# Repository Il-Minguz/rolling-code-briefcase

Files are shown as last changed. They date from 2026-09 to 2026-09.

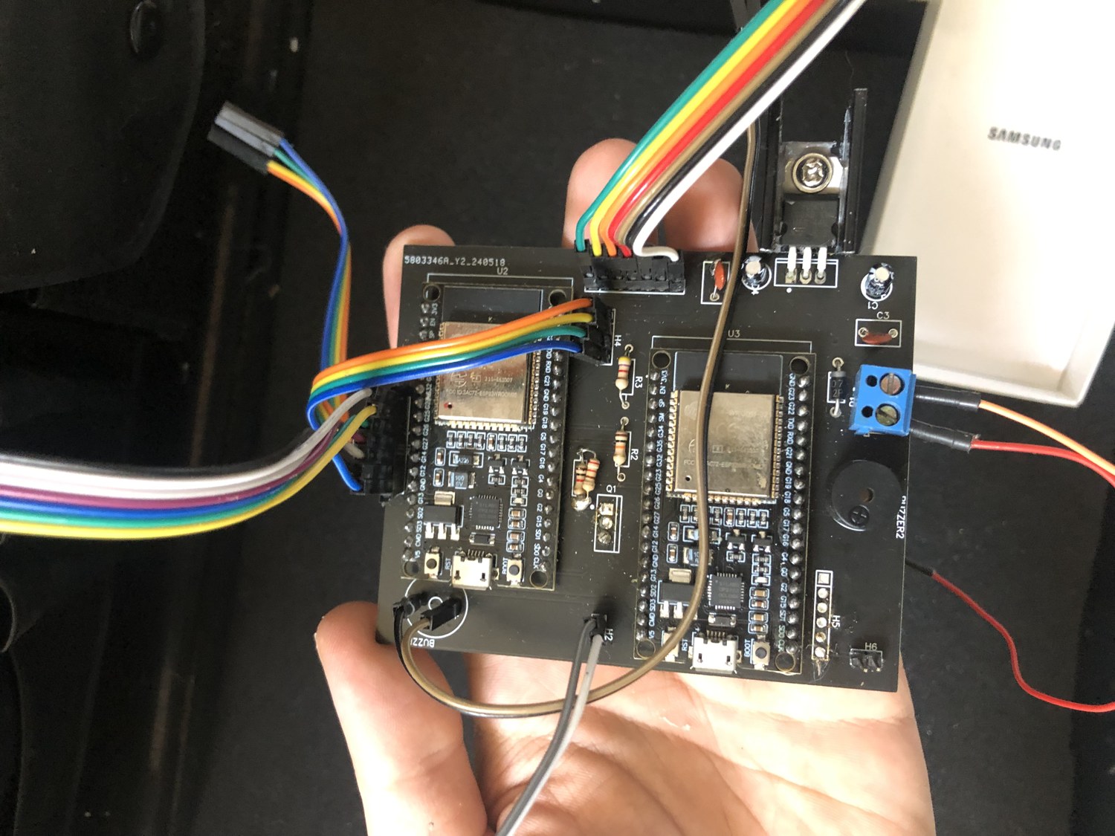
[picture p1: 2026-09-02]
hardware/pcb-v2-through-hole/photos/pcb-assembled.jpg

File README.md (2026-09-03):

# Rolling-Code Briefcase

An ESP32 briefcase that unlocks with a one-time code delivered over a 433 MHz LoRa link, or
with a fingerprint when the radio link goes down. Built as a final high-school project in
2024 — documented honestly in 2026, mistakes included.

---

## Overview - Work it harder 👷🏻‍♂️

This was one of my final high-school projects. Looking back at it today there are several
things I would design differently, but it was also the first time I combined embedded
programming, wireless communication, biometrics, PCB design and hardware debugging into a
single system that had to actually work in front of an examination board.

The system is made of two physical units:

- **The briefcase.** An aluminium case containing two ESP32s on a custom PCB, a 4×3 keypad, an
  SH1106 OLED, a GROW R557 capacitive fingerprint sensor behind a key-operated switch, an
  EBYTE E32-433T30D LoRa module, two buzzers and a solenoid lock.
- **The code transmitter.** A separate metal box with a third ESP32, a 16×2 I²C LCD and a
  second E32-433T30D. It generates a new 5-digit code every time the briefcase is opened and
  displays it.

Enter the code shown on the transmitter, press `#`, the case opens and a fresh code is
generated. Walk out of radio range and the keypad goes dead: the OLED tells you to use the
fingerprint sensor instead, which only works once you have turned a physical key.

This repository is **not** a build guide for a secure product. It is a record of what I built with the knowledge available at the time, what actually worked, what did not.

> [!WARNING]
> **Do not use this to secure anything.** The unlock code is transmitted in clear text on a
> default LoRa address and channel, there is no attempt limit, and the radio module is
> configured for 1 W of output power, which is far above what is legal in the 433 MHz band in
> Europe. Details in [Security](#security-honestly) and [Disclaimer](#disclaimer).

---

## 📖 Table of Contents

*(There is toooooo much to scroll here click around instead.)*

- [Overview](#overview)
- [Background](#background)
- [Inspiration](#inspiration)
- [Features](#features)
- [System Architecture](#system-architecture)
  - [Data flow, as implemented](#data-flow-as-implemented)
- [Hardware](#hardware)
  - [Pin mapping](#pin-mapping)
- [Software](#software)
  - [Why three microcontrollers](#why-three-microcontrollers)
- [Authentication System](#authentication-system)
  - [Security, honestly](#security-honestly)
- [Wireless Communication](#wireless-communication)
  - [Correction: the frequency was 433.0 MHz, not 450 MHz](#correction-the-frequency-was-4330-mhz-not-450-mhz)
  - [Correction: the −148 dBm figure does not apply](#correction-the-148-dbm-figure-does-not-apply)
  - [Protocol](#protocol)
  - [The data structure — and the bug that never went off](#the-data-structure--and-the-bug-that-never-went-off)
  - [And a second one: no framing](#and-a-second-one-no-framing)
- [Range: what the report claimed, and what actually happened](#range-what-the-report-claimed-and-what-actually-happened)
  - [About the test table in the report](#about-the-test-table-in-the-report)
  - [Range was never the binding constraint](#range-was-never-the-binding-constraint)
  - [The failure shape is the clue](#the-failure-shape-is-the-clue)
  - [The other strong candidate: the radio was probably never transmitting 1 W](#the-other-strong-candidate-the-radio-was-probably-never-transmitting-1-w)
  - [Ranked, then](#ranked-then)
  - [The distinction I got wrong](#the-distinction-i-got-wrong)
- [Lock Control](#lock-control)
  - [Why the base drive could not work](#why-the-base-drive-could-not-work)
  - [The power supply was wrong too](#the-power-supply-was-wrong-too)
  - [What the lock actually ran on, in the end](#what-the-lock-actually-ran-on-in-the-end)
- [Original Workarounds](#original-workarounds)
  - [LED + photoresistor optocoupler](#led--photoresistor-optocoupler)
  - [Others](#others)
- [Power System](#power-system)
- [Custom PCB](#custom-pcb)
- [Known Issues and Limitations](#known-issues-and-limitations)
  - [On the fingerprint sensor "binding itself" to one ESP32](#on-the-fingerprint-sensor-binding-itself-to-one-esp32)
- [What I Would Do Differently Today](#what-i-would-do-differently-today)
- [Lessons Learned](#lessons-learned)
- [Repository Structure](#repository-structure)
- [How to Reproduce or Experiment with the Project](#how-to-reproduce-or-experiment-with-the-project)
- [Disclaimer](#disclaimer)
- [Credits and Inspiration](#credits-and-inspiration)
- [License](#license)

---
## Background

Italian high schools end with the *Esame di Stato*, and technical institutes expect (in 2024) a personal
project alongside the written exams. I wanted something that touched the disciplines that are the most interesting such as radio, embedded firmware, power electronics
and a board I had designed myself.

The case itself is my father's old aluminium attaché case, the kind with a three-digit
mechanical combination lock on the lid. That lock is still there and still works — everything
in this repository was added around it.

The original report is preserved, unedited, in
[`docs/original-report/`](docs/original-report/). It is in Italian, it is 33 pages long, and
parts of it are wrong. Rather than quietly correcting it, I have kept it as it was and written
[`docs/ORIGINAL_REPORT_REVIEW.md`](docs/ORIGINAL_REPORT_REVIEW.md), which goes through its
claims one by one and marks each as confirmed, imprecise, or wrong.

---

## Inspiration

The original idea came from this YouTube short:

**https://www.youtube.com/shorts/WOgwcFSCKto**

That video is where the concept of a remotely controlled locking case came from, and it
deserves the credit for the spark. It used an NRF24-based link and a
large LiPo pack of the kind used in airsoft replicas. My implementation went a different way
almost immediately: ESP32s instead of an arduino nano, EBYTE LoRa modules instead of NRF24, plus
biometric authentication and a custom PCB.

**What I was actually imagining** (to Make it better 💻🔨)

The honest answer to "why a briefcase" is that I was picturing something out of a spy film: a courier case carrying documents that must not be read,
which opens only for the right person, reports back the moment it is opened, and whose code changes every single time so that yesterday's code is worth nothing. 
An agency handler at one end, a courier at the other, and a radio link between them.

Nobody needed this. There were no classified documents. But that image is the reason every design decision felt obvious at the time — of course the code has to roll, 
of course the case has to report the moment it opens, of course there has to be a fallback for when the link is gone, of course there is a key.

I mention it because the fiction did real work. A vague brief — "build something with a microcontroller" — gets you a demo. 
A specific imagined scenario gives you requirements, and requirements are what let you tell a finished feature from an unfinished one.

---

## Features

- Rolling 5-digit unlock code, regenerated on every successful opening.
- 433 MHz point-to-point LoRa link between the case and a handheld code transmitter.
- Automatic fallback to fingerprint authentication when the radio link is lost for 7 seconds.
- A physical key switch that powers the fingerprint sensor, acting as a mechanical second factor.
- OLED feedback on the case, LCD display of the current code on the transmitter.
- Audible feedback: a click on every keypress, a rising tune on success, a falling one on failure.
- A custom two-layer PCB carrying both of the briefcase's ESP32s.

---

## System Architecture

```mermaid
flowchart LR
    User([User])

    subgraph TX["Code transmitter — metal box"]
        ESP32_C["ESP32 C<br>password_definitivo.ino"]
        LCD["LCD 1602 I²C<br>shows current code"]
        LORA_C["E32-433T30D"]
        ESP32_C -- I2C --> LCD
        ESP32_C -- "UART2 · 9600" --> LORA_C
    end

    subgraph CASE["Briefcase — aluminium case"]
        ESP32_A["ESP32 A — main controller<br>valigia_definitivo.ino"]
        ESP32_B["ESP32 B — fingerprint / audio<br>impronte_definitivo.ino"]
        KEYPAD["Keypad 4x3"]
        OLED["OLED SH1106 I²C"]
        LORA_A["E32-433T30D"]
        FP["GROW R557<br>fingerprint sensor"]
        KEYSW["Key switch<br>powers the sensor"]
        DRIVER["BDX53C Darlington<br>+ LED/LDR workaround"]
        LOCK["Solenoid lock<br>1.7 A @ 9 V"]

        KEYPAD --> ESP32_A
        ESP32_A -- I2C --> OLED
        ESP32_A -- "UART2 · 9600" --> LORA_A
        ESP32_A -- "GPIO19 · unlock + happy tune" --> ESP32_B
        ESP32_A -- "GPIO2 · wrong code" --> ESP32_B
        ESP32_B -- "GPIO27 to GPIO34 · fingerprint OK" --> ESP32_A
        ESP32_B -- "UART2 · 57600" --> FP
        KEYSW -. "supplies power" .-> FP
        ESP32_A -- GPIO19 --> DRIVER --> LOCK
    end

    User --> KEYPAD
    User --> FP
    User --> KEYSW
    LORA_C <-. "433.0 MHz · 2.4 kbps<br>transparent · no ACK" .-> LORA_A
```

### Data flow, as implemented

```mermaid
sequenceDiagram
    participant TX as Transmitter (ESP32 C)
    participant CASE as Briefcase (ESP32 A)
    participant FPU as Fingerprint MCU (ESP32 B)

    loop every 5 s
        TX->>CASE: DATA{aperto, passwordTX, connesso=true}
        Note over CASE: Last = millis()<br>link considered alive
    end

    Note over CASE: user types code, presses #
    alt code matches
        CASE->>FPU: GPIO19 high (1 s)
        Note over CASE: OLED "Welcome Mr Minguzzi"<br>lock energised by the same pin
        FPU-->>FPU: play success tune
        CASE->>TX: DATA{aperto = true}
        TX->>TX: generate new 5-digit code
        TX->>CASE: DATA{passwordTX = new code}
        Note over TX: new code shown on LCD
    else code does not match
        CASE->>FPU: GPIO2 high (500 ms)
        Note over CASE: OLED "INCORRECT PASSWORD"<br>no attempt counter, no lockout
    end

    Note over CASE: no packet for 7 s
    CASE->>CASE: keypad disabled, OLED "LOST CONNECTION"
    Note over FPU: user turns the physical key → sensor powered
    FPU->>CASE: GPIO27 high on fingerprint match
    CASE->>CASE: lock energised for 1 s
```

There is **no acknowledgement and no retry anywhere in this diagram**. If the "case opened"
packet is lost, the transmitter never generates a new code, the briefcase keeps the old one,
and neither side notices.

---

## Hardware

Full detail in [`docs/HARDWARE.md`](docs/HARDWARE.md); parts list in
[`docs/BOM.md`](docs/BOM.md).

| Function | Part | Notes |
|---|---|---|
| Microcontrollers | 3 × ESP32-WROOM-32 dev boards | Two in the case (on one custom PCB), one in the transmitter |
| Radio | 2 × EBYTE E32-433T30D | SX1278, 1 W, UART transparent mode |
| Fingerprint | GROW R557 | Capacitive, 3.3 V UART, RGB ring, ~120 templates |
| Case display | SH1106 OLED 128×64, I²C `0x3C` | |
| Transmitter display | LCD 1602 + PCF8574 backpack, I²C `0x27` | |
| Input | 4×3 matrix keypad | `1-9`, `*`, `0`, `#` |
| Lock driver | BDX53C Darlington, TO-220 | 100 V, 8 A, integrated base resistors + freewheel diode |
| Regulator | LM7805 + 100 nF / 10 µF, heatsink | One per unit |
| Power | 9 V 6F22 battery per unit | Zinc-carbon in the surviving photos |
| Lock | Solenoid, **1.7 A at 9 V** (measured on a bench supply) | Separately powered |

### Pin mapping

**ESP32 "A" — briefcase main controller**

| Function | GPIO |
|---|---|
| Keypad rows R1–R4 | 33, 25, 26, 27 |
| Keypad columns C1–C3 | 14, 12, 13 |
| OLED I²C (SDA / SCL) | 21 / 22 |
| Buzzer | 15 |
| LoRa UART2 RX / TX | 16 / 17 |
| LoRa M0 / M1 / AUX | 4 / 23 / 5 |
| Unlock + "success" line to ESP32 B | 19 |
| "Wrong code" line to ESP32 B | 2 |
| "Fingerprint OK" line from ESP32 B | 34 (input only) |

**ESP32 "B" — fingerprint and audio**

| Function | GPIO |
|---|---|
| R557 UART2 RX / TX @ 57600 | 16 / 17 (defaults) |
| Buzzer | 5 |
| "Success" input from A | 33 |
| "Wrong code" input from A | 25 |
| "Fingerprint OK" output to A | 27 |

**ESP32 "C" — code transmitter**

| Function | GPIO |
|---|---|
| LCD I²C (SDA / SCL) | 21 / 22 |
| LoRa UART2 RX / TX | 16 / 17 |
| LoRa M0 / M1 / AUX | 4 / 18 / 19 |

> The row/column assignment above is the combination that **worked with the harness as it was
> wired**. It is not a claim about which physical wire on the keypad connector is "row 1" —
> the harness reordered them, which is exactly why this took me so long to get right in 2024.

---

## Software (Do it faster⚡️)

Full detail in [`docs/SOFTWARE.md`](docs/SOFTWARE.md).

Three Arduino sketches, preserved with their original Italian filenames and comments:

| File | Runs on | Role |
|---|---|---|
| `firmware/valigia_definitivo.ino` | ESP32 A | Keypad, OLED, LoRa RX/TX, lock, state machine |
| `firmware/impronte_definitivo.ino` | ESP32 B | Fingerprint polling, buzzer tunes |
| `firmware/password_definitivo.ino` | ESP32 C | Code generation, LCD, LoRa beacon |

Libraries: `EBYTE` (Kris Kasprzak), `Adafruit_Fingerprint`, `Keypad`, `ezBuzzer`,
`Adafruit_GFX`, `Adafruit_SH110X`, `LiquidCrystal_I2C`.

### Why three microcontrollers

I remembered the reason as "the ESP32 does not have enough UARTs". Reconstructing it from the
code, the truth is more specific and more interesting.

The ESP32 has **three** hardware UARTs. UART0 is taken by the USB-serial bridge for
programming and debugging. UART2 was used for the LoRa module. UART1 looks unavailable,
because **its default pins (GPIO 9/10) are wired to the internal SPI flash on a WROOM
module** — open it as-is and the chip stops. On top of that, AVR-style `SoftwareSerial` does
not work on the ESP32, so the obvious escape hatch was not there either.

So the fingerprint sensor got its own ESP32.

What I did not know is that **the ESP32's UART pins are remappable through the GPIO matrix**:

```cpp
Serial1.begin(57600, SERIAL_8N1, /*RX=*/26, /*TX=*/27);
```

One line, and the second microcontroller would not have been needed. The limitation was my
understanding of the peripheral, not the peripheral.

---

## Authentication System

Two mutually exclusive paths, selected by the state of the radio link.

**Keypad path (link alive).** The transmitter generates five digits with `random(10)`, shows
them on its LCD and sends them over the air. The briefcase stores them in a `String`. The user
types and confirms with `#`. `*` has no special meaning — it is simply appended to the input.
There is no delete key.

The initial value in the firmware is `String password = "1234";`, so **until the first packet
arrives, the case opens with 1234.**

**Fingerprint path (link lost for more than 7 s).** The keypad handler is skipped entirely.
ESP32 B polls the R557 every 100 ms with `getImage()` → `image2Tz()` → `fingerSearch()` and
raises GPIO27 on a match.

The sensor is only powered once the user turns a physical key. **This is not implemented in
firmware at all** — neither sketch reads a key pin. The key switch is wired in series with the
sensor's supply, so with the key out the R557 is simply unpowered and `getImage()` never
returns anything. It is a genuine second factor, and it is entirely mechanical.

### Security, honestly

This is just an high school project. It is **NOT** a secure device and here's why:

1. **The code space is 10⁵ (Clearly not a huge problem) and there is no attempt limit, no delay and no lockout.** At roughly
   one attempt per second that is about 28 hours worst case, 14 on average.
2. **The code travels in clear text.** The E32 modules run in transparent mode on address
   `0x0000` and channel 23 — all factory defaults. Anyone within range with an unconfigured
   E32 receives it.
3. **The code is displayed permanently on an LCD** on the outside of the transmitter box.
   But It suppose to be held somewhere secure like your house or in a gov building.
5. **The attacker picks which path to attack, and can force the fallback.** The two paths are
   not equally strong, and losing the link is trivial to cause — walk away with the case, or
   jam the channel. Whichever path is weaker is the system's real strength. The fallback path
   is not weak in itself: it needs a registered finger *and* the physical key, which is two
   factors. The keypad path needs one thing: the code, which is displayed on an LCD and
   broadcast in clear. **The keypad path is the weak one**, which is the opposite of what I
   assumed while building it.
6. `random()` on arduino-esp32 is backed by `esp_random()` rather than the AVR seeded PRNG,
   but ESP-IDF states that its output is only truly random when the RF subsystem (Wi-Fi or
   Bluetooth) is active or the ADC entropy source is enabled. Neither is the case here, so
   the output "should be considered as pseudo-random only".
7. A solenoid inside a thin aluminium case means physical security dominates anyway.

   But keep in mind, this isn't a major issue, just a project, I just wanted to let you know what you can do better with it.

---

## Wireless Communication

The E32 configuration is recoverable exactly, because a screenshot of EBYTE's configuration
tool survived in the original report showing `Param Now: 0x00, 0x00, 0x1a, 0x17, 0x44`. Those
are the ADDH, ADDL, SPED, CHAN and OPTION registers:

| Register | Value | Meaning |
|---|---|---|
| ADDH / ADDL | `0x00 0x00` | Address 0 (factory default) |
| SPED | `0x1A` | 8N1 · UART 9600 bps · **air data rate 2.4 kbps** |
| CHAN | `0x17` | **Channel 23 decimal** |
| OPTION | `0x44` | **Transparent** mode · push-pull IO · WOR 250 ms · **FEC on** · **30 dBm (1 W)** |

### Correction: the frequency was 433.0 MHz, not 450 MHz

The original report states that channel 17 gives 433 + 17 = 450 MHz. Both halves are wrong.

The E32 channel formula is **410 MHz + CHAN × 1 MHz**, not 433 + CHAN. And the channel was not
17: `0x17` **is** 23 in decimal, which is the module's factory default. So the real operating
frequency was **410 + 23 = 433.0 MHz** — exactly what the same screenshot reports as
`Freq Now: 433.0MHz`. The "17" came from reading a hexadecimal value as a decimal one.

This matters practically: the EBYTE manual explicitly recommends avoiding crowded integer
frequencies such as 433.0 MHz. The system was sitting in the busiest slice of the band,
alongside gate remotes, weather stations and car keys.

### Correction: the −148 dBm figure does not apply

The report quotes the module's −148 dBm sensitivity. That number is measured at **0.3 kbps
with SF12 and CR 4/5**, as the datasheet states. At the 2.4 kbps this project actually ran,
sensitivity is meaningfully worse. It does not change the conclusions below, but the figure
was quoted out of context.

### Protocol

There is no protocol, in the sense that word usually means. The `EBYTE` library's
`SendStruct()` is a raw `Stream::write()` of the struct's bytes, and `GetStruct()` is a
`Stream::readBytes()` of the same length. Both wait for the module's AUX pin. That is all.

- **No acknowledgement.** None in the library, none in my code.
- **No retries.**
- **No sequence numbers, no message type, no length field, no application CRC.** The E32's
  FEC is internal and invisible to the firmware.
- **The return values of `SendStruct()` and `GetStruct()` are never checked.**

The only reliability mechanism is a 5-second beacon and a 7-second timeout.

### The data structure — and the bug that never went off

```cpp
struct DATA {
  bool aperto;
  String passwordTX;
  bool connesso;
};
```

On the ESP32 this is **24 bytes** (1 + 3 padding + 16 for the `String` + 1 + 3 padding), well
under the module's 58-byte sub-packet limit. My instinct that these structures were "heavy"
turns out not to be supported by the numbers.

The real problem is different, and worse. An Arduino `String` is not a character array — it is
an object that, for longer strings, holds *a pointer into the heap*. `SendStruct` memcpy's the
object. Transmitting a pointer and dereferencing it on a different machine is undefined
behaviour.

It worked anyway, because arduino-esp32's `String` implements small-string optimisation:

```cpp
struct _ptr { char *buff; uint32_t cap; uint32_t len; };   // 12 bytes
enum { SSOSIZE = sizeof(struct _ptr) + 4 - 1 };            // 15
struct _sso { char buff[SSOSIZE]; unsigned char len:7, isSSO:1; };
union { struct _ptr ptr; struct _sso sso; };
```

Up to **11 characters** live *inside* the object. My password is five digits, so the actual
characters travelled inside the struct and everything worked — **by luck, not by design**.

A 12-character password would have moved the buffer to the heap, and the receiver would have
been handed a pointer into the *sender's* address space. The same code on a core without SSO
would never have worked at all. This is my favourite bug in the whole project: it is not a
beginner's mistake, it is a class of bug that shows up in professional code, and the only
reason it never bit me is an implementation detail I did not know existed.

### And a second one: no framing

```cpp
if (Serial2.available()) {                          // one byte is enough to enter
  Transceiver.GetStruct(&MyData, sizeof(MyData));   // but 24 are demanded
```

`available() >= 1` does not mean 24 bytes are waiting. `readBytes` blocks up to the Stream's
1000 ms timeout and returns however many it got — a value that is then discarded. A short read
leaves the struct half-updated and, worse, **leaves the byte stream permanently misaligned**:
every subsequent read starts mid-packet until a long enough gap resynchronises it by accident.

---

## Range: what the report claimed, and what actually happened

The original report mentioned a range of approximately one kilometre. **This was not confirmed
by my real-world tests.** In everyday use the link was solid, and then at somewhere around
**400 metres** it dropped — and stayed dropped.

### About the test table in the report

The report contains this table:

| Distance | "Quality" |
|---|---|
| 50 m | 95 % |
| 100 m | 79 % |
| 400 m | 70 % |
| 1000 m | 62 % |

**I do not stand behind these numbers, and neither should you.** They come from a single
unrepeated walk through town — transmitter left at home, walking away, counting successes out
of at least ten received beacons, roughly line of sight. One run, one day, one route, no
control of any variable. It was presented in the report as if it characterised the system. It
does not.

I am leaving it here because it is what the report says and because deleting inconvenient data
is exactly the habit this repository exists to correct. But the honest summary is: **the only
range figure I trust is my own repeated experience, which is that it worked reliably and then
stopped at roughly 400 m.**

### Range was never the binding constraint

```
FSPL(433 MHz, 1 km) = 20·log₁₀(1) + 20·log₁₀(433) + 32.44 ≈ 85.2 dB
P_rx ≈ 30 dBm + ~2 dBi + ~2 dBi − 85.2 dB ≈ −51 dBm
sensitivity at 2.4 kbps ≈ −140 dBm (estimated — the datasheet's −147 dBm figure is for 0.3 kbps)
margin ≈ 89 dB
```

Even allowing for a two-ray ground-reflection model, which past a breakpoint of a few metres
makes path loss grow as d⁴ rather than d², the budget at 400 m still leaves tens of decibels of
margin. **With a healthy 1 W link and both antennas outside their metal enclosures, a hard
limit at 400 m is not something propagation explains.**

### The failure shape is the clue

Here is what changed my mind about this two years later. A genuine range limit does not fail
the way I remember this failing.

- **A range limit is soft and reversible.** As you approach the edge you get intermittent
  losses; step back towards the transmitter and it recovers. You can walk it back and forth
  across the boundary.
- **What I actually remember is a cliff that stays.** It worked, then it dropped, and it did
  not come back.

That second shape is the signature of the framing bug, not of a radio limit. Because
`GetStruct` reads a fixed 24 bytes whenever a single byte is available, **the first corrupted
or truncated packet leaves the byte stream permanently misaligned** — every subsequent read
starts mid-packet, and it only recovers if a long enough silence happens to resynchronise it.
So the first packet lost at the edge of usable range does not cost you one beacon. It costs
you the link.

That reframes the whole thing: distance was the *trigger*, but the reason the system fell over
and stayed down was in the receive loop, not in the air.

### The other strong candidate: the radio was probably never transmitting 1 W

The E32-433T30D draws **570–670 mA** while transmitting. On the transmitter that current came
from a 9 V zinc-carbon 6F22 through an LM7805 — a cell with an internal resistance of several
ohms. The EBYTE datasheet states plainly that "the transmitting power will be lowered by
lowering the power supply voltage."

This one is worth quantifying, because in free space range scales with the square root of
power:

```
−20 dB of transmit power  →  10× less range
```

If supply sag put the effective output at 10–14 dBm instead of 30, the usable distance
collapses by roughly an order of magnitude. That is more than enough to turn a link that
should have reached kilometres into one that gave up at hundreds of metres — and it is
consistent with the report's other unexplained symptom, intermittent disconnections "for no
apparent reason".

### Ranked, then

1. **Permanent stream desynchronisation** (`GetStruct` with no framing) — explains the *shape*
   of the failure, and why it did not recover.
2. **Reduced effective transmit power** from supply sag during transmit bursts — explains why
   the edge arrived so early.
3. **No ACK, no retry** — one lost packet is never recovered, so nothing papers over 1 or 2.
4. **Channel 23 = exactly 433.0 MHz**, the most congested slice of the band, which the manual
   itself says to avoid.
5. **Quarter-wave monopoles with no proper ground plane** — real efficiency well below the
   textbook figure.

Antenna shielding is *not* on this list: both antennas were mounted outside their metal
enclosures on SMA connectors.

### The distinction I got wrong

I used to assume that a large data structure had reduced my radio range. It does not work that
way:

| Concept | What it is | Affected by payload size? |
|---|---|---|
| Theoretical range | Distance at which the signal is still above sensitivity | No |
| Receiver sensitivity | Minimum demodulable power; set by SF/BW/CR, i.e. air data rate | No |
| Airtime | How long the channel is occupied = f(payload, data rate) | **Yes, linearly** |
| Payload size | Useful bytes | — |
| Data rate | Bits/s on air; **higher rate = worse sensitivity = less range** | No |
| Error probability | Chance at least one symbol is corrupted; grows with symbol count | **Yes, weakly** |
| Retransmissions | Recover lost packets, cost airtime | Indirectly |
| Perceived reliability | What the user sees = f(error probability, retries, timeouts) | Yes, via the above |

**Packet size drives airtime, duty cycle and — weakly — error probability. It does not set
range**, which is fixed by the link budget: transmit power, antennas, path loss and receiver
sensitivity. And 24 bytes out of an available 58 was never going to be the problem.

---

## Lock Control

This is where the project genuinely did not work, and the reason is not the one I remembered.

The solenoid draws **1.7 A at 9 V** — measured with a bench supply. It was driven by a BDX53C
Darlington on ESP32 A's GPIO19, through a base resistor found empirically at 1 kΩ.

### Why the base drive could not work

The BDX53C is guaranteed **hFE ≥ 750** at Vce = 3 V, Ic = 3 A, and contains internal
base-emitter resistors (R1 ≈ 8.4 kΩ, R2 ≈ 0.3 kΩ). With a 3.3 V GPIO through 1 kΩ, and a
Darlington Vbe of roughly 1.6 V:

```
I_base(total) ≈ (3.3 − 1.6) / 1000        ≈ 1.7 mA
minus the internal divider   1.6 / 8.7 kΩ ≈ 0.18 mA
I_base(useful)                            ≈ 1.5 mA

required β = 1.7 A / 1.5 mA ≈ 1130   vs   750 guaranteed
```

**The transistor could not saturate.** It sat in the linear region, dropped several volts,
dissipated watts, and the solenoid never got enough.

And no resistor value fixes this, which is the part I did not understand at the time. **A
Darlington has two stacked base-emitter junctions.** The datasheet allows Vbe(sat) up to
**2.5 V** at high current. Out of a 3.3 V rail that leaves under a volt of headroom to push
base current through. A Darlington is simply the wrong device to hang off a 3.3 V GPIO.

Fitting a 0 Ω base resistor — which I tried — does not solve it either. It violates the
ESP32's 40 mA absolute maximum per pin, drags the GPIO output voltage down, and leaves the
underlying headroom problem exactly where it was.

### The power supply was wrong too 

My current suspicion that the regulator was the problem is **correct, but it is the second
half of the story, not the whole of it**:

- An LM7805 in TO-220 is rated **1.5 A maximum** with adequate heatsinking. Not 1.7 A.
- 9 V → 5 V at 1.5 A is **6 W** to dissipate. The small heatsink in the photos would have gone
  into thermal shutdown.
- The 9 V battery in the surviving photos is a **VARTA Super Heavy Duty**, i.e. **zinc-carbon**,
  with an internal resistance on the order of ohms. At 1.7 A the terminal voltage collapses. It
  is not a capacity problem, it is a **power delivery** problem: that chemistry physically
  cannot source that current.

So there were **two independent causes, each sufficient on its own.** I would now debug them
in that order: base drive first, because it fails even into a resistive dummy load, then the
supply.

### What the lock actually ran on, in the end

Not the 9 V rail. In the final working configuration the lock circuit was fed from **an 18 V
cordless-drill battery pack**, wired in as a stopgap and never replaced.

That single fact explains a lot, and none of it is flattering:

- **It is roughly double the solenoid's working voltage.** At 9 V the coil drew 1.7 A; at 18 V,
  for a largely resistive coil, that is on the order of 3.4 A and **four times the power**. The
  coil is dissipating something like 60 W while energised. It survived because it was only ever
  energised for a second at a time, a handful of times. Held on continuously it would have
  cooked, and the part most at risk was the solenoid, not the transistor.
- **The Darlington was over-dissipating too.** At ~3.4 A with a couple of volts across it,
  that is well over 5 W in a TO-220 that had no heatsink on it.
- **But it is also why the workaround worked.** See below — the 18 V rail is what finally gave
  the base circuit enough headroom.

A drill pack is a genuinely sensible thing to grab when you need current *right now*: it is a
5-cell Li-ion pack with milliohms of internal resistance, which is the opposite of a 6F22 in
every way that mattered here. It was the right instinct applied without doing the arithmetic
first.

---

## Original Workarounds

### LED + photoresistor optocoupler

To get the system working for the exam I built this:

```
ESP32 GPIO ──► LED ──┐
                     │   (optical coupling, taped over)
                     ▼
 separate V+ ──[ LDR ]── B  BDX53C  C ── solenoid ── separate V+
                            E
                            └── GND (of the separate supply)
```

> *Prototype workaround used to isolate the ESP32 control signal from a separately powered
> lock-driving circuit.*

It is a hand-made optocoupler, and knowing what the real problem was, it is a smarter hack
than it looks. It does not "boost" anything — it **removes the 3.3 V GPIO from the base path
altogether.** The base current now comes from the lock's own supply through the LDR, and the
GPIO only has to light an LED at ~10 mA.

And with 18 V on that side rather than 3.3 V, the arithmetic finally works:

```
I_base ≈ (18 V − 1.6 V) / ~2 kΩ (illuminated LDR) ≈ 8 mA
required β = 3.4 A / 8 mA ≈ 425      vs   750 guaranteed
```

**That is the first time in this whole circuit that the transistor was actually being asked to
do something it could do.** Compare it with the original: 1.5 mA of base current demanding a β
of 1130 against a guaranteed 750.

So the LED and the photoresistor were not what fixed the lock. **The 18 V supply fixed the
lock**, by giving the base circuit voltage headroom it never had from a 3.3 V pin — and the
optical coupling was simply the mechanism that let an 18 V base circuit be switched by a 3.3 V
microcontroller. Understanding that took me two years, and it is the single thing in this
project I most wish I had worked out at the time.

It is still not something to design in today:

- LDR response times are tens to hundreds of milliseconds, and **asymmetric** — rise is much
  slower than fall.
- LDR resistance drifts with temperature and with recent light history (light memory effect).
- The transfer ratio is specified nowhere. It cannot be designed, only tuned by trial.
- **Ambient light can partially turn the lock on** if the shielding is imperfect. On a lock,
  that is a security problem, not just a reliability one.
- It has no rated isolation voltage, so it is not actually isolation.
- Many LDRs contain cadmium sulphide and are RoHS-restricted.

A real optocoupler (PC817, TLP291) costs about €0.20, switches in microseconds and has a
specified current transfer ratio.

### Others

- **A 0 Ω base resistor**, tried when the 1 kΩ did not work. See above for why it made things worse.
- **One GPIO doing two jobs.** GPIO19 both energises the lock circuit and tells the second
  ESP32 to play the success tune. It works, but it couples an actuator to a UI signal: you
  cannot change one without thinking about the other.
- **A separate microcontroller instead of remapping a UART.** See [Software](#software).

---

## Power System (Makes us stronger 💪)

| | Briefcase | Transmitter |
|---|---|---|
| Source | 9 V 6F22 | 9 V 6F22 (zinc-carbon) |
| Regulator | LM7805 + 100 nF / 10 µF + heatsink | Same |
| Loads | 2 × ESP32, OLED, R557, E32 (RX + TX bursts), 2 buzzers, panel voltmeter | ESP32, LCD, E32 (RX + TX bursts) |
| Remembered draw | ~300 mA | ~150 mA |

Those remembered figures are plausible: an ESP32-WROOM with the radio off at 240 MHz sits
around 40–70 mA, so two of them plus a display, buzzers and a receiving E32 lands comfortably
in the 250–300 mA range.

Power management was, honestly, not considered at all. A rectangular 9 V battery is close to
the worst possible choice here, for three separate reasons that are worth separating:

1. **Capacity.** A 9 V alkaline gives ~550 mAh *at a few milliamps*. Usable capacity collapses
   as current rises, and a zinc-carbon cell is far worse.
2. **Internal resistance.** A 6F22 is six tiny cells in series with a small electrode area and
   an internal resistance of several ohms. The E32's 610 mA transmit burst drags its terminal
   voltage down every time the radio speaks. This is a *power* limit, not an energy one.
3. **The linear regulator throws the difference away.** At 300 mA the LM7805 burns
   (9 − 5) × 0.3 = **1.2 W** out of about 2.7 W drawn from the battery — over 44 % of the
   energy becomes heat before it powers anything.

Order-of-magnitude runtime: ~4.5 Wh nominal at light load against ~2.7 W gives about 1.7 hours
in the ideal case, and well under an hour in practice with the cells that were actually
fitted, with the voltage sagging the whole time.

The report describes an intermittent loss of connection "with no apparent reason". The most
likely explanation is here: **brownouts during transmit bursts**, either reducing RF output,
tripping the brownout detector, or corrupting UART bytes during the transient — which, per the
framing bug above, desynchronises the link permanently.

---

## Custom PCB

Two revisions, designed in EasyEDA after moving over from KiCad.

**v1 — SMD.** Fully routed, never manufactured: the quote came back at over $120.

**v2 — through-hole.** The one that was built. Two layers, ground pour on both sides, both
briefcase ESP32s on one board, screw terminal for the lock, on-board buzzers, and headers for
the keypad, OLED, fingerprint sensor and LoRa module. **$2 for the boards plus $15 shipping.**
Silkscreen `5803346A_Y2_240518`, "Made by Minguz in Italy", and — following the tradition of
hiding something on the back of a board — a small stick figure pointing angrily at an insect,
captioned `LOOK, A BUG!`.

The choice of through-hole was driven purely by cost, and it turned out to have real
advantages for a student project: easy to solder, easy to rework, mechanically robust.

Known layout complaints from the original report: the USB connector sits too close to the
first buzzer, making it awkward to plug in a cable to reprogram the board.

---

## Known Issues and Limitations (More than ever (hour after hour) ⏱️)

Full list, with reasoning, in [`docs/KNOWN_ISSUES.md`](docs/KNOWN_ISSUES.md). 

### On the fingerprint sensor "binding itself" to one ESP32

I remembered the R557 as somehow becoming tied to the first ESP32 it was used with: after
that, moving it to another board seemed not to work.

**I do not think that is what happened, and this repository will not claim it is.** The R557
stores fingerprint templates in its *own* flash, so enrolment is portable across hosts by
construction — it cannot bind to a controller that way.

What the module *does* store in flash, and what would produce exactly this symptom:

- the **UART baud rate** (`SetSysPara`),
- the **4-byte handshake password** (`VfyPwd`),
- the **4-byte device address**.

Change any of those during experiments and a second host using library defaults fails to
handshake and appears dead. On top of that, the report notes the sensor was first tested with
an **Arduino Micro**, which drives 5 V logic — the R557's datasheet limit for its
communication lines is **3.6 V**. Sustained over-driving is a plausible way to degrade an
input.

The honest answer is that this needs a bench test to resolve, not a memory.

---

## What I Would Do Differently Today

Reasoning and part-selection detail in [`docs/REDESIGN.md`](docs/REDESIGN.md).

---

## Lessons Learned (Work is never over 😩🥱)

- **Pay attention to the shape of a failure, not just the fact of it.** A link that degrades is
  a radio problem. A link that drops and stays dropped is a software problem. I spent two years
  assuming the first because I never asked which one I was actually seeing.
- **Hex is not decimal.** `0x17` is 23. That single misreading put a wrong frequency in a
  document that was defended in front of an examination board.
- **Datasheet numbers come with test conditions.** −148 dBm is real, at 0.3 kbps. Quoting it
  next to a 2.4 kbps configuration is quoting a different device.
- **"It works" and "it is correct" are different claims.** The `String`-in-a-struct bug worked
  for two years because of an optimisation I did not know existed.
- **Debug the drive before the supply.** Base drive fails into a dummy load; supply problems
  need the real one. I spent a long time on the wrong half.
- **When a hack works, find out why.** The LED and photoresistor were never the fix — the 18 V
  supply behind them was.
- **Batteries have a power rating, not just a capacity.** This is the single most useful thing
  I took away from the whole project.
- **A workaround you can explain is worth keeping.** The LED and photoresistor got the project
  through the exam, and once I understood *why* it worked, it stopped being embarrassing and
  became the clearest illustration of what the real fault was.

---

## Repository Structure

```
.
├── README.md
├── LICENSE
├── firmware/
│   ├── valigia_definitivo.ino          # ESP32 A — briefcase main controller
│   ├── impronte_definitivo.ino         # ESP32 B — fingerprint + audio
│   └── password_definitivo.ino         # ESP32 C — code transmitter
├── hardware/
│   ├── pcb-v2-through-hole/            # gerbers, renders, photos (the board that was built)
│   ├── pcb-v1-smd/                     # renders only, never manufactured
│   └── schematics/                     # power supply, lock driver
├── docs/
│   ├── HARDWARE.md
│   ├── SOFTWARE.md
│   ├── KNOWN_ISSUES.md
│   ├── REDESIGN.md
│   ├── BOM.md
│   ├── ORIGINAL_REPORT_REVIEW.md
│   └── original-report/                # the 2024 report, unedited, in Italian
└── media/
    ├── photos/
    └── videos/
```

The sketches keep their original Italian filenames and comments on purpose. This is a record
of what was built, not a tidied-up reconstruction.

---

## How to Reproduce or Experiment with the Project

You almost certainly should not build this as-is. But if you want to run parts of it:

**What you need:** Arduino IDE with the ESP32 board package; the libraries listed in
[Software](#software); at minimum two ESP32 dev boards and two E32-433T30D modules for the
radio half.

**Before powering anything:**

1. **Check your local radio regulations.** The firmware leaves the modules at 30 dBm. In
   Europe the 433.05–434.79 MHz band is limited to **10 mW ERP** for licence-free use — 20 dB
   below what this project transmits. Configure the modules to the lowest power setting
   (`21 dBm`, and lower via the config tool) or move to a band you are allowed to use.
2. **Do not power a solenoid from a 9 V battery through a 7805.** It will not work, and the
   regulator will go into thermal shutdown trying.
3. **Change `String password = "1234";`** before doing anything else.

**Suggested path if you want to learn from it rather than rebuild it:**

- Run only `password_definitivo.ino` and `valigia_definitivo.ino` on two dev boards with the
  radios, and watch the serial monitors. The link behaviour is the interesting part.
- Change the generated password length from 5 to 12 in `passwordGen()` and watch the
  small-string-optimisation bug appear. This is the most instructive ten minutes in the repo.
- Replace `GetStruct` with a framed reader (start byte, length, CRC) and re-run the range test.
  I would expect most of the loss floor to disappear.

---

## Disclaimer

This is an **experimental, educational project** built by a secondary-school student in 2024,
published as a record rather than as a design to copy. It is not a product, it is not
production-ready, and it is not secure.

Specifically:

- **It is not a security device.** See [Security, honestly](#security-honestly).
- **The radio configuration is not legal for licence-free use in Europe** at the power level
  the firmware leaves set.
- **The lock driving circuit did not work reliably** and, in its final form, relied on an
  improvised LED-and-photoresistor coupler.
- Mains voltages are not involved anywhere, but a solenoid drawing 1.7 A can get hot and can
  damage a supply that is not rated for it.

Everything here is provided as-is. If you use any of it, you are responsible for verifying it
against the datasheets of the parts you actually have and the regulations where you are.

---

## Credits and Inspiration

- **The original idea** came from this YouTube short:
  https://www.youtube.com/shorts/WOgwcFSCKto — the concept of a remotely controlled locking
  case is theirs; the implementation here went its own way.
- **EBYTE library** by **Kris Kasprzak**: https://github.com/KrisKasprzak/EBYTE — this is the
  library the project used for the E32 modules, and reading its source is what made the
  `SendStruct` / `GetStruct` behaviour clear enough to document properly.
- **Adafruit Fingerprint Sensor Library**, **Adafruit GFX** and **Adafruit SH110X**.
- **Keypad** by Mark Stanley and Alexander Brevig; **ezBuzzer** by ArduinoGetStarted.
- **EBYTE / Chengdu Ebyte Electronic Technology** for the E32 user manual, and **Hangzhou Grow
  Technology** for the R557 documentation — and, at the time, for actually answering an email
  from a confused student in Italy.
- My teachers and my friends, who spent more evenings on this than they had to.

---

## License

**MIT** for the firmware and the documentation — see [`LICENSE`](LICENSE). In short: anyone may
use, copy, modify and redistribute this, including commercially, provided they keep the
copyright notice and accept that it comes with no warranty.

The year in the notice is the year of authorship, not an expiry date. Copyright lasts for
decades regardless of what the file says, and the notice does not need updating every January.

The original school report in `docs/original-report/` is included as a historical document and
is not covered by the MIT grant.

---

🥚 If you noticed the easter egg hidden in the titles...
🤫 Shhh. Keep it secret.

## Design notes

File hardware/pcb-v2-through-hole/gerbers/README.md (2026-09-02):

# Gerbers — PCB revision 2 (through-hole)

**To be added.** The EasyEDA source project is no longer available, but the manufactured
Gerber set is downloadable from the JLCPCB order history:

> Orders → the order for this board → **Download Gerber**

Board identification: silkscreen `5803346A_Y2_240518`, two layers, ground pour on both faces.

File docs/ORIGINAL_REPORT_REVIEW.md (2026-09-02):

# A critical review of the original school report (and made entirely by AI (i'm lazy))

The 2024 report is preserved unedited in [`original-report/`](original-report/). It is in
Italian, 33 pages long, and it was written by a student with a deadline.

The original school report contained several assumptions and claims that were not fully
validated by real-world testing. This repository documents the project more critically and
transparently. This file goes through the report section by section and marks each substantive
claim as **correct**, **imprecise**, **unverifiable**, or **wrong**, with the evidence.

The point is not to embarrass a document I wrote. It is that a repository claiming to be
honest has to be checkable, and the fastest way to make it checkable is to show my working
against the primary source.

---

## Section 1 — "L'idea"

| Claim | Verdict | Notes |
|---|---|---|
| Keypad entry, buzzer feedback per keypress, second buzzer for the success tune | **Correct** | Matches the firmware exactly |
| A signal from an ESP32 activates the lock through a power transistor | **Correct** | GPIO19 → BDX53C |
| After opening, the case reports it over LoRa and receives a new code | **Correct** | Confirmed in both sketches |
| On link loss the keypad becomes unusable and the OLED tells the user to use the fingerprint | **Correct** | Confirmed |
| Module identified as "ebyte 433t30d" | **Correct** | |

Section 1 is accurate. It is a clear, honest description of what the system does.

---

## Section 2 — Block diagram and flowcharts

| Claim | Verdict | Notes |
|---|---|---|
| Keypad on 33, 25, 26, 27, 14, 12, 13 | **Correct** | Matches `pin_righe` / `pin_colonne` |
| OLED on 21, 22 | **Correct** | ESP32 I²C defaults |
| LoRa on 16, 17, 4, 23, 5 | **Correct** | Matches `PIN_RX/TX/M0/M1/AX` |
| Fingerprint sensor on 16, 17 "from the second ESP32" | **Correct** | `Serial2` defaults; excellent cross-check |
| Darlington on pin 19 | **Correct** | Same pin as `SUONO_OK` — see KNOWN_ISSUES C-19 |
| UART used for the fingerprint sensor and the LoRa modules | **Correct** | |
| I²C used for both displays | **Correct** | |
| Transmitter flowchart: "3 minutes elapsed?" → init timer → compute battery % → warn below 20 % | **Wrong** | The firmware uses a **5-second** timer and contains **no battery calculation** at all |
| Briefcase flowchart | **Correct** | Accurately describes the implemented state machine |

The briefcase flowchart is a genuinely good piece of documentation. The transmitter one
describes software that does not exist.

---

## Section 3 — Power supply

| Claim | Verdict | Notes |
|---|---|---|
| "A normal 9 V battery provides sufficient voltage to power all the components **for a prolonged time**" | **Wrong** | It cannot. See KNOWN_ISSUES C-16: several ohms of internal resistance against 610 mA transmit bursts, and capacity that collapses above a few tens of mA. The photographs show a **zinc-carbon** cell, which is the worst case |
| "These batteries are known for their **durability**" | **Wrong** | The opposite is true at these currents |
| LM7805 converts ~9 V to a stable 5 V ±0.1 V | **Correct** | |
| Purpose of the 10 µF and 100 nF capacitors, and placing them close to the regulator | **Correct** | Well explained, and good practice |
| A heatsink with thermal paste is needed because linear regulators produce heat | **Correct in principle** | But the report does not compute the dissipation. At 300 mA it is 1.2 W; at the lock's 1.7 A it would be 6.8 W, which no small heatsink handles |
| The power schematic is labelled **+12 V** at the regulator input | **Inconsistent** | The text and photographs both show a 9 V battery. Treat the label as a drawing artefact |
| A Darlington "is able to handle high currents, allowing the solenoid to be activated effectively and safely" | **Wrong in this context** | See below |

---

## Section 3.2 — The Darlington

| Claim | Verdict | Notes |
|---|---|---|
| A solenoid needs more current than a microcontroller pin can supply | **Correct** | |
| Darlington hFE is the product of the two stages, e.g. 100 × 100 = 10 000 | **Correct as theory** | But the BDX53C datasheet guarantees **hFE ≥ 750**, not 10 000 — and 750 is the number that matters for design |
| BDX53C: 100 V, 8 A, with protection resistors and a freewheel diode | **Correct** | Confirmed against the datasheet |
| "I preferred the empirical method for finding the right resistance. After various tests I discovered that the correct base resistance is 1 kΩ" | **Correct value, undocumented conditions** | 1 kΩ is roughly right when the base is fed from the lock's 18 V rail (≈16 mA, β needed ≈ 210). It cannot work from a 3.3 V GPIO (≈1.5 mA, β needed ≈ 1130 against 750 guaranteed). The report states the value without stating what it is measured across, which is precisely what makes an empirical result untransferable |
| Explanation of the freewheel diode and inductive kickback | **Correct** | Clearly and correctly explained |

The report never states the lock's current, and never mentions that in the working build the
lock circuit ran from a separate 18 V drill battery rather than the 9 V rail everything else is
described against. Those two omissions are what made the whole chapter unverifiable — including
to its author, two years later.

---

## Section 4 — The microcontroller

| Claim | Verdict | Notes |
|---|---|---|
| ESP32 dual-core up to 240 MHz, 12-bit SAR ADC, two 8-bit DACs, I²C and SPI | **Correct** | |
| ESP32 vs Arduino Uno comparison table | **Correct** | |
| "The ESP32's advanced energy management optimises consumption in battery-powered devices" | **Unverifiable, and not true of this build** | The feature exists; the project never used deep sleep, WOR or any load switching |
| "The only downside of the ESP32 is 3.3 V operation, which I managed to compensate for" | **Imprecise** | 3.3 V operation was not compensated for — it is exactly what broke the lock driver. The E32 and R557 are both **3.3 V** parts, so 3.3 V was an advantage there; the mistake was pairing a 3.3 V GPIO with a Darlington |

---

## Section 5 — The fingerprint sensor

| Claim | Verdict | Notes |
|---|---|---|
| R557 by Hangzhou Grow Technology; UART, 3.3 V TTL, 30 mA capture / 5 µA standby, 120 templates, <0.001 % FAR, <1 % FRR, 508 dpi, <0.2 s capture | **Correct** | Matches the manufacturer's manual |
| LED ring: red / green / blue status | **Correct** | Visible in the demonstration video |
| Losing the wireless link triggers the fingerprint path | **Correct** | |
| A physical key turn is required to activate the sensor | **Correct** | And the report is right that this is a real second measure. Worth adding: the firmware knows nothing about the key — it is purely a power interlock |
| First tested on an Arduino Micro, then integrated with an ESP32 | **Correct** | And relevant: the Micro is 5 V, the R557's lines are rated for 3.6 V maximum. See KNOWN_ISSUES N-1 |
| Long capacitive-vs-optical comparison | **Correct** | Good background, though it goes further than the project needs |

---

## Section 6 — The LoRa module

| Claim | Verdict | Notes |
|---|---|---|
| E32-433T30D based on the Semtech SX1278 | **Correct** | |
| LoRa uses chirp spread spectrum (CSS) | **Correct** | |
| "LoRa allows transmission over 10 km in rural areas, 3–5 km in dense urban areas" | **Correct as a general statement about the technology** | But it sits next to the project's own results without any reconciliation, which is what made the "one kilometre" claim feel supported |
| "Receiver sensitivity up to **−148 dBm**" | **Imprecise — quoted out of context** | That figure is measured at **0.3 kbps, SF12, CR 4/5**. The project ran at **2.4 kbps**, where the datasheet explicitly states sensitivity is reduced |
| The −148 dBm → 1.58 fW conversion | **Correct** | The arithmetic is right |
| "Channel 17, so 433 MHz + 17 MHz = **450 MHz**" | **Wrong, twice** | The E32 formula is **410 + CHAN**, not 433 + CHAN. And the channel was **not 17**: the report's own screenshot shows `0x17`, which **is 23 decimal** — the factory default. Real frequency: **410 + 23 = 433.0 MHz**, exactly as the same screenshot states (`Freq Now: 433.0MHz`). A hexadecimal value was read as decimal |
| Quarter-wave antenna ≈ 173 mm at 433 MHz | **Correct** | |
| Monopole radiation pattern description | **Correct** | |
| Configured via the EBYTE tool over an FTDI232 | **Correct** | And the screenshot is the single most valuable artefact in the whole report — the entire radio configuration is recoverable from it |
| "Unicast, point-to-point half duplex" | **Imprecise** | `OPTION = 0x44` bit 7 = 0 means **transparent** mode, not fixed/addressed mode. On address 0 with a default channel, any E32 in range receives the traffic. "Half duplex" is correct |

### What the screenshot actually proves

`Param Now: 0x00, 0x00, 0x1a, 0x17, 0x44` decodes as:

| Register | Value | Meaning |
|---|---|---|
| ADDH / ADDL | `0x00 0x00` | Address 0, factory default |
| SPED | `0x1A` | 8N1 · UART 9600 · air data rate **2.4 kbps** |
| CHAN | `0x17` | **Channel 23**, i.e. **433.0 MHz** |
| OPTION | `0x44` | **Transparent** · push-pull IO · WOR 250 ms · **FEC on** · **30 dBm** |

Every field matches the dropdowns visible in the same screenshot. This is why the radio
configuration can be stated as fact rather than recollection.

---

## Section 7 — The code

| Claim | Verdict | Notes |
|---|---|---|
| "More than 400 lines of code" | **Correct** | ~450 across the three sketches |
| Explanation of `PROGMEM` and the bitmap | **Correct** | |
| The half-duplex reception snippet | **Correct as printed** | The report reproduces the code faithfully — including the missing framing that turned out to matter |
| "It is enough to write the data into the structure and send it" | **Correct as a description, dangerous as advice** | See KNOWN_ISSUES C-2: it works only because of small-string optimisation |
| The authentication mode adapts to link conditions, with a 7-second threshold | **Correct** | |
| Earlier in the report: "I had also implemented an acknowledge system" | **Wrong** | No acknowledgement exists in any surviving firmware. Either it was in an earlier revision, or "acknowledge" described the 5-second beacon |

---

## Section 8 — Node-RED integration

| Claim | Verdict |
|---|---|
| Node-RED dashboard over MQTT, with topics `start`, `codice`, `Batteria`, `Codice`, `connesso`; gauge, text and LED widgets | **Never implemented** |

The MQTT / Node-RED integration described in section 8 of the original report was never
implemented. **No networking code of any kind exists in any of the surviving sketches** — no
`WiFi.h`, no MQTT client, no `callback()`, no battery percentage calculation. The transmitter's
only timer is the 5-second beacon.

The same applies to the battery-monitoring branch of the section 2 flowchart, which belongs to
the same non-existent feature.

---

## Section 9 — Build and testing

| Claim | Verdict | Notes |
|---|---|---|
| Breadboard prototyping, then integration, then PCB | **Correct** | Photographs confirm |
| KiCad → EasyEDA migration | **Correct** | |
| SMD rev. 1 quoted at over $120, abandoned for a through-hole design at $2 + $15 shipping | **Correct** | And a good decision |
| Ground pour on both faces to reduce EMI | **Correct** | |
| Range test table (95 / 79 / 70 / 62 % at 50 / 100 / 400 / 1000 m) | **Unverifiable** | A single unrepeated walk, one route, one day, presented as a characterisation of the system. The author does not stand behind the numbers |
| Method: transmitter at home, walking away, at least 10 received beacons | **Correct, and commendably explicit** | Stating the method is what lets the table be assessed at all — and what makes it clear how thin it is |
| "not in line of sight, but in a fairly built-up area" | **Imprecise** | The route was roughly line of sight; the description understates the conditions, which makes the numbers look better than they were |
| The surrounding narrative implying a range of "about a kilometre" | **Wrong** | One unrepeated run does not support a range figure, and 62 % of packets is not "range" in any case |

**Neither the table nor the conclusion drawn from it deserved the confidence they were given.**
The author's repeated lived experience — reliable, then a drop at roughly 400 m that did not
recover — is better evidence than the table, and points at a different cause entirely. See
[`KNOWN_ISSUES.md`](KNOWN_ISSUES.md) C-10 and S-1.

---

## Section 10 — Defects and possible improvements

This is the best section in the report, and most of it stands up:

| Claim | Verdict | Notes |
|---|---|---|
| Moving to SMD would improve density | **Correct** | |
| The USB connector is too close to the first buzzer | **Correct** | A real and specific layout complaint |
| The heatsink could be improved, "perhaps a fan" | **Correct diagnosis, wrong fix** | A fan moves heat; a switching regulator stops producing it. The right answer is a buck converter |
| Higher-capacity lithium batteries would improve runtime and reliability | **Correct** | This is exactly right, and the report identified it two years before this document did |
| "An intermittent problem concerns the loss of connection, which seems to occur for no obvious reason … could be attributed to firmware issues, external interference, or insufficient robustness of the wireless circuit design" | **Correct, and honest** | The report names the problem and refuses to explain it away. The most likely causes are now identified — brownouts during transmit bursts and permanent stream desynchronisation — but the report was right to leave it open rather than invent a cause |
| Soldering skills could be improved | **Correct** | |

Section 10 is the reason this repository was worth writing. The instinct to list what did not
work was already there in 2024; what was missing was the knowledge to explain it.

---

## Summary

| Verdict | Count |
|---|---|
| Correct | ~35 claims |
| Imprecise | 6 |
| Unverifiable | 2 |
| Wrong | 7 |

The wrong ones, collected:

1. The 9 V battery was adequate "for a prolonged time" — it was not, by a wide margin.
2. 9 V batteries are "known for their durability" — not at these currents.
3. The operating frequency was 450 MHz — it was 433.0 MHz, from a hex-as-decimal misreading.
4. −148 dBm sensitivity applied to this configuration — it is the 0.3 kbps figure.
5. A range of about one kilometre — asserted from a single unrepeated walk, and 62 % of packets received is not a range figure in any case.
6. An acknowledgement system was implemented — no such thing exists in the firmware.
7. The Node-RED / MQTT integration — never implemented.

Seven wrong claims out of roughly fifty is a reasonable ratio for a first serious engineering
document written under exam pressure. Two still bother me:

- **The frequency**, because it was checkable in ten seconds against a screenshot printed on
  the facing page.
- **The range table**, because the problem was not the measurement — it was presenting one
  unrepeated walk as though it characterised the system. That is a habit, not a slip, and it is
  the one this repository is most trying to correct.

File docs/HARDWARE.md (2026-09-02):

# Hardware

Everything here is reconstructed from the surviving sketches, the 2024 school report, and
photographs of the assembled units. Where something could not be established from that
evidence it is marked **[unknown]** rather than guessed.

---

## 1. Units

The system is two physical objects and three microcontrollers.

### 1.1 The briefcase

An aluminium attaché case. Mounted through the shell: a 4×3 keypad, an SH1106 OLED, the round
GROW R557 fingerprint sensor, and a barrel key switch. Inside: the custom PCB carrying both
ESP32s, the E32 LoRa module, a solenoid lock, two buzzers, a panel voltmeter for the battery,
and a 9 V cell.

The case is my father's, and it still has its own original mechanical three-digit combination
lock on the lid, which works and is entirely unrelated to the electronics. Everything described
here was added around it.

### 1.2 The code transmitter

A hinged metal tin. Lid: the 16×2 LCD with its I²C backpack and a red status LED. Base: an
ESP32 dev board on a mini breadboard, the E32 module, a 9 V cell, a rocker switch, a relay
module, a trimmer, and an SMA antenna passing through the wall of the box.

The wiring here was never migrated to a PCB — the surviving photographs show it as a
breadboard build, taped and screwed into the tin.

> **Note on the relay** visible in the transmitter photographs (marked `6A 250VAC / 10A 12VDC`):
> nothing in `password_definitivo.ino` drives a relay, and the report does not mention one on
> the transmitter side. **[unknown]** — most likely a leftover from an earlier experiment, or
> used simply as a power switch.

---

## 2. Bill of materials

See [`BOM.md`](BOM.md).

---

## 3. Microcontrollers

Three ESP32-WROOM-32 development boards.

| Board | Location | Firmware |
|---|---|---|
| **A** | Briefcase, PCB position **U3** (38-pin devkit) | `valigia_definitivo.ino` |
| **B** | Briefcase, PCB position **U2** | `impronte_definitivo.ino` |
| **C** | Transmitter, on a breadboard | `password_definitivo.ino` |

The A/B to U2/U3 assignment is inferred from board pin counts in the PCB photograph and is
**[unknown]** with certainty.

### Why board B is an ESP32, not an Arduino Micro

`valigia_definitivo.ino` contains the comment *"se leggo che dall'arduino micro sono state
rilevate delle impronte giuste"* which means "if i read from the arduino that there are some good fingerprints...".
This is a leftover from an earlier revision.

The report states the Micro was used only for the initial standalone testing of the sensor.

---

## 4. Pin mapping

### 4.1 ESP32 "A" — briefcase main controller

| Function | GPIO | Note |
|---|---|---|
| Keypad row R1 | 33 | |
| Keypad row R2 | 25 | |
| Keypad row R3 | 26 | |
| Keypad row R4 | 27 | |
| Keypad column C1 | 14 | |
| Keypad column C2 | **12** | ⚠ strapping pin (MTDI) — see §7 |
| Keypad column C3 | 13 | |
| OLED SDA / SCL | 21 / 22 | ESP32 I²C defaults; confirmed by the report's block diagram |
| Buzzer (`ezBuzzer`) | 15 | |
| LoRa UART2 RX / TX | 16 / 17 | |
| LoRa M0 | 4 | |
| LoRa M1 | 23 | |
| LoRa AUX | 5 | |
| `SUONO_OK` — unlock **and** success tune | **19** | drives the lock circuit *and* signals board B |
| `SUONO_noOK` — wrong code | **2** | ⚠ strapping pin / onboard LED on many devkits |
| `OK_IMPRONTE` — fingerprint match in | **34** | ⚠ input-only, no internal pull-up/pull-down |

### 4.2 ESP32 "B" — fingerprint and audio

| Function | GPIO | Note |
|---|---|---|
| R557 UART2 RX / TX | 16 / 17 | ESP32 defaults; `Serial2` never opened with explicit pins |
| R557 baud rate | — | 57600 (`finger.begin(57600)`) |
| Buzzer (`tone()`) | 5 | never `pinMode`'d; `tone()` configures it |
| `SUONO_OK` in (from A GPIO19) | 33 | |
| `SUONO_noOK` in (from A GPIO2) | 25 | |
| `OK_IMPRONTE` out (to A GPIO34) | 27 | |

### 4.3 ESP32 "C" — code transmitter

| Function | GPIO |
|---|---|
| LCD SDA / SCL | 21 / 22 |
| LoRa UART2 RX / TX | 16 / 17 |
| LoRa M0 | 4 |
| LoRa M1 | **18** |
| LoRa AUX | **19** |

Note that M1 and AUX differ between the two LoRa installations (23/5 on board A, 18/19 on
board C). Both are valid — they are different boards — but it is worth knowing when reading
the two sketches side by side.

### 4.4 Inter-MCU signalling inside the briefcase

Three single-bit GPIO lines, not a bus:

| Signal | From | To | Meaning |
|---|---|---|---|
| `SUONO_OK` | A GPIO19 | B GPIO33 | correct code / unlock — **also energises the lock driver** |
| `SUONO_noOK` | A GPIO2 | B GPIO25 | wrong code |
| `OK_IMPRONTE` | B GPIO27 | A GPIO34 | fingerprint matched |

---

## 5. The keypad

```text
Layout as defined in char keys[4][3]:
  1 2 3
  4 5 6
  7 8 9
  * 0 #

Rows    (pin_righe[4]):   R1→GPIO33   R2→GPIO25   R3→GPIO26   R4→GPIO27
Columns (pin_colonne[3]): C1→GPIO14   C2→GPIO12   C3→GPIO13
```

**Important!!!.** 
This is the combination that produced correct key readings *with the
harness as it was physically wired*. The wires leaving the keypad were reordered before they
reached the ESP32, so these arrays do not tell you which physical pin on the keypad connector
is "row 1". Working that out empirically is what made this part of the build so frustrating in
2024, and this documentation deliberately does not pretend to know the connector pinout.

Behaviour notes from the firmware:

- `#` validates the entry. There is no delete key.
- `*` has no special handling — it is appended to `input_password` like any other character.
- Input length is unbounded.
- Every keypress produces a 100 ms non-blocking beep via `ezBuzzer`.

---

## 6. Fingerprint sensor — GROW R557

Capacitive round module from Hangzhou Grow Technology, connected over UART at 3.3 V logic.
From the report's summary of the manufacturer's manual:

| Parameter | Value |
|---|---|
| Interface | UART, 3.3 V TTL |
| Supply | 3.3 V DC |
| Current | ~30 mA during capture, ~5 µA standby |
| Capacity | up to 120 templates |
| False accept | < 0.001 % |
| False reject | < 1 % |
| Capture time | < 0.2 s |
| Resolution | 508 dpi |
| Template generation | < 500 ms |

The module has an RGB ring used as status:

- **Red** — fingerprint not recognised
- **Green** — fingerprint recognised
- **Blue** — module powered, waiting for a finger

### The key switch

The sensor is powered through a barrel key switch mounted in the case. The firmware has **no
knowledge of the key at all** The switch is wired in series with the R557's supply,
so with the key out the module is simply unpowered and `getImage()` never succeeds. 
In the demonstration video the sensor's ring is dark until the key is turned, then lights green.

This is (maybe) the most genuinely secure element in the whole design, and it is entirely
mechanical.

### Templates and the "binding" question

Templates live in the module's own flash, so enrolment travels with the sensor and not with
the host. See the corresponding section in [`KNOWN_ISSUES.md`](KNOWN_ISSUES.md) for why the
sensor appearing "bound" to one ESP32 is much more likely to be a changed stored parameter
(baud rate, handshake password, or device address) and/or 5 V over-drive during the early
Arduino Micro tests.

**Enrolment is not in any surviving file.** `impronte_definitivo.ino` only calls `getImage()`,
`image2Tz()` and `fingerSearch()` — it can match a finger but never register one. It does,
however, still print `"Adafruit Fingerprint sensor enrollment"` at startup, which is a leftover
from Adafruit's `enroll` example. You have o enroll your finger with the code provided by the library for this model.
---

## 7. ESP32 pin hazards present in this design

**GPIO34 as the fingerprint-match input.** GPIO 34–39 are input-only and have **no internal
pull-up or pull-down**. The line floats while board B is in reset or unpowered, so the state
read by board A during that window is undefined. In practice board B holds it low quickly
enough, but an external 100 kΩ pulldown would have made this deterministic.

---

## 8. Power

| | Briefcase | Transmitter |
|---|---|---|
| Battery | 9 V 6F22 | 9 V 6F22, **zinc-carbon** (VARTA Super Heavy Duty, visible in photographs) |
| Regulator | LM7805CT | LM7805CT |
| Filtering | 100 nF + 10 µF on input and output | same |
| Cooling | external heatsink with thermal paste | same |
| Monitoring | panel voltmeter module | resistive divider to an ESP32 ADC |
| Remembered draw | ~300 mA | ~150 mA |

The report's power schematic is labelled **+12 V** at the regulator input while the text and
photographs both show a 9 V battery. Treat the 12 V label as a drawing artefact.

The 7805 module itself survives as a small piece of perfboard carrying the TO-220 device on a
bracket, two 10 µF electrolytics, two 100 nF ceramics and two 3-pin headers.

### Why this supply was not adequate

Covered in detail in the README and in [`KNOWN_ISSUES.md`](KNOWN_ISSUES.md). In short:

- The E32-433T30D draws **570–670 mA** while transmitting. A 6F22 cell has an internal
  resistance of several ohms and cannot deliver that without its terminal voltage collapsing.
- At 300 mA the LM7805 dissipates (9 − 5) × 0.3 = **1.2 W**, roughly 44 % of the total power
  drawn from the battery.
- The lock's 1.7 A is above the LM7805's 1.5 A rating regardless of everything else.

---

## 9. Lock and driver

| Item | Value | Source |
|---|---|---|
| Actuator | solenoid, model **[unknown]** | photographs / report |
| Measured draw | **1.7 A at 9 V** | bench-supply measurement, recalled |
| Nominal voltage | **[unknown]** | — |
| Driver | BDX53C Darlington, TO-220 | report |
| Base resistor | 1 kΩ, later 0 Ω | report / recollection |
| Lock supply | **separate** from the logic supply | recollection |
| Separate source | **18 V cordless-drill battery pack**, fitted as a stopgap and never replaced | recollection |

**BDX53C** (ST / onsemi) key figures:

| Parameter | Value |
|---|---|
| Vceo | 100 V |
| Ic continuous | 8 A |
| hFE min | **750** at Vce = 3 V, Ic = 3 A |
| Vce(sat) max | **2 V** at Ic = 3 A, Ib = 12 mA |
| Vbe(sat) max | **2.5 V** at the same conditions |
| Internal base-emitter resistors | R1 ≈ 8.4 kΩ, R2 ≈ 0.3 kΩ |
| Freewheel diode | integrated, Vf 1.8 V at 3 A |

The report's reasoning for choosing a Darlington — that it multiplies current gain and can
therefore switch a solenoid a microcontroller cannot drive directly — is correct as far as it
goes. What it misses is that the same stacked structure that gives the gain also stacks two
base-emitter drops, which is fatal on a 3.3 V rail. See the README for the full calculation.

### The LED + photoresistor coupler

```
ESP32 GPIO ──► LED ──┐
                     │   optical coupling, taped over
                     ▼
 separate V+ ──[ LDR ]── B  BDX53C  C ── solenoid ── separate V+
                            E
                            └── GND of the separate supply
```

The GPIO drives only the LED (~10 mA). Base current for the Darlington comes from the lock's
own 18 V supply through the illuminated LDR, which removes the 3.3 V headroom problem entirely:

```
I_base ≈ (18 V − 1.6 V) / ~2 kΩ ≈ 8 mA
required β = 3.4 A / 8 mA ≈ 425      vs   750 guaranteed
```

That is the only configuration in this project in which the Darlington could actually
saturate. The optical coupling was the mechanism; **the 18 V rail was the fix.**

Running an 18 V pack into a solenoid characterised at 9 V also means roughly double the
current and four times the power in the coil — on the order of 60 W while energised. It
survived because it was only ever energised for about a second at a time. Held on
continuously, the coil would have been the first thing to fail.

No photograph of this circuit survives among the project files.

---

## 10. PCB

Designed in EasyEDA, after migrating from KiCad.

### Revision 1 — SMD

Fully routed with SMD passives, two ESP32 modules, a DIP-package IC, tactile switches, screw
terminal and two buzzers. **Never manufactured** — quoted at over $120.

Renders survive in the original report.

### Revision 2 — through-hole (the one that was built)

- Two layers, ground pour on **both** faces, explicitly for EMI reasons.
- Both briefcase ESP32s on a single board (`U2`, `U3`).
- Screw terminal for the lock, on-board buzzers, headers `H2`, `H4`, `H5`, `H6` for the
  keypad, OLED, fingerprint sensor and LoRa module.
- Q1: TO-220 footprint for the Darlington, R2 / R3 through-hole resistors, C1 / C3 filtering.
- Silkscreen: `5803346A_Y2_240518`, *"Made by Minguz in Italy"*.
- Back-side easter egg: a stick figure pointing at an insect, captioned `LOOK, A BUG!`.
- **$2 for the boards, $15 shipping.**

Known layout complaints, from the original report:

- The USB connector sits too close to the first buzzer, making it awkward to plug a cable in
  to reprogram the board.
- The heatsink arrangement for the LM7805 is functional but crude; the report suggests a fan,
  which is the wrong fix — a switching regulator removes the heat instead of moving it.

Source files: the EasyEDA project is **[unknown]**, but the **Gerbers are recoverable from
the JLCPCB order history**, which is enough to make the board reproducible.

---

## 11. Antennas

Quarter-wave whip antennas on SMA connectors. The report's calculation is correct:

```
λ  = c / f = 3×10⁸ / 433×10⁶ ≈ 0.693 m
λ/4 ≈ 0.173 m = 173 mm
```

On the transmitter, the antenna passes through the wall of the tin box and stands outside it.

On the briefcase, the antenna was likewise mounted **outside** the aluminium shell. Enclosure
shielding is therefore not an explanation for the link behaviour — which is worth stating,
because it is the first thing anyone reasonable would suspect.

A further point the original report does not address: a quarter-wave monopole needs a ground
plane to work against. Mounted on a dev board with a few centimetres of copper, its real
efficiency is well below the textbook figure.

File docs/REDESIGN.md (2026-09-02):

# What I Would Do Differently Today

This is the part of the repository I find most useful. Nothing here is a criticism of the
2024 build for its own sake — every item is something the project taught me by failing.

---

## Summary table

| Original design | Problem | How I would redesign it today |
|---|---|---|
| 9 V zinc-carbon battery | Cannot source 300 mA continuous or 610 mA bursts; capacity collapses under load | 1S Li-ion 18650 with protection (9–13 Wh), plus bulk capacitance at the radio |
| LM7805 linear regulator | 44 % of energy wasted as heat; 1.5 A ceiling; thermal shutdown | Synchronous buck to 5 V, separate LDO for 3.3 V |
| One supply for logic and lock | 1.7 A transients on the logic rail | Separate lock supply, its own switch, single-point common ground |
| BDX53C Darlington on a 3.3 V GPIO | Two stacked Vbe drops; β of 1130 needed against 750 guaranteed | Logic-level N-channel MOSFET with Rds(on) specified at Vgs = 2.5–3.0 V |
| LED + photoresistor coupler | Slow, unspecified, ambient-light sensitive, not real isolation | PC817 / TLP291 if isolation is wanted; direct MOSFET drive if not |
| 18 V drill pack into a 9 V solenoid | ~3.4 A and ~4× the rated coil power | Buck the pack down to the solenoid's rated voltage |
| Freewheel diode only inside the Darlington | Absent once you switch to a MOSFET | Explicit Schottky across the solenoid |
| Raw C struct containing an Arduino `String` | Undefined behaviour masked by small-string optimisation | Packed byte protocol: magic, version, type, sequence, length, payload, CRC-16 |
| No ACK, retry or timeout | A single lost packet silently desynchronises system state | ACK + sequence numbers + bounded retries + explicit link state machine |
| `if (available()) readBytes(24)` | Short reads desynchronise the stream permanently | Byte-oriented parser with a start delimiter; resync on CRC failure |
| Rolling code sent in clear | Readable by any default-configured E32 in range | Challenge–response with a pre-shared key; never send the secret |
| No attempt limiting | 10⁵ codes brute-forceable overnight | Exponential backoff, hard lockout, attempt logging |
| Always-on ESP32s | Hundreds of mA for a device used for seconds a day | Deep sleep with `ext1` wake on a keypad row; load switches for radio and sensor |
| A second ESP32 for one UART | Board area, cost, three signalling lines | One ESP32 with `Serial1` remapped |
| GPIO12 as a keypad column | Strapping pin; boot hazard | Any non-strapping GPIO (32, 33, 27, 26…) |
| GPIO19 shared between lock and UI signal | Actuator coupled to a UI event | Separate pins — or one MCU and no signalling at all |
| 1 W on 433.0 MHz | Illegal licence-free in the EU; busiest channel in the band | ≤ 10 mW ERP on a quieter channel, or 868 MHz with duty-cycle discipline |
| Estimated power figures | Never measured | INA219/INA226, design from a measured average |

---

## 1. Driving the lock

### Why the Darlington was the wrong device — and what "logic-level MOSFET" actually means

Saying "use a logic-level MOSFET" is not enough advice to act on, so here is the reasoning in
full, for switching **1.7 A from a 3.3 V GPIO**.

**Vgs(th) is not the turn-on voltage.** It is defined as the gate voltage at which the device
conducts roughly 250 µA — essentially "barely not off". A part with Vgs(th) = 2 V is *not*
guaranteed to be usefully on at 3.3 V. Choosing a MOSFET by its threshold voltage is the
single most common mistake in this area, and it is exactly the reasoning that made me avoid
MOSFETs in 2024.

**The number that matters is Rds(on) specified at Vgs = 2.5 V or 3.0 V.** If a datasheet only
quotes Rds(on) at Vgs = 10 V or 4.5 V, that part is not intended for 3.3 V gate drive,
whatever its threshold says.

**Design to the dissipation, not to the current rating.**

```
At 1.7 A with Rds(on) = 50 mΩ @ Vgs = 3.0 V:
  P = I²R = 1.7² × 0.05 ≈ 0.14 W        → no heatsink needed

Compare the Darlington, if it had saturated:
  P = I × Vce(sat) = 1.7 × ~1.5 V ≈ 2.5 W → heatsink mandatory
  and it did not saturate, so the real figure was worse.
```

A 20× reduction in dissipation, from one part substitution.

**Gate drive.** A solenoid does not care about switching speed, so gate charge is not a
constraint here. Two components make it robust:

- **100 Ω in series with the gate** — limits the inrush the ESP32 pin sees while charging the
  gate capacitance, keeping it under the 40 mA absolute maximum.
- **100 kΩ from gate to source** — holds the MOSFET off while the GPIO is high-impedance,
  which it is during reset, boot and deep sleep. Without this, the lock's state during a reset
  is undefined. On a lock, that matters.

**You still need a flyback diode.** The BDX53C had one built in; a MOSFET's body diode faces
the wrong way for a low-side switch. Add an external Schottky across the solenoid, rated for
at least twice the supply voltage and twice the current — for 9 V at 1.7 A, something like a
40 V / 3 A part. Without it, the inductive kick when the coil is de-energised will punch
through the MOSFET.

**Part selection.** Devices commonly used for 3.3 V gate drive at this current include
AO3400-class SOT-23 parts and IRLB8721-class TO-220 parts. **Check the Rds(on)-at-2.5 V column
on the datasheet of the part you actually buy**, not on a forum recommendation — the same
marking from different manufacturers can behave differently at low Vgs.

### Could a different part just drop into the same footprint?

Yes — and this is the most useful practical question about the whole board, because it does not
require a redesign.

**The pinouts map one-to-one.** A TO-220 NPN Darlington is Base–Collector–Emitter on pins
1–2–3. A TO-220 N-channel MOSFET is Gate–Drain–Source on pins 1–2–3. The functions correspond
exactly: base → gate, collector → drain, emitter → source. Even the metal tab agrees — it is
the collector on the BJT and the drain on the MOSFET, which are the same node in both circuits.

**So a logic-level N-channel MOSFET solders straight into the `Q1` pads with no board
modification at all.**

Two things to know before doing it:

**1. Leave the 1 kΩ where it is. Do not bridge it.** For a BJT that resistor sets base current;
for a MOSFET it only limits the current spike that charges the gate capacitance. With a typical
Ciss of 1–2 nF, 1 kΩ gives a switching time constant of a couple of microseconds — completely
irrelevant for a solenoid, and it protects the ESP32 pin. The 0 Ω bridge was the right instinct
for the wrong device: it makes a BJT slightly less starved and a MOSFET slightly less safe.

**2. Two things must be added, and neither needs a new board.**

- **A gate-to-source pulldown, ~100 kΩ.** The original board has nothing holding the gate low.
  A MOSFET gate is an open circuit, so while the ESP32 is in reset, booting, or asleep, the pin
  is high-impedance and the gate floats — the lock's state becomes undefined. Solder the
  resistor directly across pins 1 and 3 of the device.
- **A flyback diode across the solenoid.** This one is not optional. The BDX53C had one built
  in, which is why the original circuit got away without it. A MOSFET's body diode faces the
  wrong way for a low-side switch, so the inductive kick when the coil de-energises has nowhere
  to go and will punch straight through the device. The existing screw terminal is the obvious
  place to fit it.

**3. And fix the supply voltage while you are in there.** At 18 V a 30 V-rated MOSFET is too
close to its limit with an inductive load, and 30 V is where most parts with Rds(on) actually
specified at Vgs = 2.5 V live. More importantly, the solenoid should not be seeing 18 V at all.
Buck the pack down to the solenoid's rated voltage and the whole problem gets easier: lower
current, a quarter of the coil dissipation, and a comfortable choice of MOSFET.

If you keep 18 V, a 3.3 V GPIO can still drive it — a low-side switch has its source at ground,
so the supply rail does not affect gate drive at all — but you will want either a 60 V part
whose datasheet genuinely quotes Rds(on) at 3 V, or a small gate driver / two-transistor level
shift so the gate can be driven to 10 V.

### Or: keep the Darlington and fix only the base circuit

There is a smaller fix that keeps every original part, and it is worth stating because it is
what the LED-and-LDR hack was groping towards.

Replace the LDR with a real optocoupler (PC817, TLP291), fed from the lock's own supply. The
optocoupler's output transistor sits where the LDR was, and the base resistor now has the lock
rail across it instead of 3.3 V:

```
I_base = (18 V − 1.6 V) / 1 kΩ ≈ 16 mA
required β = 3.4 A / 16 mA ≈ 210      vs   750 guaranteed
```

**Which means the 1 kΩ resistor was never the wrong value.** It was the right value with the
wrong voltage across it. Finding it "empirically" gave a number that would have worked
perfectly well from an 18 V rail and could never have worked from a 3.3 V pin — which is a
tidy illustration of why empirical component selection without a model tells you *that*
something works, but not *when it will stop*.

### If isolation is genuinely wanted

The LED-and-LDR hack was, in effect, an attempt at isolation. If that is the goal, do it
properly:

- **PC817** — cheap, ubiquitous, CTR 50–600 % (wide, so design for the worst case).
- **TLP291** — better CTR specification, easier to design around.
- Either switches in microseconds instead of hundreds of milliseconds, has a rated isolation
  voltage, and is immune to ambient light.

But for a low-side solenoid switch sharing a ground with the MCU, **isolation is not needed at
all** — a MOSFET does the job. The reason isolation seemed necessary in 2024 was the base-drive
problem, and that problem disappears with the right device.

---

## 2. Power

### Why a rectangular 9 V battery is the wrong choice for hundreds of milliamps

Three distinct problems that are easy to conflate:

**1. Capacity.** A 9 V alkaline is rated around 550 mAh, but that rating assumes a drain of a
few milliamps. Usable capacity falls sharply as current rises, and for a 6F22
that fall is steep. Zinc-carbon, which is what the photographs show, is far worse again.

**2. Internal resistance — the one that actually killed this project.** A 6F22 is six tiny
cells stacked in series inside a small can. The electrode area is minute and the internal
resistance is on the order of **several ohms**. A 610 mA transmit burst therefore drops
volts *inside the battery*, before any of it reaches the regulator.

This is a **power** limit, not an energy one. No amount of "a bigger 9 V battery" fixes it,
because there is no such thing.

**3. The linear regulator throws away the difference.** At 300 mA the LM7805 dissipates
(9 − 5) × 0.3 = **1.2 W** out of about 2.7 W drawn from the battery. **Over 44 % of the stored
energy becomes heat before it powers anything at all.**

### What I would build instead

**Logic rail.** A single 18650 Li-ion cell: 3.7 V nominal, 2500–3500 mAh, i.e. **9–13 Wh**
against about 4.5 Wh nominal for a 9 V alkaline, at maybe a third of the cost per cycle and
with an internal resistance in the tens of milliohms rather than ohms.

- With a protection board (over-discharge, over-current, short circuit) — not optional on Li-ion.
- Boost to 5 V for the LoRa module, or run a 5 V/3.3 V rail pair from a small buck-boost.
- A **synchronous buck** (MP1584, TPS5430 class) at 85–92 % efficiency instead of the 7805's
  55 %. That difference alone roughly doubles the runtime.

**Radio rail.** A **220–470 µF low-ESR capacitor directly across the E32's supply pins.** The
610 mA burst lasts a few hundred milliseconds; local bulk capacitance turns a supply
*collapse* into a supply *sag*. This is the single cheapest fix in this entire document, and
it would likely have removed a good share of the "random disconnections".

**Lock rail.** Completely separate. The lock's 1.7 A transient has no business on the same
rail as an MCU and a radio.

- A dedicated pack, or a boost converter sized for the surge, with its own bulk capacitance.
- Common ground at a **single point**, so the lock's return current does not flow through the
  logic ground.
- Its own switch, so the lock can be de-energised for firmware work without powering the
  system down.

**Sleep.** This is a device that is genuinely in use for a few seconds a day and idle the rest
of the time. Hundreds of milliamps at idle is the wrong shape entirely.

- `esp_deep_sleep_start()` brings an ESP32 to a few tens of microamps.
- Wake on `ext1` from a keypad row — pull the rows up, tie the columns low while asleep, and
  any keypress wakes the chip.
- Power the fingerprint sensor and the LoRa module through **load switches** so they draw
  nothing while asleep. The key switch already does exactly this for the sensor, mechanically;
  the redesign would keep the key and add a MOSFET load switch for the radio.
- The transmitter has to stay awake to receive, but its E32 supports WOR (wake-on-radio), which
  the datasheet puts at around **30 µA average** — the parameters were already configured for
  250 ms WOR timing and never used.

**Measure it.** Every current figure in this project is a recollection. An INA219 or INA226 on
the battery lead, logging over a realistic day, would turn a design guess into a design input.
Battery sizing should start from a measured average, not an estimated peak.

---

## 3. The protocol

### An explicit packet format

```
┌────────┬─────────┬──────┬─────┬─────┬─────────┬────────┐
│ 0xA5   │ version │ type │ seq │ len │ payload │ CRC-16 │
│ 1 byte │ 1 byte  │ 1 B  │ 1 B │ 1 B │ 0-32 B  │ 2 B    │
└────────┴─────────┴──────┴─────┴─────┴─────────┴────────┘
```

- **`0xA5` start delimiter** — gives the parser something to resynchronise on. This alone fixes
  the permanent-desync failure.
- **Version** — lets two units with different firmware detect the mismatch instead of
  misinterpreting each other's bytes.
- **Type** — `BEACON`, `OPENED`, `NEW_CODE`, `ACK`. Explicit, instead of inferring intent from
  which boolean happens to be set.
- **Sequence number** — makes acknowledgement and duplicate detection possible.
- **Length** — the receiver knows how many bytes to expect before reading them.
- **CRC-16** — catches what the module's FEC does not.

Everything fixed-width and explicitly serialised. No `String`, no `sizeof(struct)` on the
wire, no dependence on compiler padding or on a core's string implementation.

### A byte-oriented reader

```cpp
// sketch of the idea, not production code
switch (state) {
  case WAIT_START: if (b == 0xA5) state = READ_HEADER;      break;
  case READ_HEADER: /* ... collect 4 bytes, then */ state = READ_PAYLOAD; break;
  case READ_PAYLOAD: if (--remaining == 0) state = READ_CRC; break;
  case READ_CRC: /* verify; on failure → WAIT_START */      break;
}
```

Never block. Never assume `available()` means a whole packet. On a CRC failure, drop back to
hunting for the start byte — which is what makes the link self-healing instead of permanently
broken.

### Acknowledgement and retry

The critical message is "the briefcase was opened", because losing it means the code is never
rotated and the system silently stops being a one-time-code system.

```
CASE → TX : OPENED   seq=N
TX   → CASE: ACK     seq=N
   (no ACK within 500 ms → retransmit, up to 3 times, backing off)
   (still nothing → surface it on the OLED)
```

With a 70 % per-packet success rate, one attempt plus two retries gives 1 − 0.3³ = **97.3 %**
per message. That is what would have turned an unreliable-feeling device into a reliable one —
without touching the radio at all.

### Link state, explicitly

Replace `nobuono` and the overloaded `connesso` field with a named state:

```
ALIVE ──(no beacon for 7 s)──► DEGRADED ──(no beacon for 60 s)──► DOWN
   ▲                                │
   └────────────(beacon)────────────┘
```

`DEGRADED` enables the fingerprint path but keeps the keypad live in case the link comes back
mid-entry. The current code disables the keypad the instant the timeout fires, which is why a
30 % packet loss rate is so visible to the user.

---

## 4. Security

The current design is a demonstrator, and the honest redesign starts by naming what it should
actually resist.

**Never transmit the secret.** A rolling code sent in clear is readable by anyone with a €10
module. Challenge–response, instead:

```
CASE → TX : CHALLENGE, nonce
TX   → CASE: RESPONSE, HMAC-SHA256(pre-shared key, nonce)[0..7]
```

The key never goes on the air. A recorded exchange is useless because the nonce never repeats.
The ESP32 has hardware SHA support, so this costs nothing in practice.

**Rate-limit attempts.** After 3 failures, 5 seconds. After 6, 60 seconds. After 10, a hard
lockout that requires the key. This turns 28 hours of brute force into geological time, and it
is about fifteen lines of code.

**Do not display the code permanently.** Show it on demand, on a button press, with a timeout.

**Use a real RNG.** `esp_random()` is only a true RNG when the RF subsystem is active or the
ADC entropy source is enabled — neither of which applied here. Call
`bootloader_random_enable()`, or derive codes from the HMAC construction above and stop
needing an RNG at all.

**Be honest about the threat model.** A solenoid inside a thin aluminium case is not resisting
a determined attacker with a screwdriver. The electronics should be proportionate to that —
which is an argument for *simpler* and *more reliable*, not for more cryptography.

---

## 5. Architecture

### One microcontroller

```cpp
Serial1.begin(57600, SERIAL_8N1, /*RX=*/26, /*TX=*/27);   // fingerprint
Serial2.begin(9600,  SERIAL_8N1, /*RX=*/16, /*TX=*/17);   // LoRa
```

The ESP32's UART pins route through the GPIO matrix, so UART1's unusable default pins are not
a constraint. A single ESP32 comfortably hosts:

- UART1 → fingerprint sensor
- UART2 → LoRa module
- I²C (21/22) → OLED
- 7 GPIO → keypad
- 1 GPIO → lock MOSFET
- 1 GPIO → buzzer (LEDC hardware PWM, not `tone()`)

That removes a microcontroller, three signalling wires, a chunk of board area, and the whole
class of bugs that comes from two loops disagreeing about state.

### Alternatives considered, and why they are not better here

The prompt for this analysis asked about multiplexing and port expanders. For completeness,
and because "you could also have…" advice is only useful if it is checked:

- **A UART multiplexer** (e.g. a 74HC4052 switching TX/RX between two peripherals) works, but
  it is strictly worse than remapping: extra parts, and only one peripheral reachable at a
  time.
- **An I²C or SPI port expander** (PCF8574, MCP23017) is the right answer for the *keypad* —
  it would free seven GPIOs — but it does nothing for the fingerprint sensor, which is a UART
  device with no I²C variant in the R55x family. A port expander cannot solve a UART shortage.
- **A software UART on ESP32** via the RMT peripheral is possible but is a lot of complexity to
  avoid one line of pin remapping.

So: remap the UART, and optionally put the keypad on a PCF8574 if the pin count gets tight.

### PCB changes

- **Keypad off GPIO12**, and off GPIO 2 / 15 while you are at it.
- **A 100 kΩ pulldown on any input-only pin** (GPIO 34–39) used for a real signal.
- **Separate lock and logic ground pours**, joined at one point near the battery negative.
- **Bulk capacitance next to the E32's supply pins**, not at the regulator.
- Move the USB connector away from the buzzer — the original report's own complaint, and a
  fair one.
- Keep the easter egg.

---

## 6. Radio

- **Reduce the power.** 10 mW ERP is the licence-free limit across most of Europe for
  433.05–434.79 MHz. Even ignoring legality, 1 W into an antenna a metre from your body,
  radiating from a metal case, is not a good design.
- **Move off 433.0 MHz.** It is the busiest slice of the band and the manual says to avoid it.
  Channel 30 (440 MHz) is quieter, and 868 MHz is quieter still — with the trade-off of shorter
  wavelength and stricter duty-cycle rules.
- **Put the antenna outside the metal.** If it must be inside, use a proper external SMA
  bulkhead — which the transmitter already did and the briefcase may not have.
- **Give the monopole a ground plane.** A quarter-wave whip needs something to work against.
- **Consider dropping the air data rate to 1.2 or 0.3 kbps.** With 24-byte packets every 5
  seconds there is plenty of airtime budget, and the sensitivity improvement is several dB —
  free range, at no cost in this application.
- **Use fixed transmission mode with a real address**, not the default broadcast-ish
  configuration on address 0. It will not make the link secure, but it stops the units from
  hearing every other default-configured E32 in the neighbourhood.

---

## 7. What I would keep

Not everything needs redesigning:

- **The graceful degradation concept.** A system that notices it has lost its primary
  authentication channel and falls back to a secondary one is a genuinely good idea. The
  implementation needs work; the idea does not.
- **The physical key as an interlock.** Ending up with the most robust security element being
  a mechanical one was an accident, but it was a good accident.
- **Rolling codes.** The right instinct, even if the implementation transmits them in clear.
- **Through-hole for a student build.** $2 versus $120, easy to solder, easy to rework, and
  the board survived being handled for two years.
- **Ground pour on both layers.** Cheap, and correct.
- **`ezBuzzer` for non-blocking audio on the main controller.** Recognising that the UI loop
  could not afford to block was the right call — it just was not applied consistently.

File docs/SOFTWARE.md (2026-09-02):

# Software

Three Arduino sketches, roughly 450 lines in total, preserved with their original Italian
filenames and comments.

| File | Board | Role |
|---|---|---|
| `valigia_definitivo.ino` | ESP32 A | Keypad, OLED, LoRa, lock, top-level state machine |
| `impronte_definitivo.ino` | ESP32 B | Fingerprint polling, buzzer melodies |
| `password_definitivo.ino` | ESP32 C | Code generation, LCD, LoRa beacon |

Libraries: `EBYTE` (Kris Kasprzak), `Adafruit_Fingerprint`, `Keypad`, `ezBuzzer`,
`Adafruit_GFX`, `Adafruit_SH110X`, `LiquidCrystal_I2C`, `Wire`, `SPI`.

---

## 0. A note on names: this code is in Italian

The sketches were written in Italian and are preserved that way. Nothing here has been renamed,
because a tidied-up reconstruction would not be the thing this repository is documenting.

This table is the decoder ring. Some of these names are ordinary Italian; a few are
abbreviations that meant something at 1 a.m. in 2024 and nothing to anyone since — including,
by now, to me.

### Data and protocol

| Identifier | Italian | English | What it actually does |
|---|---|---|---|
| `DATA` | — | — | The struct sent over the radio |
| `aperto` | aperto | opened | `true` when the case has just been opened |
| `passwordTX` | — | transmitted password | The 5-digit code |
| `connesso` | connesso | connected | Sent as `true`, cleared locally — effectively unused (C-9) |
| `MyData` | — | — | The single global instance |
| `Transceiver` | — | — | The `EBYTE` object |

### State flags

| Identifier | Literally | What it means |
|---|---|---|
| `nobuono` | "no good" | **The link-lost flag.** `true` = radio down, keypad disabled, fingerprint enabled |
| `apro` | "I open" | Lock currently energised, waiting to be released |
| `welc` | welcome | The "Welcome Mr Minguzzi" screen is showing |
| `incpass` | incorrect password | The "INCORRECT PASSWORD" screen is showing |
| `impronta_ok` | fingerprint OK | Last poll of the sensor matched |

### Timers — all `millis()` timestamps, all named badly

| Identifier | Literally | What it times |
|---|---|---|
| `Last` | — | Timestamp of the last received packet — the real link-liveness variable |
| `noconnected` | — | Rate-limits the "not connected" serial print to every 500 ms |
| `scritta` | "writing", "lettering" | Redraws the LOST CONNECTION text every 5 s |
| `timer_impronta` | fingerprint timer | Redraws the fingerprint bitmap every 10 s |
| `delei` | *unclear* — probably a mangled "delay" | Holds the lock energised for 1 s after a correct code |
| `vario` | "various" | Clears the OLED 7 s after a welcome or error screen |
| `timer_conto` | "count timer" | The 5-second beacon interval on the transmitter |
| `t` | — | Generic 100 ms poll timer on the fingerprint board |

`delei` is the one I cannot reconstruct. It is the most important timer in the sketch — it is
what releases the lock — and it is named after nothing.

### Pins and hardware

| Identifier | Literally | Meaning |
|---|---|---|
| `SUONO_OK` | "sound OK" | Correct code — **and, on the main board, the lock line** (C-19) |
| `SUONO_noOK` | "sound not OK" | Wrong code |
| `OK_IMPRONTE` | "fingerprints OK" | Fingerprint matched |
| `RIGHE` / `pin_righe` | rows | Keypad rows |
| `COLONNE` / `pin_colonne` | columns | Keypad columns |
| `Chan` | channel | **Declared in both radio sketches and never used** — the modules were configured externally |
| `buzzer`, `finger`, `display`, `lcd`, `keypad` | — | Already English |

### Strings and comments that are lies

A few artefacts that are worth knowing about before you read the source:

- **`Serial.println("\n\nAdafruit Fingerprint sensor enrollment");`** in
  `impronte_definitivo.ino`. The sketch does **not** enrol anything — it only calls
  `getImage()`, `image2Tz()` and `fingerSearch()`. This string is a leftover from Adafruit's
  `enroll` example, which is what the file was started from. It is also the best evidence for
  how the fingerprints were originally registered: with the stock example, from a separate
  sketch that no longer survives.
- **`// se leggo che dall'arduino micro ...`** in `valigia_definitivo.ino`. There is no Arduino
  Micro in the finished system; that board only appeared during early standalone testing of
  the sensor. See HARDWARE.md §3.
- **`Serial.println("apero");`** — a typo for `apro` ("I open"), printed when the fingerprint
  path fires.
- The comments contain a steady drizzle of typos — `orte seriali` for *porte seriali*,
  `sesnsore`, `comunixo`, `cartattere`, `dunzioni`, `imizializzo`, `tastierà`. They are
  preserved as written.
- **`myBitmapdownload`** — the fingerprint bitmap is named after the filename of the PNG it was
  generated from (`download.png`), by whichever image-to-C-array converter produced it.

### There is no key-switch variable

Worth stating explicitly, because it is easy to look for and not find: **neither sketch reads a
pin for the key switch.** The key is wired in series with the fingerprint sensor's supply. With
the key out, the R557 is unpowered and `getImage()` simply never succeeds. The second factor is
real, and it is entirely outside the firmware.

---

## 1. The shared data structure

Declared identically in both radio sketches:

```cpp
struct DATA {
  bool aperto;        // briefcase opened: 0 = closed, 1 = opened
  String passwordTX;  // the transmitted code
  bool connesso;      // "still connected" flag
};
```

### Actual size on ESP32

```
offset  0 : bool aperto        1 byte
offset  1 : padding            3 bytes
offset  4 : String passwordTX 16 bytes
offset 20 : bool connesso      1 byte
offset 21 : padding            3 bytes
                              ─────────
sizeof(DATA)                  24 bytes
```

24 bytes against the E32's 58-byte sub-packet limit. Packet size was never a constraint.

### Why sending a `String` this way is undefined behaviour

`EBYTE::SendStruct()` is a raw byte copy:

```cpp
bool EBYTE::SendStruct(const void *TheStructure, uint16_t size_) {
    _buf = _s->write((uint8_t *) TheStructure, size_);
    CompleteTask(1000);
    return (_buf == size_);
}
```

An Arduino `String` is an object, not an array. For longer strings it holds a `char*` into the
heap. Copying those bytes onto the wire copies the *pointer*; the receiver then has a pointer
into the sender's address space.

It worked because arduino-esp32's `String` implements small-string optimisation:

```cpp
struct _ptr { char *buff; uint32_t cap; uint32_t len; };   // 12 bytes
enum { SSOSIZE = sizeof(struct _ptr) + 4 - 1 };            // 15
struct _sso { char buff[SSOSIZE]; unsigned char len : 7; unsigned char isSSO : 1; };
union { struct _ptr ptr; struct _sso sso; };
```

Strings of up to **11 characters** are stored inline. A 5-digit code lives inside the object,
so the characters really did travel inside the struct.

**Reproduce the bug in ten minutes:** change `passwordGen(5)` to `passwordGen(12)` in
`password_definitivo.ino`. The buffer moves to the heap, the struct starts carrying a pointer,
and the receiver's behaviour becomes undefined. This is the single most instructive experiment
in the repository.

---

## 2. `valigia_definitivo.ino` — briefcase main controller

### Structure

```
setup()
  ├─ pinMode for the three inter-MCU lines
  ├─ Serial (9600) and Serial2 (9600)
  ├─ display.begin(0x3C) — SH1106 128x64
  └─ Transceiver.init() + PrintParameters()

loop()
  ├─ buzzer.loop()                        // ezBuzzer, non-blocking
  ├─ if (Serial2.available())             // radio in
  │     GetStruct → password = MyData.passwordTX; Last = millis()
  │  else
  │     link-timeout state machine → nobuono
  ├─ if (!nobuono) → keypad handling
  ├─ deferred lock release + "case opened" transmission
  ├─ deferred OLED clear
  └─ if (nobuono) → read OK_IMPRONTE, energise lock
```

### Link state machine

```cpp
if (Serial2.available()) {
  Transceiver.GetStruct(&MyData, sizeof(MyData));
  password = MyData.passwordTX;
  Last = millis();
} else {
  if ((millis() - Last >= 7000) and MyData.connesso == false) {
    // link considered lost
    nobuono = true;
    // OLED alternates "LOST CONNECTION / Use fingerprint..." every 5 s
    // with the fingerprint bitmap every 10 s
  } else {
    MyData.connesso = false;
    nobuono = false;
  }
}
```

The `connesso` field arrives as `true` from the transmitter and is cleared locally on the next
pass, so **the actual liveness detection is entirely the 7-second timeout on `Last`.** The
transmitted flag is effectively redundant. It is not wrong, just more convoluted than it needs
to be, and it took a careful read to establish that.

### Keypad handling

```cpp
char key = keypad.getKey();
if (nobuono == false) {
  if (key) {
    buzzer.beep(100);
    if (key == '#') {
      if (input_password == password) {
        digitalWrite(SUONO_OK, 1);          // lock + success tune
        // OLED "Welcome Mr Minguzzi"
        delei = millis(); apro = true; welc = true; vario = millis();
      } else {
        // OLED "INCORRECT PASSWORD"
        digitalWrite(SUONO_noOK, 1);
        delay(500);                          // blocking
        digitalWrite(SUONO_noOK, 0);
        vario = millis(); incpass = true;
      }
      input_password = "";
    } else {
      input_password += key;                 // '*' included
      // echo on the OLED at text size 4
    }
  }
}
```

Notes:

- The comparison is a plain `String ==`, i.e. byte-by-byte and not constant time. Irrelevant
  at this threat level, but worth naming.
- **No attempt counter, no delay, no lockout.**
- The 500 ms `delay()` blocks the keypad, the radio and everything else.

### Lock release

```cpp
if (millis() - delei >= 1000 and apro) {
  apro = false;
  digitalWrite(SUONO_OK, 0);
  MyData.aperto = true;
  Transceiver.SendStruct(&MyData, sizeof(MyData));
}
```

GPIO19 stays high for one second, then the "opened" packet goes out. Note that this packet is
sent **once, with no acknowledgement**: if it is lost, the transmitter never generates a new
code, the briefcase keeps the old one, and the two sides silently disagree about the state of
the system.

### Fingerprint branch

```cpp
if (nobuono) {
  if (digitalRead(OK_IMPRONTE)) {
    digitalWrite(19, 1);
    delay(1000);            // blocking
    digitalWrite(19, 0);
    nobuono = false;        // one shot
  }
}
```

The literal `19` here is the same pin as `SUONO_OK`. Setting `nobuono = false` at the end
re-enables the keypad even though the radio link is still down; the next loop pass through the
timeout branch will set it back if no packet arrives.

### Display

The OLED is an SH1106 at `0x3C` driven through `Adafruit_SH110X`. A 128×64 fingerprint bitmap
is stored in `PROGMEM` (1024 bytes) and drawn during the lost-link state.

There is a small oddity in the lost-connection screen: the code prints "CONNESSIONE PERSA" at
text size 1 at cursor (0,0), then immediately prints "LOST CONNECTION" at text size 2 starting
from the same cursor position with leading spaces used for alignment. It works, but it renders
by trial and error rather than by layout.

---

## 3. `impronte_definitivo.ino` — fingerprint and audio

```cpp
Adafruit_Fingerprint finger = Adafruit_Fingerprint(&Serial2);

void setup() {
  Serial.begin(9600);
  finger.begin(57600);      // opens Serial2 on default pins 16/17
  pinMode(25, INPUT);       // SUONO_noOK
  pinMode(33, INPUT);       // SUONO_OK
  pinMode(27, OUTPUT);      // OK_IMPRONTE
}
```

`Serial2` is never opened with explicit pins, so it uses the ESP32 defaults GPIO16/17 — which
matches the report's block diagram annotation for the sensor.

The loop does three independent things:

1. If `SUONO_OK` (GPIO33) is high, play the rising tune (1480 / 1480 / 1480 / 1976 Hz).
2. If `SUONO_noOK` (GPIO25) is high, play the falling tune (1976 / 1480 Hz).
3. Every 100 ms, poll the sensor:

```cpp
bool fingerprintMatches() {
  if (finger.getImage()    != FINGERPRINT_OK) return false;
  if (finger.image2Tz()    != FINGERPRINT_OK) return false;
  if (finger.fingerSearch()!= FINGERPRINT_OK) { /* sad tone */ return false; }
  return true;
}
```

On a match it raises GPIO27, plays the success tune, and lowers GPIO27 partway through.

Known rough edges:

- `impronta_ok` holds its value between the 100 ms polls, so `if (impronta_ok)` can re-enter
  the tune block on consecutive loop passes until the next poll clears it.
- The tunes use `tone()` + `delay()`, so this board is blocked for up to ~1.5 s while playing.
  Since its only other job is polling the sensor, this is harmless here — but it is why the
  main board needed `ezBuzzer` instead.
- `getImage()` returning anything other than `FINGERPRINT_OK` covers both "no finger present"
  and "capture failed"; the code does not distinguish them.

---

## 4. `password_definitivo.ino` — code transmitter

```cpp
void loop() {
  if (Serial2.available()) {
    Transceiver.GetStruct(&MyData, sizeof(MyData));
  }
  if (MyData.aperto) {
    passwordGen(5);
  }
  if (millis() - timer_conto >= 5000) {
    timer_conto = millis();
    MyData.connesso = true;
    Transceiver.SendStruct(&MyData, sizeof(MyData));
  }
}

void passwordGen(int length) {
  String password = "";
  for (int i = 0; i < length; i++) password += String(random(10));
  MyData.passwordTX = password;
  MyData.aperto = false;
  Transceiver.SendStruct(&MyData, sizeof(MyData));
  lcd.setCursor(0, 0); lcd.print("Password:");
  lcd.setCursor(0, 1); lcd.print(password);
}
```

Simple and readable. Three things worth noting:

- `random(10)` on arduino-esp32 is backed by `esp_random()`, not the AVR seeded PRNG. However,
  ESP-IDF documents that `esp_random()` is only a true RNG when the RF subsystem (Wi-Fi or
  Bluetooth) is active or the ADC entropy source has been enabled. Neither applies here, so
  the output "should be considered as pseudo-random only".
- `MyData.aperto = false` is set inside `passwordGen`, which is what stops it firing on every
  loop pass. It works, but the flag is doing double duty as a message field and a local latch.
- The 5-second beacon means the briefcase's `password` variable is refreshed constantly, not
  only after an opening. That is why a lost "opened" packet is invisible: the beacon keeps
  arriving with the *old* code and the link looks perfectly healthy.

### What is missing compared with the report

The original report's flowchart for this unit describes a 3-minute timer, a battery percentage
calculation, and a low-battery warning below 20 %, plus a Node-RED/MQTT dashboard.

**None of that is in this sketch.** There is no networking code of any kind in any surviving
firmware. See [`ORIGINAL_REPORT_REVIEW.md`](ORIGINAL_REPORT_REVIEW.md).

---

## 5. The EBYTE library, as actually used

Only four calls from Kris Kasprzak's library appear in the project: `init()`,
`PrintParameters()`, `SendStruct()`, `GetStruct()`.

```cpp
bool EBYTE::GetStruct(const void *TheStructure, uint16_t size_) {
    _buf = _s->readBytes((uint8_t *) TheStructure, size_);
    CompleteTask(1000);
    return (_buf == size_);
}

void EBYTE::CompleteTask(unsigned long timeout) {
    // ... waits for the AUX pin to go high, or times out
}
```

What this means for the project:

| Feature | Present? |
|---|---|
| Acknowledgement | **No** — not in the library, not in the sketches |
| Retries | **No** |
| Sequence numbers | **No** |
| Message type / length field | **No** |
| Application-level CRC | **No** — the E32's FEC is internal and invisible |
| Timeout | Two, neither of them an application timeout: `CompleteTask(1000)` waits on AUX, and `Stream::readBytes` has a 1000 ms default |
| Error handling | **No** — the boolean return values are never read |

Nothing in the project configures the modules from firmware. `int Chan;` is declared in both
sketches and never used. All parameters were set once with EBYTE's Windows tool over an
FTDI232 adapter, and stored in the modules' own flash — which is why they survive power
cycles, and why the configuration screenshot in the report is the authoritative record of them.

---

## 6. Reading the code today: a short list of things to fix first

If anyone (including future me) picks this up:

1. **Frame the link.** Start delimiter, length, message type, sequence number, CRC-16. Read
   byte-at-a-time into a state machine. This alone should remove most of the observed packet loss.
2. **Stop sending `String` in a struct.** Use a fixed `char code[8]` and a packed struct, or
   serialise explicitly.
3. **Check return values.** `SendStruct` and `GetStruct` both return a boolean nobody reads.
4. **Remove the blocking `delay()` calls** from `valigia_definitivo.ino` — the codebase already
   uses `millis()` timers everywhere else, so this is a consistency fix, not a redesign.
5. **Move the keypad column off GPIO12.**
6. **Separate the lock pin from the inter-MCU signal pin.**
7. **Delete the second microcontroller** by remapping `Serial1`:
   `Serial1.begin(57600, SERIAL_8N1, 26, 27);`
8. **Change the hard-coded `"1234"`.**

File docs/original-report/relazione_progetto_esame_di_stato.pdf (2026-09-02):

Alunno: Andrea Minguzzi | Classe: 5 Ben Anno: 2023-2024

# Progetto esame 2024

## Indice:

1. L’idea | pag. 02
2. Schema a blocchi e descrizione del sistema. | pag. 03
3. Il gruppo di potenza | pag. 07
4. Il microcontrollore | pag. 10
5. Il sensore di impronte digitali | pag. 12
6. Il modulo LoRa | pag. 15
7. Il codice | pag. 22
8. L’integrazione con NODE-RED | pag. 24
9. Realizzazione pratica e test | pag. 26
10. Difetti e possibili miglioramenti | pag. 31
11. Conclusioni | pag. 32

## 1. L’idea

Introduzione al Progetto
Il progetto consiste nello sviluppo di una valigetta che integra diversi componenti elettronici e moduli di comunicazione per garantire un accesso sicuro. Questa valigetta, simile a una classica 24 ore, utilizza un tastierino numerico per l'immissione di un codice di sblocco e incorpora diversi sensori e attuatori per il controllo dell'apertura. In caso di perdita di connessione, un sistema alternativo basato su un sensore di impronte digitali permette di garantire comunque l'accesso autorizzato. La comunicazione tra la valigetta e un sistema remoto è gestita tramite moduli LoRa, garantendo la trasmissione sicura delle informazioni di stato e aggiornamenti.

Funzionalità Chiave
La valigetta utilizza un tastierino numerico per consentire l'inserimento di un codice di sblocco. Ogni numero inserito viene accompagnato da un bip emesso da un buzzer statico, fornendo un feedback immediato all'utente. Se il codice immesso è corretto, un secondo buzzer emette un suono "felice" e un segnale di un ESP32 attiva una elettroserratura. L'elettroserratura è collegata all'alimentazione tramite un transistor di potenza.

Una volta sbloccata la valigetta, l'ESP32 invia un messaggio tramite un modulo LoRa ebyte 433t30d indicando che la valigetta è stata aperta. Il messaggio viene ricevuto da un modulo LoRa corrispondente che lo comunica al suo ESP32, il quale procede a generare e inviare una nuova password per la successiva apertura.

In caso di perdita di connessione, il tastierino diventa inutilizzabile e un display I2C sulla valigetta indica all'utente di utilizzare il sensore di impronte digitali. Se l'impronta digitale combacia, la valigetta si apre; in caso contrario, rimane chiusa.

## 2. Schema a blocchi e descrizione del sistema

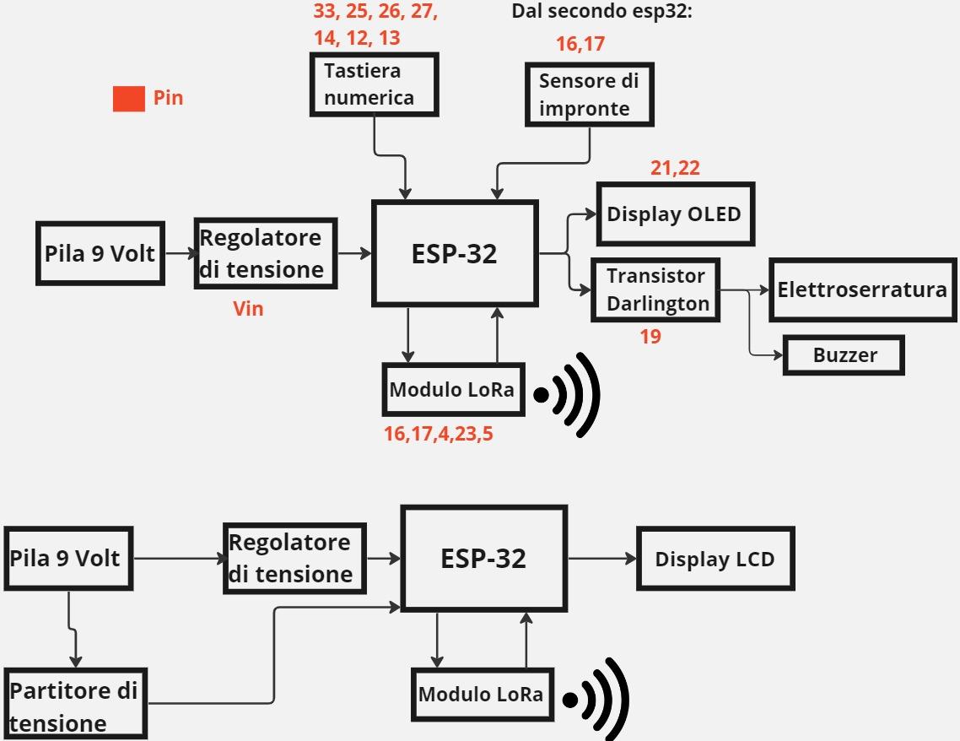
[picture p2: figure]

Lo schema a blocchi del sistema ci aiuta a capire in modo più semplice i componenti su cui si basa il principio di funzionamento del sistema. In rosso sono evidenziati i pin dei sensori collegati ai dispositivi.
Le interfacce utilizzate sono:
- Interfaccia seriale UART, usata per il sensore di impronte digitali e per i moduli LoRa
- I2C, usato per i due display, uno LCD più semplice ed economico e uno OLED più piccolo ma con caratteristiche più performanti.
Successivamente ogni blocco verrà illustrato in maniera approfondita.

### 2.1 Il diagramma di flusso del sistema trasmettitore di password

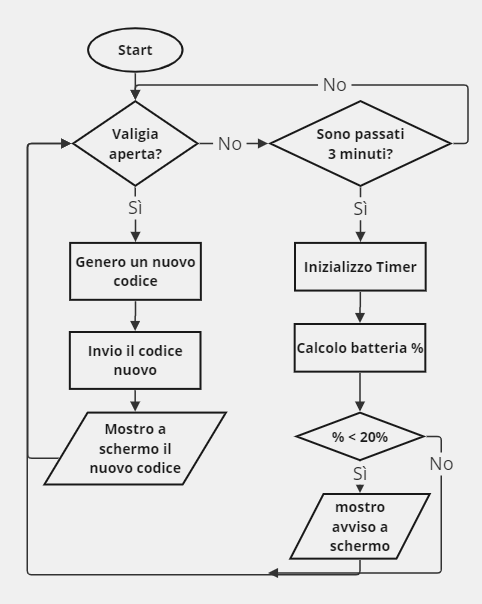
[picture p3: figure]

Il primo diagramma di flusso illustra il processo di gestione del trasmettitore di password, includendo i controlli sugli invii e il monitoraggio del livello della batteria.

Il processo inizia con un controllo per determinare se la valigia è stata aperta. Se la valigia è stata aperta, il sistema genera un nuovo codice di sicurezza, lo invia e lo visualizza a schermo e su display. Questo garantisce che ogni volta che la valigia viene aperta, un nuovo codice viene generato per migliorare la sicurezza.
Se la valigia non è aperta, il sistema verifica se sono passati tre minuti dall'ultimo controllo. Se sono passati tre minuti, il timer viene reimpostato e il sistema calcola la percentuale di batteria rimanente. Se la batteria è inferiore al 20%, viene visualizzato un avviso sullo schermo per informare all’utilizzatore della bassa carica della batteria. Se la batteria è superiore al 20%, o se non sono passati tre minuti, il sistema ritorna al controllo iniziale per verificare se la valigia è stata aperta.

### 2.1 Il diagramma di flusso del sistema all’interno della valigia

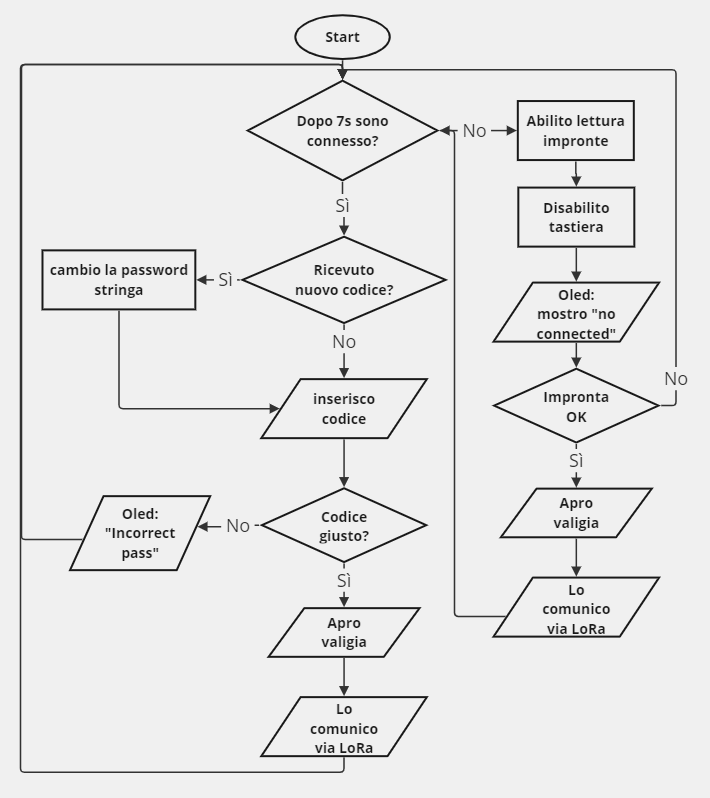
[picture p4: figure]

Il secondo diagramma di flusso descrive il processo di verifica della connessione e dell'autenticazione tramite codice e impronta digitale per l'apertura della valigia.
Il processo inizia verificando se la valigia è connessa dopo sette secondi. Se la connessione è stabilita, il sistema verifica se è stato ricevuto un nuovo codice di accesso. Se un nuovo codice è stato ricevuto, la password della valigia viene aggiornata con il nuovo codice.
Se non è stato ricevuto un nuovo codice, il sistema permette all'utente di inserire manualmente il codice di accesso. Se il codice inserito è corretto, la valigia si apre e l'evento viene comunicato tramite la rete LoRa. Se il codice è errato, viene mostrato un messaggio di errore ("Incorrect password") sul display OLED e il sistema ritorna al controllo iniziale della connessione.
Se la connessione non è stabilita entro sette secondi, il sistema abilita la lettura delle impronte digitali e disabilita la tastiera. Viene mostrato un messaggio "no connected" sul display OLED.
Se l'impronta digitale inserita è corretta e viene inserita l’apposita chiave, la valigia si apre. Se l'impronta digitale non è corretta, il sistema ritorna al controllo iniziale della connessione.

## 3. Il gruppo alimentazione

Il sistema è alimentato da una normale batteria da 9V, fornisce una tensione sufficiente per alimentare tutti i componenti per un tempo prolungato. Queste batterie sono note per la loro durata, adatte per applicazioni di hobbistica.
Nel mio progetto, oltre al monitoraggio della batteria da 9V tramite software, ho incluso un piccolo voltmetro all'interno della valigetta (foto qui a destra). Questo strumento permette di controllare visivamente e rapidamente lo stato di carica della batteria.

### 3.1 Il regolatore di tensione:

L'integrato LM7805, come alimentatore stabilizzato, svolge un ruolo fondamentale nel convertire la tensione di ingresso più alta, intorno a 9 volt, in una tensione stabilizzata continua di 5 volt 土0,1V. Per ridurre le fluttuazioni dovuti ai disturbi e garantire una tensione di uscita stabile, sono necessari condensatori elettrolitici e ceramici posizionati vicino all'integrato LM7805. I condensatori elettrolitici, di solito di grandi dimensioni (nel nostro caso 10μF), vengono utilizzati per fornire una maggiore capacità di annullamento delle
fluttuazioni di tensione. Essi immagazzinano energia durante le fasi di alta tensione e la rilasciano durante le fasi di bassa tensione, aiutando a livellare il segnale di uscita e a ridurre il ripple.
D'altra parte, i condensatori ceramici, che sono più piccoli (100 nF) e hanno una risposta più rapida alle variazioni di tensione, vengono utilizzati per filtrare le alte frequenze e fornire un'ulteriore protezione contro le interferenze. Posizionare sia i condensatori elettrolitici che quelli ceramici vicino all'integrato LM7805 riduce la lunghezza dei percorsi dei cavi e minimizza l'induttanza e la resistenza parassite, consentendo ai condensatori di svolgere il loro ruolo in modo più efficace e di evitare di inserire un filtro LC.
I convertitori di tensione, quando convertono una tensione, producono calore convertendo una tensione più alta in una più bassa. Per dissipare
questo calore, è stata implementata un'aletta di raffreddamento che
viene posta non a contatto diretto con l’aletta di raffreddamento ma viene posta tra i due della pasta termica. La pasta termica, spalmata tra

l'integrato LM7805 e l'aletta di raffreddamento, favorisce una migliore conduzione del calore, consentendo al calore prodotto dall'integrato LM7805 di trasferirsi più efficientemente all'aletta di raffreddamento, che a sua volta dissipa il calore nell'ambiente circostante. Questa soluzione aiuta a mantenere la temperatura dell'alimentatore entro limiti accettabili.

Schema del circuito di alimentazione:

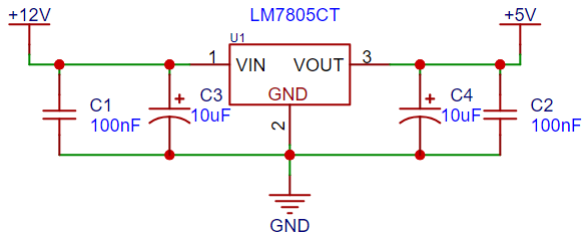
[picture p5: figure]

3.2 L’elettroserratura e il condizionamento dell’interfaccia.
Ho deciso di inserire qui l’interfaccia della serratura in questa sezione perché si tratta comunque della parte di potenza del nostro circuito.
Un solenoide consiste in una bobina di filo attraverso cui fluisce corrente elettrica, generando un campo magnetico. Questo campo magnetico attira un nucleo metallico mobile all'interno della bobina, causando il movimento
che può essere utilizzato per attuare meccanismi come l'apertura
della serratura.
L'elettroserratura utilizzata per controllare l'accesso alla valigetta è quindi un solenoide (foto a fianco), il quale funziona attirando un perno metallico che permette di sbloccare la serratura.
Il meccanismo di azionamento del solenoide richiede molta corrente, che non può essere fornito direttamente dai comuni circuiti di controllo basati su microcontrollore a causa dei loro limiti di corrente. Per questo motivo, l'attivazione del solenoide è gestita tramite un transistor Darlington, che è in grado di gestire correnti elevate permettendo così di attivare il solenoide in modo
efficace e sicuro.

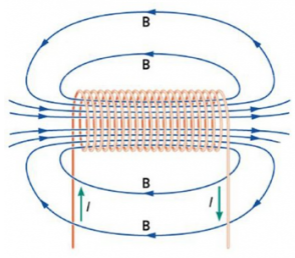
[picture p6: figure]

### 3.2.1 Perché un transistor in configurazione Darlington è più adatto?

Un transistor in configurazione Darlington è particolarmente adatto per applicazioni che richiedono un'elevata guadagno di corrente, grazie alla sua capacità di amplificare notevolmente il segnale in ingresso.
La configurazione Darlington combina i guadagni di corrente (hFE) dei due transistor. Se ogni transistor ha un hFE di, per esempio, 100, il guadagno complessivo può essere teoricamente il prodotto dei singoli guadagni, risultando in un hFE complessivo di 10,000.
Il calcolo è dato dal prodotto degli hFE come ad esempio:

Il transistor scelto è un BDX53C (schema interno in basso), possiede una tensione di collettore-emettitore di 100V e una corrente di collettore massima di 8A. Inoltre è già dotato di resistenze di protezione e diodo di ricircolo, di cui il funzionamento è spiegato successivamente.

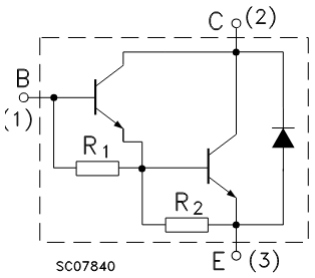
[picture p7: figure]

Per calcolare la resistenza di base si dovrebbero utilizzare tutte le formule teoriche per il calcolo della Ib e Vbb, tenendo conto delle cadute di tensioni. Personalmente ho preferito il metodo empirico per trovare la giusta resistenza. Dopo vari test ho scoperto che la giusta resistenza di base è di 1KΩ.

Un problema dei solenoidi, e in generale degli induttori, sorge quando la corrente viene interrotta. Infatti il campo magnetico scompare ma si trasforma in una corrente di verso opposto a quella originaria. Se quest’ultima non ha via di uscita ed è molto alta, può rompere il circuito.
Ecco che il transistor è dotato di diodo di ricircolo per permettere alla corrente di circolare finché non si esaurisce.

## 4. Il microcontrollore

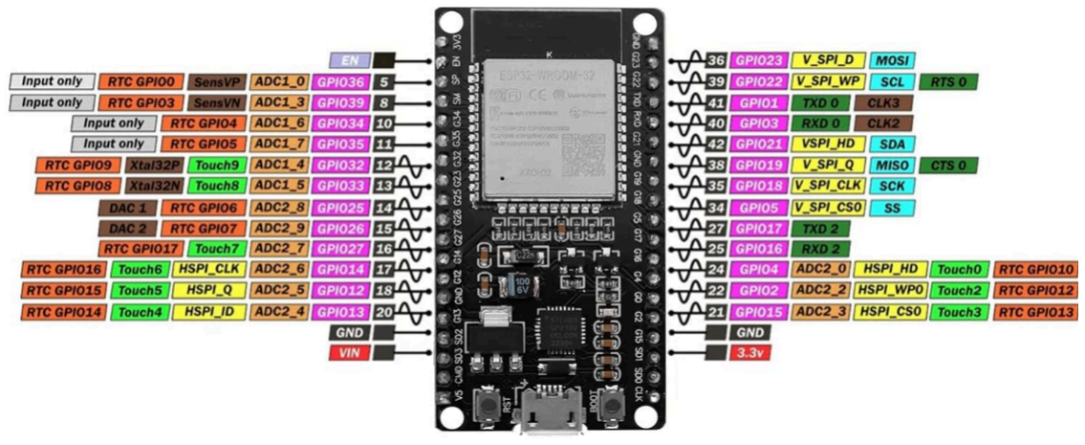
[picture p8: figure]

L'ESP32, sviluppato da Espressif Systems, rappresenta una significativa evoluzione nel campo dei microcontrollori, specialmente per le sue notevoli capacità di connettività wireless, come Wi-Fi e Bluetooth. Questo dispositivo si distingue per la sua CPU dual-core che può operare fino a 240 MHz, fornendo una robusta base hardware per l'esecuzione di applicazioni complesse e multitasking.

L'ESP32 integra una vasta gamma di funzionalità che vanno oltre quelle tipicamente offerte dai microcontrollori tradizionali. Oltre alla sua architettura dual-core, l'ESP32 supporta una varietà di periferiche come ADC (di tipo SAR) a 12 bit, due DAC a 8 bit. Inoltre è predisposto alle interfacce più comuni come I2C e SPI. La sua capacità di gestire multiple connessioni e trasferire dati a piattaforme cloud lo rende particolarmente adatto per sviluppare soluzioni nell'ambito dell'IoT. La gestione avanzata dell'energia dell'ESP32 permette di ottimizzare il consumo nei dispositivi portatili e nelle applicazioni alimentate a batteria, rendendolo ideale per un ampio spettro di scenari d'uso.

### 4.1 Un breve confronto con Arduino Uno:

Arduino Uno, uno dei microcontrollori più amati per i makers, basa la sua forza sulla semplicità di utilizzo e sull'ampia comunità di supporto. Tuttavia, l'Arduino Uno non dispone di connettività integrata, e il suo processore opera a soli 16 MHz. In confronto, l'ESP32 non solo offre connettività Wi-Fi e Bluetooth integrata ma vanta anche una potenza di calcolo decisamente superiore di 240MHz.
La memoria disponibile sull'ESP32 è anch'essa molto più ampia, sia per il programma che per i dati, il che lo rende più adatto per applicazioni che richiedono la gestione di grandi quantità di informazioni. L'ESP32, quindi, si rivela più versatile per progetti che necessitano di connettività avanzata e gestione efficiente dei dati.

Tabella di confronto:
Per rendere più chiaro il confronto, ho creato una tabella riassuntiva delle caratteristiche chiave tra ESP32, Arduino Uno e il nuovo Arduino UNO R4 Wi-Fi:
/ | ESP-32 | Arduino UNO | Arduino UNO R4 Wi-Fi
CPU | Dual-core a 240MHz | One core 16MHz | One core 48MHZ
Connettività | Wi-Fi e Bluetooth | / | Integra un ESP-32 mini
Memoria | 520KB RAM + 4MB/16MB Flash | 2KB RAM + 32KB flash | 32KB RAM+ 256KB flash
I/O | vari modelli: 38,32,30 pin multiuso* | 14 I/O + 6 analogici | 14 I/O + 6 analogici
Tensione di uso | 3,3V | 5V | 5V

*multiuso: un pin può essere usato come analogico, digitale, touch ecc… Ma con un solo scopo da scegliere tra quelli proposti.

### 4.2 Perché ho preferito quindi l’ESP32 a un Arduino UNO Wi-Fi?

Ho scelto di utilizzare l'ESP32 al posto dell'Arduino Uno WiFi per diverse ragioni. Innanzitutto, l'ESP32 offre una maggiore capacità di elaborazione e più memoria, essenziale per gestire simultaneamente funzioni multiple come il controllo delle impronte digitali e la comunicazione LoRa. Inoltre, dispone di una connettività Bluetooth e Wi-Fi integrata, che è più avanzata rispetto a quella dell'Arduino Uno WiFi, utile per l’integrazione con Node-RED. Infine, l'ESP32 supporta una gamma più ampia di librerie e ha un consumo energetico più efficiente, rendendolo ideale per applicazioni portatili come la mia valigetta di sicurezza.
L’unica lato negativo dell’ESP32 è la sua operatività a 3,3V che sono però riuscito a compensare.

## 5. Il sensore di impronte digitali

### 5.1 I sensori di impronte digitali

I sensori di impronte digitali si dividono principalmente in due tipologie: ottici e capacitivi, ognuno con caratteristiche distintive che influenzano la loro applicazione in diversi dispositivi.

Sensore Ottico: Questi sensori | funzionano illuminando
l'impronta digitale | e catturando l'immagine risultante attraverso
un sensore simile a quelli usati nelle fotocamere. La loro robustezza e resistenza ai graffi li rendono ideali per applicazioni che richiedono durabilità, e il loro costo inferiore li rende accessibili per dispositivi di fascia più bassa. Tuttavia, la loro
struttura più ingombrante, | la vulnerabilità a falsificazioni | e la
sensibilità a sporco e umidità possono limitare l'uso in dispositivi
compatti o in ambienti molto umidi.

Sensore Capacitivo: Utilizzando piccole celle conduttive che misurano le variazioni di capacità elettrica create dalle creste dell'impronta digitale, questi sensori offrono immagini di alta qualità e sono molto efficaci nel prevenire le falsificazioni.
Sebbene siano più costosi da produrre, la loro velocità e precisione li
rendono preferibili per applicazioni che richiedono maggiore sicurezza e prestazioni elevate. La loro sensibilità a condizioni estreme di umidità o secchezza della pelle può però essere una limitazione in certi ambienti.

### 5.2 Principio di funzionamento

Un sensore di impronte digitali capacitivo funziona misurando le differenze di capacità elettrica causate dalle creste e dalle valli presenti sull'impronta digitale. Ogni volta che un dito viene posizionato sul
sensore, le creste (le parti rialzate dell'impronta) toccano la superficie del

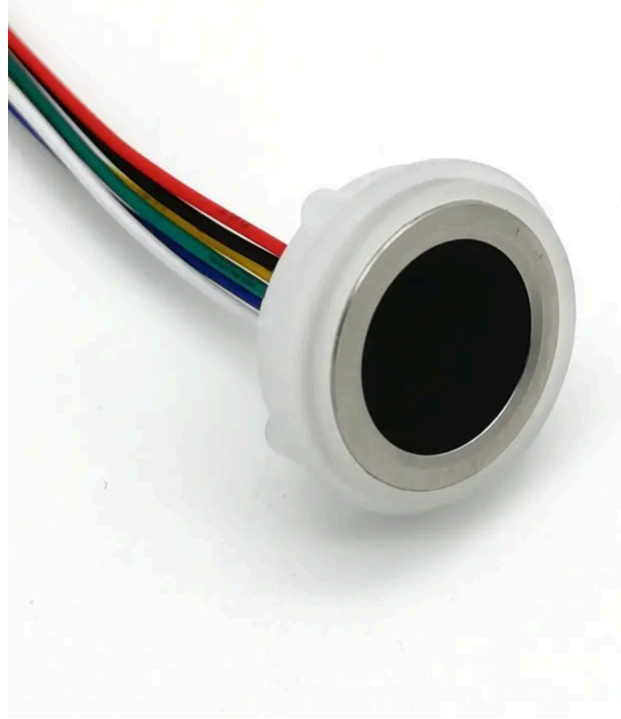
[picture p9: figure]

sensore e le valli (le parti basse) non lo fanno. Il sensore è costituito da una serie di celle convettive molto piccole, simili a una matrice di condensatori, ciascuna delle quali può misurare un cambiamento minimo nella carica elettrica quando viene toccata da una cresta o una valle.

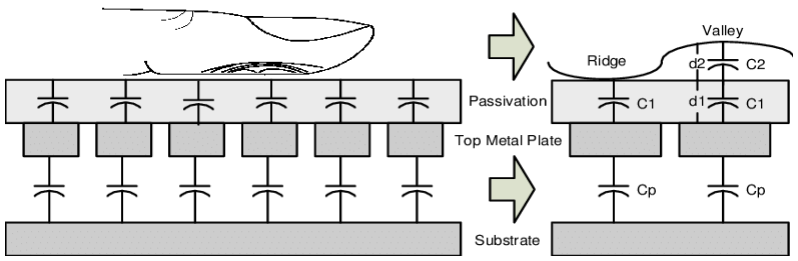
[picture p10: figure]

Quando viene poggiato il dito sul sensore, le creste creano un contatto diretto con queste celle, cambiando la loro capacità in modo prevedibile. Questi cambiamenti vengono poi convertiti in un'immagine elettronica del dito, che viene processata per creare un modello unico di impronta digitale. Questo modello è poi utilizzato per confrontare le future scansioni per autenticare l'utente.

### 5.3 Cosa riporta il datasheet

Il modulo di identificazione delle impronte digitali R557, come descritto nel manuale utente fornito dalla Hangzhou Grow Technology Co., Ltd., offre funzionalità sia per l'iscrizione delle impronte che per il loro confronto. Ecco alcune specifiche chiave:

- Interfaccia e alimentazione: Utilizza un'interfaccia UART con livelli logici TTL a 3.3V. È alimentato con 3.3V DC e presenta un consumo di corrente di 30 mA durante l'acquisizione di impronte e di circa 5μA in standby.
- Capacità e sicurezza: Può memorizzare fino a 120 impronte e offre vari livelli di sicurezza, con un tasso di falso positivo inferiore allo 0.001% e un tasso di falso negativo inferiore all'1%.
- Tempo di risposta e risoluzione: Il modulo acquisisce le immagini delle impronte in meno di 0.2 secondi con una risoluzione di 508 dpi, e può generare il file di caratteristiche dell'impronta in meno di 500ms.

Nel mio caso il modulo è anche integrato con dei LED che
mi permettono di capire se l'impronta è registrata o meno:
- Rosso: impronta non registrata
- Verde: impronta registrata
- Blu: Modulo funzionante, attesa lettura impronta

### 5.4 La sua gestione

La gestione delle impronte digitali nel mio progetto segue un percorso ben definito, attivato da due condizioni specifiche per garantire un alto livello di sicurezza.

Il primo fattore scatenante è la perdita di connessione wireless. In questo scenario, il primo modulo ESP32, che
funge da monitor della connettività, rileva un'interruzione
nella comunicazione. Di conseguenza, invia un segnale

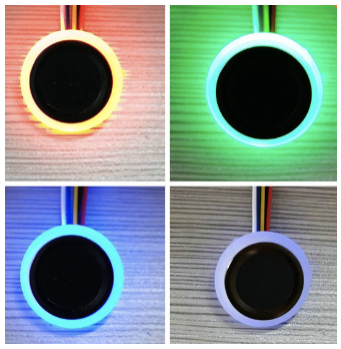
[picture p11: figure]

logico alto a un pin specifico del secondo modulo ESP32. Questo segnale funge da avviso che la connessione principale è stata compromessa e il secondo ESP32 abilita la lettura alle impronte digitali.
Nonostante questo primo passo verso l'abilitazione del sensore di impronte digitali, c'è un ulteriore livello di sicurezza prima che il sensore sia effettivamente operativo. Per attivare fisicamente il sensore di impronte, è necessario un intervento manuale: il giro di una chiave. Questa doppia misura di sicurezza assicura che l'accesso tramite impronte digitali sia consentito solo sotto circostanze controllate e intenzionali.

### 5.5 La mia esperienza di utilizzo

L'apprendimento e l'utilizzo del modulo R557 non sono stati semplici all'inizio. Dopo aver tentato di utilizzare il modulo autonomamente, mi sono trovato in difficoltà e ho deciso di contattare direttamente il produttore in Cina per chiedere aiuto. Sorprendentemente, ho ricevuto una risposta che mi ha aiutato ad andare avanti.

Ho iniziato testando il modulo con un Arduino Micro e successivamente l'ho integrato con un ESP32, il che ha ampliato le mie opzioni di connettività e ha migliorato l'efficienza dell'intera configurazione. Questa esperienza mi ha insegnato che se ho bisogno di aiuto non devo aver paura di chiedere. Questo mi è stato molto utile durante tutto l’arco del progetto.

## 6. Il modulo LoRa

### 6.1 Introduzione alla comunicazione LoRa

Nell'ambito delle tecnologie di comunicazione a lunga distanza, LoRa si distingue come una delle soluzioni più innovative. Il modulo E32-433T30D, basato sul chip RF SX1278 di SEMTECH, esemplifica l'uso efficace di
questa | tecnologia, | offrendo | una | soluzione | di
comunicazione wireless robusta e a basso consumo
energetico.

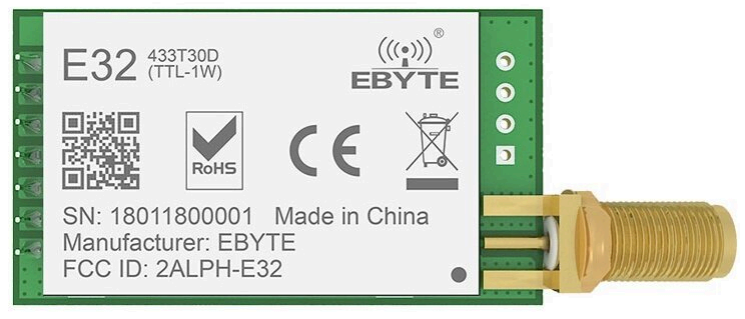
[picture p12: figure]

La tecnologia LoRa, acronimo di Long Range, utilizza una tecnica di modulazione di spread spectrum che permette una comunicazione a lungo raggio con basso consumo di energia. Questa tecnologia è particolarmente vantaggiosa per applicazioni Internet of Things (IoT), dove la connettività a lunga distanza e il basso consumo energetico sono cruciali.
Il livello fisico LoRa è proprietario; pertanto, non esiste documentazione ufficiale disponibile gratuitamente, sebbene Semtech abbia fornito una panoramica della modulazione e di altre specifiche tecniche pertinenti. Tuttavia, diversi ricercatori indipendenti l'hanno analizzato e documentato i loro risultati.
Sappiamo però alcune novità e regole da rispettare in Europa; I dispositivi LoRa dispongono di funzionalità di geolocalizzazione utilizzate per triangolare le posizioni dei dispositivi tramite timestamp dai gateway. LoRa utilizza bande di radiofrequenza sub-gigahertz libere come 433 MHz, 868 MHz e questo non solo permette di utilizzarlo su bande “libere” ma permette anche LoRa trasmissioni a lungo raggio (oltre 10 km nelle zone rurali, 3–5 km in zone fortemente urbanizzate) a basso consumo energetico.

### 6.2 La modulazione

La modulazione LoRa (Long Range), utilizzata nel modulo E32-433T30D, è una forma di modulazione che appartiene alla famiglia delle tecniche di spread spectrum, conosciuta come Chirp Spread Spectrum (CSS). Questa può essere rappresentata come una semplice modulazione FM.

LoRa impiega la tecnica di spread spectrum, che espande il segnale su una banda di frequenza più ampia rispetto a quella originale del segnale (spiegato poi il processo di scelta della frequenza portante). Questo processo riduce significativamente il rischio di interferenze e aumenta la resistenza contro i tentativi di disturbo e il rumore di fondo. La tecnica CSS utilizza segnali modulati in frequenza che cambiano linearmente nel tempo, chiamati chirps. Questi chirps sono segnali che variano la loro frequenza nel tempo, aumentandola o diminuendola, e sono particolarmente efficaci in ambienti rumorosi dal punto di vista delle radiofrequenze perché possono essere rilevati facilmente anche a bassi livelli di potenza del segnale.

I chirps sono unici nel loro genere perché offrono resistenza ai fenomeni di fading* e multipath, comuni negli ambienti urbani dove i segnali possono riflettersi su superfici come edifici o altre strutture. Questa capacità rende LoRa estremamente affidabile in contesti urbani densi. Inoltre, LoRa raggiunge una sensibilità di ricezione molto alta, nel nostro caso del modulo E32-433T30D fino a -148 dBm, permettendo di catturare segnali molto deboli che estendono la portata della trasmissione notevolmente.

Qui in figura è riportato ad esempio un segnale in modulazione CSS che sta mandando un 1 logico. La modulazione è in up-chirp, quindi aumenta la sua frequenza. Determinare il numero di chirp utilizzati, i suoi simboli e la loro ampiezza è molto complicato,

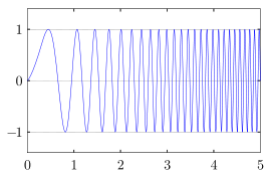
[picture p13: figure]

quindi ci limiteremo a questo concetto di variazione di frequenza.

Che Cosa Misura -148 dBm?
Il valore di -148 dBm misura la potenza del segnale al ricevitore. Specificamente, indica la minima potenza di un segnale che il ricevitore è in grado di rilevare in modo affidabile sopra il livello di rumore di fondo. Questa misura è cruciale per determinare la portata effettiva e la qualità di una comunicazione wireless, specialmente in tecnologie come LoRa, dove i segnali devono spesso viaggiare su lunghe distanze o attraverso condizioni ambientali sfavorevoli. Con una sensibilità così alta, i dispositivi LoRa possono comunicare efficacemente nonostante la presenza di segnali deboli e suscettibili di essere persi o distorti.
Il valore di -148 dBm viene calcolato usando la formula per dBm, che è:

Dove P è la potenza del segnale in milliwatt.

Per calcolare la potenza in milliwatt di un segnale che ha un livello di potenza di -148 dBm, si può ordinare la formula per risolvere per P:

Questo calcolo mostra che -148 dBm corrisponde a una potenza di circa 1.58 femtowatt (fW), un valore estremamente basso che evidenzia l'alta sensibilità del ricevitore.
* Il fading descrive una variazione temporanea e spaziale dell'intensità del segnale ricevuto a causa di diversi fattori ambientali. Esempio: più onde che arrivano al ricevitore con leggermente diversi angoli o tempi.

### 6.3 La frequenza utilizzata

La frequenza di 433 MHz è ampiamente utilizzata nei moduli wireless, inclusi quelli come il E32-433T30D. Questa banda è riservata globalmente per l'uso di dispositivi che non richiedono una licenza per la trasmissione.
Essendo una frequenza nella banda ISM (radiotrasmissioni non commerciali), la 433 MHz offre vantaggi significativi in termini di penetrazione e portata del segnale. Le frequenze più basse, come quella a 433 MHz, sono note per la loro capacità di propagarsi attraverso gli ostacoli fisici, come i muri, più efficacemente rispetto alle frequenze più alte.
Inoltre, la banda a 433 MHz tende a essere meno affollata rispetto ad altre bande più comuni come quella a 2.4 GHz, che è frequentemente utilizzata per le tecnologie Wi-Fi e Bluetooth. Questo minor traffico nella banda a 433 MHz può ridurre significativamente il rischio di interferenze.

Il modulo E32-433T30D permette anche la selezione di diversi canali, il che è essenziale per ottimizzare la comunicazione in presenza di altri dispositivi wireless nell'area. Aggiungendo il valore del canale in MHz alla frequenza base di 433 MHz, gli utenti possono regolare la frequenza operativa finale per evitare interferenze. Per esempio, scegliendo il canale 17, (come nel mio caso) la frequenza di operazione effettiva del modulo diventa 433 MHz + 17 MHz, ovvero 450 MHz.

### 6.4 L’antenna

La selezione dell'antenna in base alla frequenza di 433 MHz è fondamentale per ottimizzare le prestazioni di comunicazione dei moduli wireless. A questa frequenza, la lunghezza d'onda calcolata è circa 0.693 metri, il che influisce direttamente sulla dimensione e sul tipo di antenna da utilizzare. La lunghezza d’onda è calcolata secondo la formula: λ =

c
f
Quindi con i calcoli svolti, immaginando una antenna lunga come un quarto d’onda:

Per applicazioni che richiedono una copertura ampia e uniforme, un'antenna omnidirezionale a quarto d'onda, con una lunghezza approssimativa di 17.3 cm, è spesso la scelta ideale perché fornisce una buona ricezione del segnale in tutte le direzioni, il che è utile per dispositivi mobili come nel nostro caso.

### 6.5 Ma come funziona un’antenna? Un cenno storico

L'origine delle antenne risale alle scoperte teoriche di James Clerk Maxwell nel 1865, le cui equazioni predicevano l'esistenza delle onde elettromagnetiche. Tuttavia, fu Heinrich Hertz nel 1886 a dimostrare per la prima volta l'esistenza di queste onde. Hertz utilizzò un dispositivo rudimentale che agiva sia come trasmettitore che come ricevitore di onde radio, svolgendo esperimenti che confermavano le teorie di Maxwell. Pochi anni dopo, Guglielmo Marconi applicò queste scoperte per sviluppare il primo sistema pratico di telegrafia senza fili. Innovando nella tecnologia dell'antenna, Marconi estese notevolmente la portata della trasmissione radio, culminando con il primo segnale radio transatlantico nel 1901, che segnò l'inizio dell'era della comunicazione radio a lunga distanza.

### 6.5.1 Principio di Funzionamento

Il funzionamento delle antenne si basa sulla conversione delle correnti elettriche in onde elettromagnetiche e viceversa. Durante la trasmissione, un trasmettitore invia corrente alternata all'antenna, che produce un campo elettromagnetico oscillante. Questo campo irradia energia nello spazio sotto forma di onde radio, con una frequenza che dipende dalla corrente applicata. Inversamente, durante la ricezione, le onde radio incidenti inducono una corrente alternata nell'antenna. Questa corrente viene poi amplificata e convertita in segnali utilizzabili. La dimensione e la forma dell'antenna sono progettate per ottimizzare la ricezione e la trasmissione per specifiche lunghezze
d'onda correlate alla
frequenza | del
segnale.

Nell’immagine qui a
fianco | notiamo | il
concatenamento di
generazione di
campo elettrico in
elettromagnetico fino
al ricevitore.

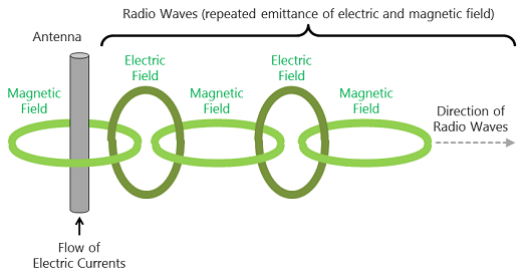
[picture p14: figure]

### 6.5.2 L’irradiazione e il suo diagramma

Un diagramma di irradiazione, noto anche come diagramma di radiazione, è una rappresentazione grafica che mostra come un'antenna irradia energia elettromagnetica nello spazio circostante. Questo diagramma illustra l'intensità del segnale emesso in diverse direzioni e può essere rappresentato in due o tre dimensioni.

Nel caso di un diagramma bidimensionale (2D a sinistra dell’immagine sottostante), come il diagramma polare, si visualizza l'intensità della radiazione in un piano specifico, offrendo una vista "tagliata" del pattern tridimensionale e mostrando come la radiazione varia con l'angolo in un dato piano, tipicamente in un piano orizzontale o in un piano verticale. Un'altra forma di rappresentazione 2D è il diagramma rettangolare, che mostra la radiazione in funzione dell'angolo e della lunghezza d’onda in un grafico cartesiano.
Un diagramma tridimensionale (3D a destra dell’immagine sottostante) fornisce una visione completa di come l'antenna irradia energia nello spazio, presentando un pattern volumetrico.

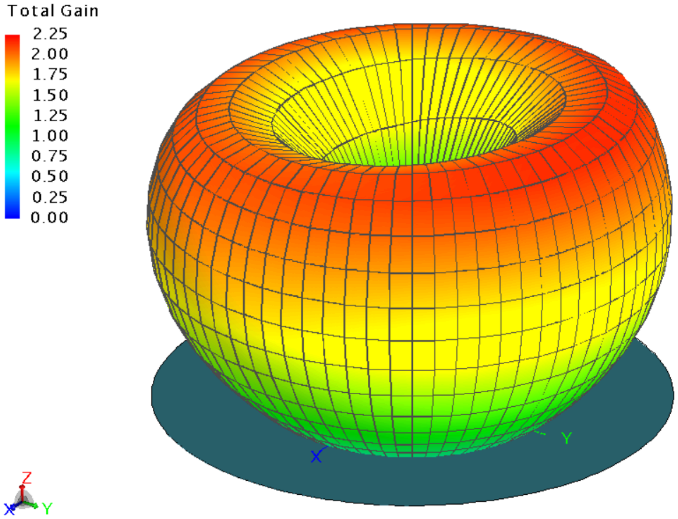
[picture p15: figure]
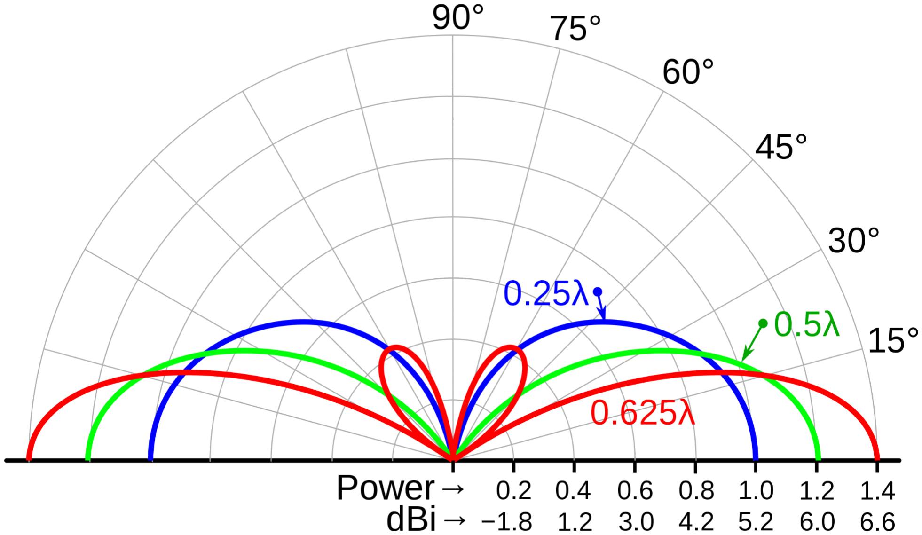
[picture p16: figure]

Qui sopra troviamo i diagrammi di irradiazione di una antenna monopolare come nel nostro caso.
Quella in 3D a destra, ha una forma emisferica simile a un toroide, con una distribuzione della radiazione che è massima lungo l'orizzonte e diminuisce verso il cielo e il terreno, confermando le caratteristiche di un'antenna monopolare. Il colore nel diagramma indica l'intensità del guadagno totale dell'antenna, con il rosso che rappresenta l'intensità maggiore e il blu quella minore.

### 6.5.3 Tipologie di Antenne e Loro Utilizzo

Esistono diverse tipologie di antenne, ciascuna adatta a specifici usi. Le antenne a dipolo sono le più semplici e comuni, costituite da due bracci metallici e ottimizzate per lunghezze d'onda specifiche. Le antenne Yagi-Uda, caratterizzate da un dipolo con elementi direttori e riflettori, sono frequentemente usate per la ricezione televisiva, offrendo un guadagno maggiore in una direzione specifica. Le antenne paraboliche, utilizzate per le comunicazioni satellitari e radar, concentrano le onde radio in un fascio stretto, permettendo comunicazioni efficaci su lunghe distanze.

### 6.6 La sua gestione

L'integrazione del modulo LoRa nel mio progetto ha richiesto una configurazione precisa dei parametri di comunicazione, come baud rate e canale, per garantire l'interoperabilità tra i moduli. Utilizzando un dispositivo FTDI232, ho programmato i moduli attraverso un'interfaccia computerizzata prima di testarli su una breadboard. La loro gestione poi è descritta successivamente nella sezione 7.1.

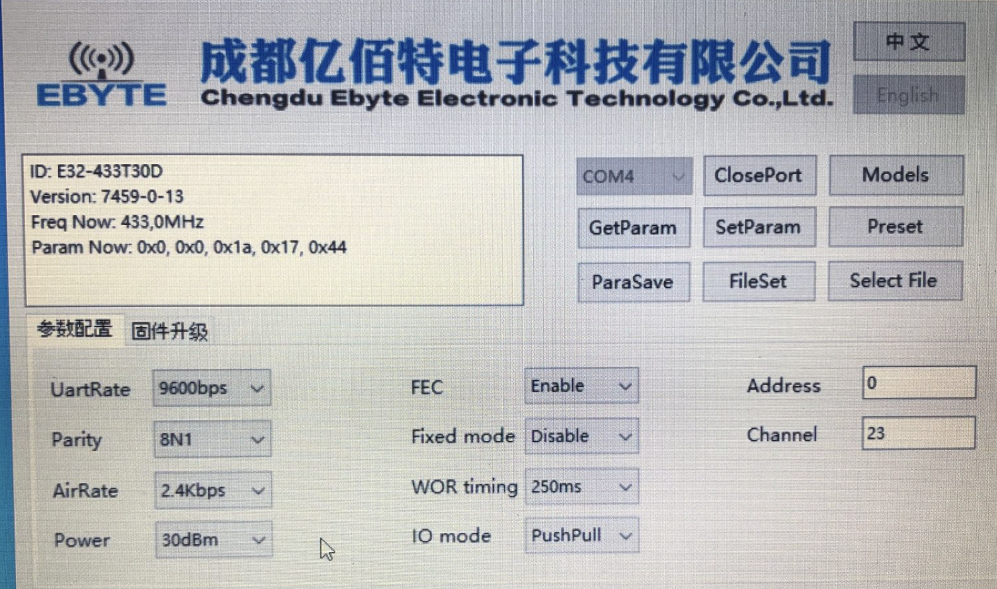
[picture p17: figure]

Nell’immagine qui in alto vediamo come si poteva configurare il modulo con i relativi parametri modificabili.
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

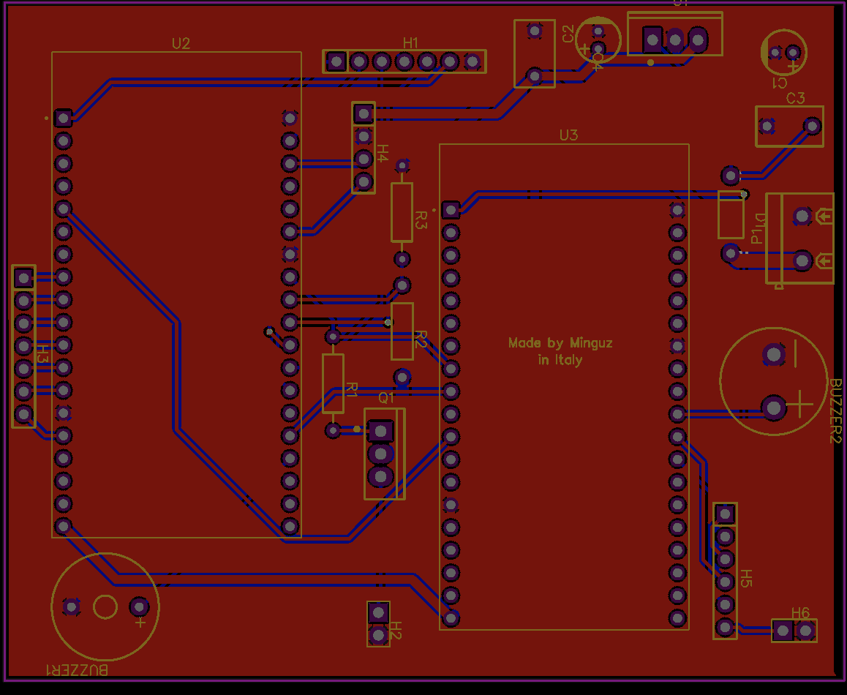
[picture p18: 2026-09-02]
hardware/pcb-v2-through-hole/photos/all-pcb.jpg

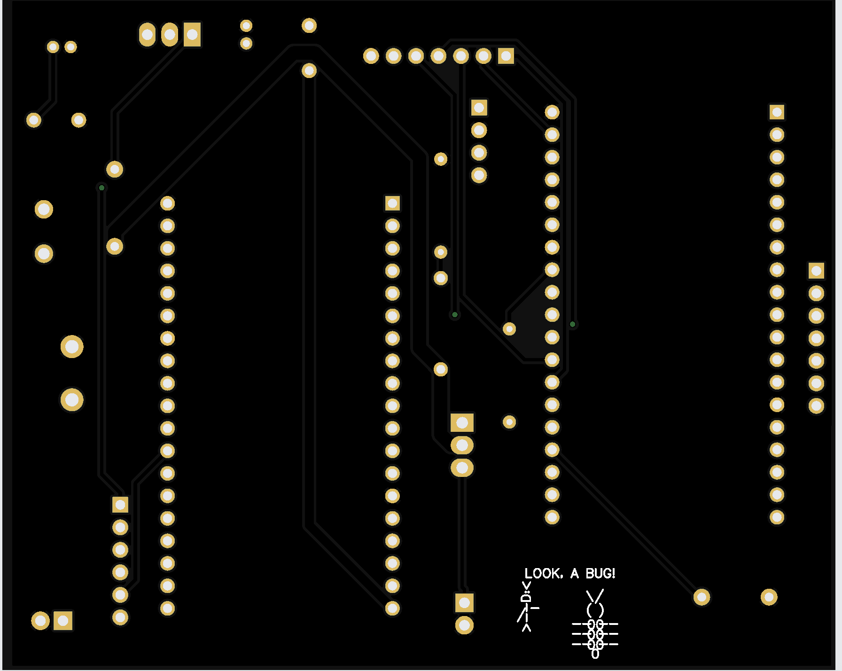
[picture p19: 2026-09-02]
hardware/pcb-v2-through-hole/photos/back-of-pcb.png

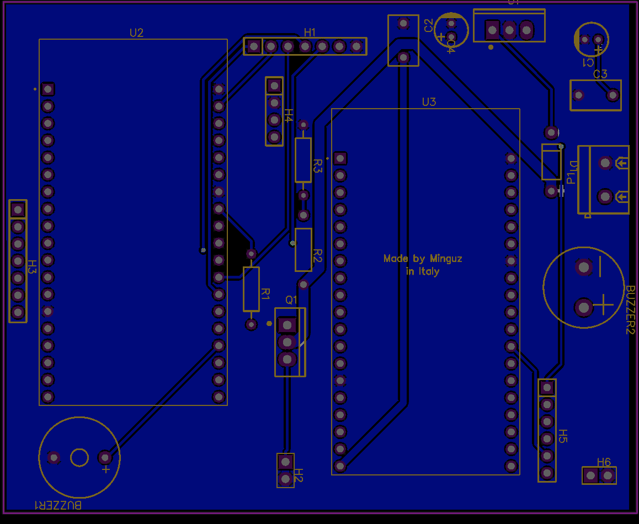
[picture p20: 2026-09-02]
hardware/pcb-v2-through-hole/photos/back-layer+ground-plane.png

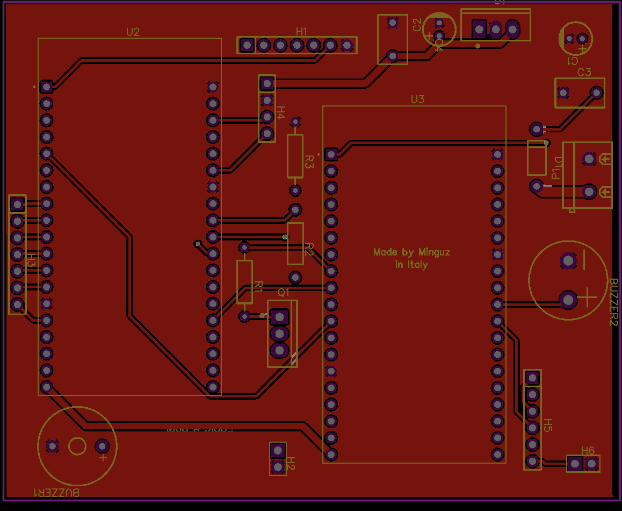
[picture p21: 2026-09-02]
hardware/pcb-v2-through-hole/photos/front-layer+groundplane.png

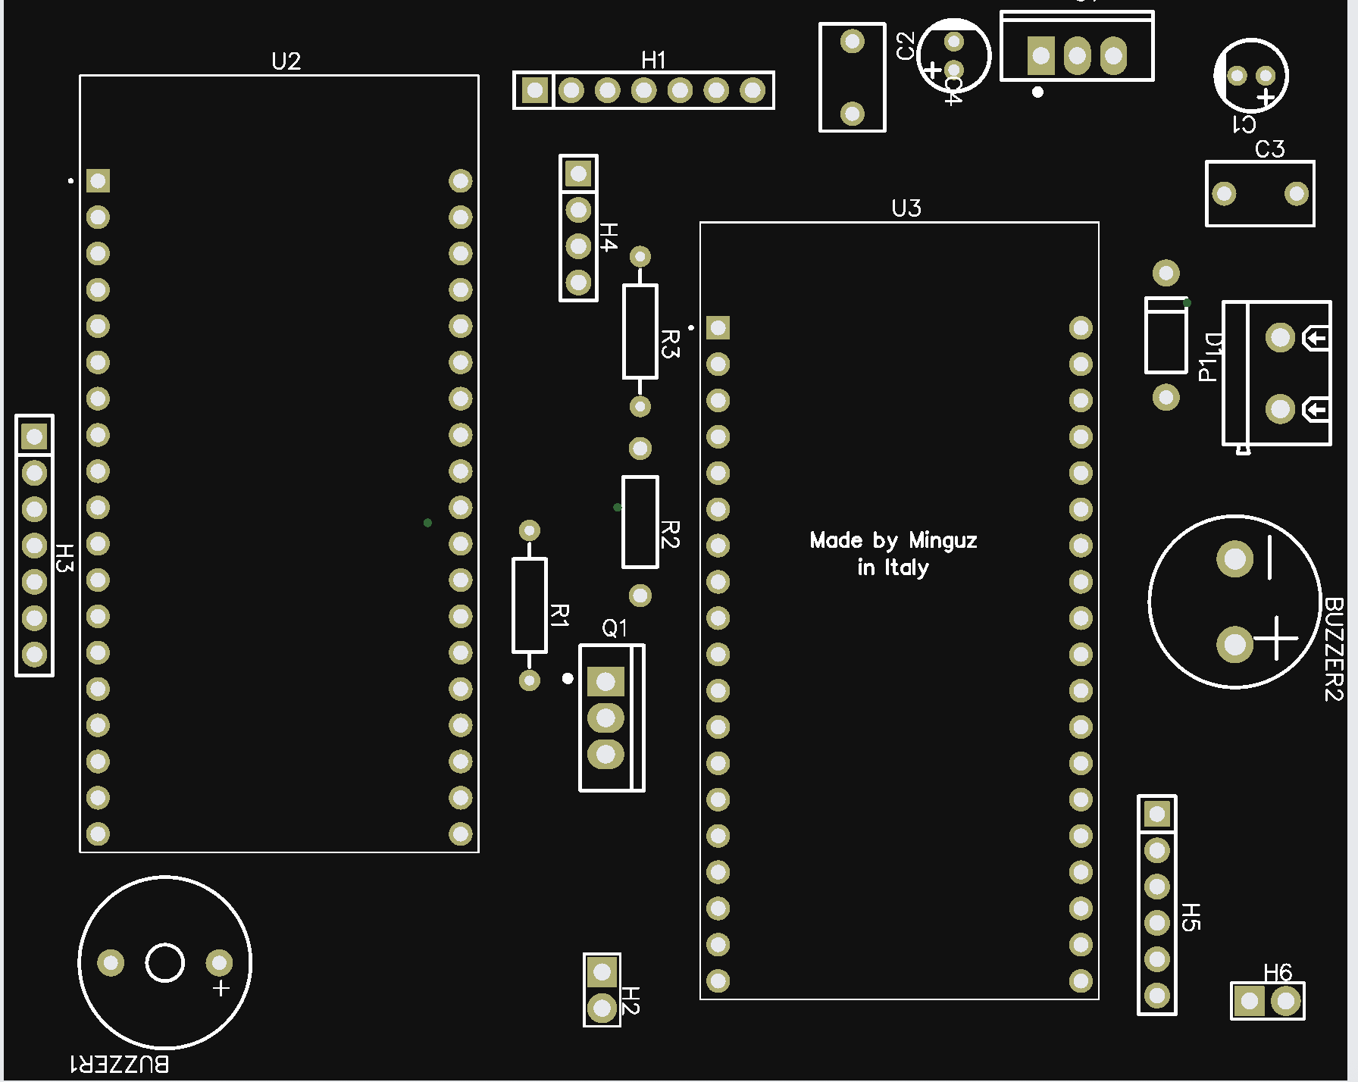
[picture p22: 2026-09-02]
hardware/pcb-v2-through-hole/photos/front-of-pcb.png

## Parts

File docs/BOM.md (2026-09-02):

# Bill of Materials

Reconstructed from the surviving sketches, the 2024 school report and photographs of the
assembled units. Quantities are for the complete system (briefcase + code transmitter).

Entries marked **[unknown]** could not be established from the surviving material and are
deliberately not guessed.

---

## Briefcase unit

| Qty | Part | Notes |
|---:|---|---|
| 2 | ESP32-WROOM-32 dev board | `U2` and `U3` on the custom PCB |
| 1 | EBYTE **E32-433T30D** | SX1278, 1 W, UART, SMA connector |
| 1 | 433 MHz quarter-wave SMA antenna | ~173 mm |
| 1 | **GROW R557** fingerprint module | Capacitive, 3.3 V UART, RGB ring, ~120 templates |
| 1 | OLED **SH1106** 128×64 I²C, address `0x3C` | |
| 1 | 4×3 matrix keypad | `1-9`, `*`, `0`, `#` |
| 1 | Barrel key switch + key | Powers the fingerprint sensor |
| 1 | Solenoid lock | **[unknown]** model; **1.7 A at 9 V** measured — but run from 18 V in the final build |
| 1 | **BDX53C** NPN Darlington, TO-220 | 100 V, 8 A, internal base resistors + freewheel diode |
| 1 | Base resistor 1 kΩ | Later replaced with 0 Ω — see KNOWN_ISSUES H-2 |
| 1 | LED | Part of the LED/LDR workaround |
| 1 | Photoresistor (LDR) | **[unknown]** model |
| 2 | Piezo buzzer | One on the PCB, one for melodies |
| 1 | **LM7805CT** regulator, TO-220 | With external heatsink and thermal paste |
| 2 | 10 µF electrolytic capacitor | Regulator input and output |
| 2 | 100 nF ceramic capacitor | Regulator input and output |
| 1 | Panel voltmeter module, 7-segment | Battery monitoring |
| 1 | 9 V 6F22 battery + clip | Zinc-carbon in the surviving photographs |
| 1 | Custom PCB rev. 2 (through-hole) | Two layers, `5803346A_Y2_240518` |
| 1 | 2-pin screw terminal | Lock output |
| — | Pin headers `H2`, `H4`, `H5`, `H6` | Keypad, OLED, fingerprint, LoRa |
| 1 | Aluminium attaché case | |
| 1 | **18 V cordless-drill battery pack** | Separate supply for the lock circuit; a stopgap that became permanent — see KNOWN_ISSUES H-4 |

---

## Code transmitter unit

| Qty | Part | Notes |
|---:|---|---|
| 1 | ESP32-WROOM-32 dev board | On a mini breadboard, never migrated to a PCB |
| 1 | EBYTE **E32-433T30D** | Marked `…08-V1.1` in the photographs |
| 1 | 433 MHz quarter-wave SMA antenna | Mounted through the wall of the box |
| 1 | LCD **1602** + PCF8574 I²C backpack (QAPASS), address `0x27` | |
| 1 | Red indicator LED | Panel-mounted in the lid |
| 1 | **LM7805CT** regulator + heatsink + thermal paste | On a small piece of perfboard |
| 2 | 10 µF electrolytic capacitor | |
| 2 | 100 nF ceramic capacitor | |
| 1 | 9 V 6F22 battery + clip | **VARTA Super Heavy Duty** — zinc-carbon |
| 1 | Rocker / toggle switch | Power |
| 1 | Trimmer potentiometer | LCD contrast, most likely |
| 2 | Resistors for the battery divider | **[unknown]** values |
| 1 | Relay module, `6A 250VAC / 10A 12VDC` | **[unknown]** purpose — not driven by any surviving firmware |
| 1 | Mini breadboard | |
| 1 | Hinged metal tin | |

---

## Firmware dependencies

| Library | Author | Used for |
|---|---|---|
| [`EBYTE`](https://github.com/KrisKasprzak/EBYTE) | Kris Kasprzak | E32 LoRa modules |
| `Adafruit_Fingerprint` | Adafruit | R557 sensor |
| `Adafruit_GFX` | Adafruit | Graphics primitives |
| `Adafruit_SH110X` | Adafruit | SH1106 OLED |
| `Keypad` | Mark Stanley, Alexander Brevig | Matrix keypad |
| `ezBuzzer` | ArduinoGetStarted | Non-blocking buzzer on the main controller |
| `LiquidCrystal_I2C` | — | LCD 1602 on the transmitter |
| `Wire`, `SPI`, `HardwareSerial` | Arduino core | |

Core: arduino-esp32. **[unknown]** exact version — see the small-string-optimisation note in
[`SOFTWARE.md`](SOFTWARE.md), where it matters.

---

## Tooling

| Item | Notes |
|---|---|
| EasyEDA | PCB design; migrated from KiCad during the project |
| JLCPCB | Board manufacture — **$2 for the boards, $15 shipping** for rev. 2 |
| EBYTE RF Setting tool + FTDI232 adapter | One-time configuration of the E32 modules |
| Arduino IDE | Firmware |

The rev. 1 SMD design was quoted at over **$120** and was never manufactured.

---

## Cost note

The through-hole decision was driven entirely by budget: $17 delivered against $120+ for the
SMD version. For a student project that trade-off was obviously right, and it brought
benefits that were not the reason for the choice — easier soldering, easier rework, and a
board that survived two years of being handled before it was finally dismantled.

---

## Sourcing notes for anyone rebuilding

Read [`KNOWN_ISSUES.md`](KNOWN_ISSUES.md) and [`REDESIGN.md`](REDESIGN.md) before buying
anything. In particular:

- **Do not buy a 9 V 6F22 for this.** It cannot supply the currents involved. A single 18650
  with a protection board costs about the same and stores two to three times the energy at a
  fraction of the internal resistance.
- **Do not buy a BDX53C for a 3.3 V GPIO.** A logic-level N-channel MOSFET with Rds(on)
  specified at Vgs = 2.5–3.0 V is cheaper, cooler and actually works.
- **Check your local radio regulations before buying a 1 W module.** In Europe the
  433.05–434.79 MHz band is limited to 10 mW ERP for licence-free use. A 20 dBm E32 variant,
  or the same module configured down, is the appropriate choice.
- The **R557 is a 3.3 V device** — its communication lines are rated for 3.6 V maximum. Do not
  drive it from 5 V logic.

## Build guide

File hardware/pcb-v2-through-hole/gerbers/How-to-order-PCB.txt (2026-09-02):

How to Order PCB

Please refer to:
https://docs.easyeda.com/en/PCB/Order-PCB

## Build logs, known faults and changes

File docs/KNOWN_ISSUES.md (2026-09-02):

# Known Issues and Limitations

Every entry is classified as one of:

- **Confirmed issue** — demonstrable from the code, the datasheets or the surviving evidence.
- **Suspected issue** — a well-reasoned hypothesis that has not been measured.
- **Historical workaround** — a deliberate hack used to get the project working at the time.
- **Needs further investigation** — cannot be settled from the surviving material.

---

## Firmware and protocol

### C-1 · No framing on the radio link — Confirmed issue

```cpp
if (Serial2.available()) {                          // one byte is enough
  Transceiver.GetStruct(&MyData, sizeof(MyData));   // 24 are demanded
```

`available() >= 1` does not mean a full packet has arrived. `readBytes` blocks up to the
Stream's 1000 ms timeout and returns a short count, which is discarded. The struct is left
half-updated and the byte stream stays **permanently misaligned** — every following read
starts mid-packet until a long enough silence resynchronises it by accident.

This is the most likely single cause of the loss floor visible in the original range tests
(see C-10).

**Fix:** a byte-oriented reader with a start delimiter, a length field and a CRC.

---

### C-2 · `String` inside a memcpy'd struct — Confirmed issue

```cpp
struct DATA { bool aperto; String passwordTX; bool connesso; };
Transceiver.SendStruct(&MyData, sizeof(MyData));
```

An Arduino `String` is an object that, above a certain length, holds a pointer into the heap.
Transmitting it by raw byte copy transmits that pointer.

It worked only because arduino-esp32's `String` uses small-string optimisation, storing up to
**11 characters inline** (`SSOSIZE = sizeof(struct _ptr) + 4 - 1 = 15`). A 5-digit code fits.
A 12-character one would not, and the receiver would dereference a pointer into the sender's
address space.

**This is the most instructive bug in the project.** It is silent, it is version-dependent,
and it would have failed the moment anyone lengthened the code.

**Fix:** `char code[8]` in a `__attribute__((packed))` struct, or explicit serialisation.

---

### C-3 · No acknowledgement, retry, sequence number or CRC — Confirmed issue

Neither the EBYTE library nor the sketches implement any of these. The only reliability
mechanism is a 5-second beacon plus a 7-second timeout.

Concrete consequence: if the "briefcase opened" packet is lost, the transmitter never
generates a new code, the briefcase keeps the old one, and **the beacon keeps arriving with
the stale code so the link looks perfectly healthy**. The two units silently disagree about
the state of the system, and the "one-time" code is no longer one-time.

The original report states that an acknowledgement system was implemented. No such mechanism
exists in the surviving firmware. Either it was in an earlier revision, or "acknowledgement"
described the beacon.

---

### C-4 · Return values never checked — Confirmed issue

`SendStruct()` and `GetStruct()` both return a boolean indicating whether the expected number
of bytes moved. Neither is ever read.

---

### C-5 · Hard-coded initial password — Confirmed issue

```cpp
String password = "1234";
```

Until the first radio packet arrives, the briefcase opens with `1234`.

---

### C-6 · The unlock code is transmitted in clear — Confirmed issue

The E32 modules run in **transparent mode**, address `0x0000`, channel `23` — every one a
factory default. Anyone within range with an unconfigured E32 receives the code.

**Fix:** challenge–response with a pre-shared key; never transmit the secret itself.

---

### C-7 · No attempt limiting — Confirmed issue

No counter, no delay, no lockout, no logging. 10⁵ codes at roughly one attempt per second is
about 28 hours worst case.

---

### C-8 · Blocking `delay()` in critical paths — Confirmed issue

`delay(500)` on a wrong code and `delay(1000)` in the fingerprint branch. During those windows
the keypad, the radio and the display are all ignored — and, given C-1, bytes arriving during
a `delay()` are exactly the ones that desynchronise the stream.

The codebase already uses `millis()` timers everywhere else, so these are inconsistencies
rather than deliberate design.

---

### C-9 · The `connesso` field is redundant — Confirmed issue

It always arrives `true` and is cleared locally on the next pass. Link liveness is decided
entirely by the 7-second timeout on `Last`. Harmless, but it makes the state machine harder to
read than it needs to be.

---

## Radio

### C-10 · The range claim rests on one unrepeated measurement — Confirmed issue

The report states a range of "approximately one kilometre" and supports it with this table:

| Distance | "Quality" |
|---|---|
| 50 m | 95 % |
| 100 m | 79 % |
| 400 m | 70 % |
| 1000 m | 62 % |

**The author does not stand behind these numbers.** They are a single unrepeated walk through
town — one run, one day, one route, roughly line of sight, counting successes out of at least
ten received beacons — presented as if it characterised the system. No variable was controlled
and the experiment was never repeated.

The table is retained here because deleting inconvenient data is the habit this repository
exists to correct. But it should be read as an anecdote, not a measurement.

The author's actual repeated experience: **the link was reliable and then, at roughly 400 m,
dropped and stayed dropped.**

**And range was never the binding constraint:**

```
FSPL(433 MHz, 1 km) ≈ 85.2 dB
P_rx ≈ 30 dBm + ~2 dBi + ~2 dBi − 85.2 dB ≈ −51 dBm
sensitivity at 2.4 kbps ≈ −140 dBm (estimated; the −147 dBm datasheet
                                    figure is measured at 0.3 kbps)
→ ~89 dB of margin
```

Even a two-ray ground-reflection model, where path loss grows as d⁴ beyond a breakpoint of a
few metres, still leaves tens of dB of margin at 400 m. With both antennas mounted outside
their metal enclosures, **a hard limit at 400 m is not something propagation explains.**

---

### C-11 · The report's stated frequency is wrong — Confirmed issue

The report says channel 17 → 433 + 17 = 450 MHz. Both halves are wrong:

- The E32 channel formula is **410 MHz + CHAN × 1 MHz**.
- The channel was not 17. The configuration screenshot shows `Param Now: 0x00, 0x00, 0x1a, 0x17, 0x44`, and `0x17` **is 23 decimal** — the module's factory default.

Real operating frequency: **410 + 23 = 433.0 MHz**, exactly what the same screenshot reports
as `Freq Now: 433.0MHz`. The error came from reading a hexadecimal value as decimal.

---

### C-12 · Operating on the most congested channel in the band — Confirmed issue

433.0 MHz exactly. The EBYTE manual explicitly advises avoiding crowded integer frequencies
such as 433.0 MHz. In a built-up area this channel is shared with gate remotes, weather
stations, car keys and sensors.

---

### C-13 · The −148 dBm sensitivity figure was quoted out of context — Confirmed issue

That value is measured at **0.3 kbps, SF12, CR 4/5**. The project ran at **2.4 kbps**, where
sensitivity is meaningfully worse. The datasheet states plainly that "the receiving sensitivity
will be reduced ... while increasing the air data rate".

---

### C-14 · 1 W at 433 MHz is not legal for licence-free use in Europe — Confirmed issue

The firmware leaves the modules at 30 dBm. The 433.05–434.79 MHz band is limited to **10 mW
ERP** for licence-free short-range devices across most of Europe — 20 dB below what this
project transmitted.

Anyone rebuilding this must reconfigure the modules to a legal power level for their
jurisdiction, or move to a band they are allowed to use.

---

### S-1 · The link dropped permanently rather than degrading — Suspected issue

The single most useful clue about the range behaviour is its *shape*, not its distance.

- **A range limit is soft and reversible.** Near the edge you get intermittent losses; step
  back towards the transmitter and it recovers. You can walk it back and forth.
- **What was actually observed is a cliff that stays.** It worked, it dropped, it did not come
  back.

The second shape is the signature of **C-1**, not of a radio limit. Because `GetStruct` reads a
fixed 24 bytes whenever a single byte is available, the first corrupted or truncated packet
leaves the byte stream permanently misaligned. The first packet lost at the edge of usable
range therefore does not cost one beacon — **it costs the link**, until a long enough silence
happens to resynchronise it.

Distance was the trigger. The receive loop is why it stayed down.

**To settle it:** instrument the receiver to log short reads and log the return value of
`GetStruct`. If the drop coincides with a short read, this is confirmed.

---

### S-2 · The radio was probably never transmitting anywhere near 1 W — Suspected issue

The E32-433T30D draws **570–670 mA** while transmitting. On the code transmitter that came
from a 9 V zinc-carbon 6F22 through an LM7805 — a cell with an internal resistance of several
ohms. The EBYTE datasheet states plainly that "the transmitting power will be lowered by
lowering the power supply voltage."

This is worth quantifying, because in free space range scales with the square root of power:

```
−20 dB of transmit power  →  10× less range
```

If supply sag left the effective output at 10–14 dBm instead of 30, the usable distance
collapses by roughly an order of magnitude — enough to turn a link that should have reached
kilometres into one that gave up in the hundreds of metres. It is also consistent with the
report's separate complaint of disconnections "for no apparent reason".

Compounding it: a quarter-wave monopole needs a ground plane to work against. Mounted on a dev
board with a few centimetres of copper, real efficiency is well below the textbook figure.

**To settle it:** a scope on the 5 V rail during a transmit burst; ideally, an RF power
measurement with the battery fitted versus a bench supply.

**Not a factor:** enclosure shielding. Both antennas were mounted outside their metal boxes on
SMA connectors.

---

## Hardware

### C-15 · The LM7805 cannot supply the lock — Confirmed issue

The solenoid draws **1.7 A at 9 V** (bench-supply measurement). An LM7805 in TO-220 is rated
**1.5 A** with adequate heatsinking, and 9 → 5 V at 1.5 A is **6 W** to dissipate. The small
heatsink fitted would have gone into thermal shutdown.

---

### C-16 · The 9 V battery cannot supply the system — Confirmed issue

The cell in the surviving photographs is a **VARTA Super Heavy Duty**, i.e. **zinc-carbon**.
Three separate problems:

1. **Capacity.** A 9 V alkaline gives ~550 mAh at a few milliamps; usable capacity collapses
   as current rises. Zinc-carbon is far worse.
2. **Internal resistance.** Six tiny cells in series, several ohms of internal resistance. The
   610 mA transmit burst is a **power** limit, not an energy one.
3. **Regulator losses.** At 300 mA the LM7805 burns 1.2 W out of ~2.7 W drawn — over 44 % of
   the energy becomes heat before it powers anything.

Order-of-magnitude runtime: ~1.7 h ideal, well under an hour in practice.

---

### C-17 · Insufficient base drive for the Darlington — Confirmed issue

```
I_base(total)  ≈ (3.3 V − 1.6 V) / 1 kΩ            ≈ 1.7 mA
internal divider loss   1.6 V / 8.7 kΩ             ≈ 0.18 mA
I_base(useful)                                     ≈ 1.5 mA

required β = 1.7 A / 1.5 mA ≈ 1130    vs    750 guaranteed (BDX53C, Vce 3 V, Ic 3 A)
```

The transistor could not saturate. It sat in the linear region, dropped several volts and
dissipated watts.

**And no resistor value fixes it.** A Darlington has two stacked base-emitter junctions; the
datasheet allows Vbe(sat) up to **2.5 V** at high current. Out of a 3.3 V rail that leaves
under a volt of headroom. **A Darlington is the wrong device for a 3.3 V GPIO**, independently
of everything else.

Two independent causes — C-15/C-16 and C-17 — each sufficient on its own.

---

### C-18 · GPIO12 used as a keypad column — Confirmed issue

GPIO12 is the MTDI strapping pin. Held high at reset, the ESP32 configures the flash for 1.8 V
and fails to boot. The `Keypad` library holds columns `OUTPUT LOW` while scanning, but at the
instant of reset the pin is still an input. A key held down in column 2 at power-up can
prevent boot.

No failure attributable to this is recorded, but the hazard is real.

---

### C-19 · GPIO19 drives both the lock and an inter-MCU signal — Confirmed issue

The same pin energises the lock driver and tells the second ESP32 to play the success tune.
It works, but it couples an actuator to a UI signal: neither can be changed independently.

---

### C-20 · GPIO34 floats while board B is in reset — Confirmed issue

GPIO 34–39 are input-only with **no internal pull-up or pull-down**. The fingerprint-match
line is undefined while board B is unpowered or resetting. A 100 kΩ external pulldown would
have made this deterministic.

---

### C-21 · The second ESP32 was avoidable — Confirmed issue

The ESP32 has three hardware UARTs. UART0 is the USB bridge; UART2 carried the LoRa module;
UART1 *appears* unusable because its default pins (GPIO 9/10) are wired to the WROOM module's
internal SPI flash. AVR-style `SoftwareSerial` does not work on ESP32 either, removing the
obvious escape hatch.

But **ESP32 UART pins are remappable through the GPIO matrix**:

```cpp
Serial1.begin(57600, SERIAL_8N1, /*RX=*/26, /*TX=*/27);
```

One line would have removed an entire microcontroller, its board area, its cost and the three
GPIO signalling lines between the two.

---

### C-22 · Report/firmware mismatch: Node-RED and battery monitoring — Confirmed issue

Section 8 of the original report describes a Node-RED dashboard over MQTT, with topics for
start/stop, code entry, battery percentage and connection status. The report's own flowchart
also describes a 3-minute timer and a low-battery warning below 20 %.

**None of it is present.** There is no networking code of any kind in any surviving firmware,
and the transmitter's timer is 5 seconds with no battery calculation.

---

### C-23 · A stale comment references hardware that is no longer in the system — Confirmed issue

`valigia_definitivo.ino` refers to an "arduino micro" reading fingerprints. Board B is an
ESP32; the Micro was only used for early standalone testing of the sensor.

---

## Historical workarounds

### H-1 · LED + photoresistor optocoupler

> *Prototype workaround used to isolate the ESP32 control signal from a separately powered
> lock-driving circuit.*

The ESP32 drives an LED; the LED illuminates an LDR; the LDR sits in the Darlington's base
path fed from the lock's **separate 18 V supply** (H-4). This removes the 3.3 V rail from the
base circuit entirely, which is why it worked — it does not "boost" anything, it sidesteps
C-17:

```
I_base ≈ (18 V − 1.6 V) / ~2 kΩ (illuminated LDR) ≈ 8 mA
required β = 3.4 A / 8 mA ≈ 425      vs   750 guaranteed
```

That is the only configuration in this project where the Darlington could actually saturate.
**The optical coupling was the mechanism; the 18 V rail was the fix.** Worth being precise
about, because for two years the LED and the LDR got the credit.

Why it is not a design:

- Response times of tens to hundreds of milliseconds, and **asymmetric** (rise much slower
  than fall).
- Resistance drifts with temperature and recent light exposure (light memory effect).
- The transfer ratio is specified nowhere: it can be tuned, not designed.
- **Ambient light can partially turn the lock on** if the shielding is imperfect. On a lock
  that is a security problem, not merely a reliability one.
- No rated isolation voltage, so it is not actually isolation.
- Many LDRs contain cadmium sulphide and are RoHS-restricted.

A PC817 or TLP291 costs about €0.20, switches in microseconds, and has a specified CTR.

---

### H-2 · The 0 Ω base resistor

Fitted when 1 kΩ did not work. It violates the ESP32's 40 mA absolute maximum per pin, drags
the GPIO output voltage down, and leaves the underlying headroom problem untouched.

---

### H-4 · An 18 V cordless-drill battery as the lock supply

In the final working configuration the lock circuit was fed from an **18 V cordless-drill
battery pack**, wired in as a stopgap and never replaced.

It was the right instinct — a 5-cell Li-ion pack has milliohms of internal resistance, which is
everything a 6F22 is not — applied without doing the arithmetic:

- **Roughly double the solenoid's working voltage.** At 9 V the coil drew 1.7 A; at 18 V, for a
  largely resistive coil, that is on the order of 3.4 A and **four times the power** — around
  60 W dissipated in the coil while energised. It survived only because it was energised for
  about a second at a time, a handful of times. Held on continuously the coil would have been
  the first thing to fail.
- **The Darlington was over-dissipating too**, at something over 5 W in an unheatsinked TO-220.
- **But it is also the reason the workaround worked** — see H-1.

---

### H-3 · The physical key as a second factor

The key switch simply supplies power to the fingerprint sensor; the firmware knows nothing
about it. This started as a wiring convenience and ended up being, arguably, the most
genuinely secure element in the design.

Not really a *problem* — but it is a workaround in the sense that the security property is
mechanical and accidental rather than designed.

---

## Needs further investigation

### N-1 · The fingerprint sensor appearing "bound" to one ESP32

The recollection is that after being used with one ESP32, the R557 seemed not to work with
another board.

**This repository does not claim the sensor binds to a controller, because it almost certainly
does not.** The R557 stores templates in its own flash, so enrolment is portable by
construction.

What the module *does* keep in flash, any of which would produce exactly this symptom:

- the **UART baud rate** (`SetSysPara`),
- the **4-byte handshake password** (`VfyPwd`),
- the **4-byte device address**.

Change any of them during experiments and a second host using library defaults fails to
handshake and appears dead.

Compounding factor: the report records that the sensor was first tested with an **Arduino
Micro**, which drives 5 V logic. The R557's communication lines are specified for **3.6 V
maximum**. Sustained over-driving is a plausible way to degrade an input.

**To settle it:** connect the sensor to a known-good ESP32 and sweep the baud rate while
attempting `verifyPassword()`; then try the default password and address explicitly.

---

### N-2 · Actual current consumption

The figures of ~300 mA (briefcase) and ~150 mA (transmitter) are recollections, not
measurements. They are plausible — two ESP32-WROOMs with the radio off sit at 40–70 mA each —
but nothing in the surviving material measures them.

**This can no longer be settled.** The hardware was dismantled in September 2026, so the
figures stay recollections permanently. It is the main reason this repository leans on
datasheet arithmetic rather than measurement — and a good argument for measuring things while
you still have the board in front of you.

---

### N-3 · The lock's nominal ratings

Only one data point survives: **1.7 A at 9 V** on a bench supply. The model number, nominal
voltage, duty-cycle rating and coil resistance are all unknown. A solenoid lock rated for
intermittent duty that is held on continuously will overheat.

---

### N-4 · The solenoid's actual ratings

Two data points survive: **1.7 A at 9 V** on a bench supply, and the fact that it was run from
18 V in the final build (H-4). The model number, nominal voltage, duty-cycle rating and coil
resistance are all unknown, and the hardware no longer exists to measure.

The 3.4 A figure used throughout this documentation assumes a largely resistive coil and
should be read as an order of magnitude, not a measurement.

---

### N-5 · The enrolment sketch

Not among the surviving files. `impronte_definitivo.ino` can match a finger but cannot register
one — it only calls `getImage()`, `image2Tz()` and `fingerSearch()`.

The best available evidence is a string it still prints at startup:
`"Adafruit Fingerprint sensor enrollment"`. That is a leftover from Adafruit's `enroll`
example, which is what the file was started from, and strongly suggests the templates were
registered by running that stock example once from a separate sketch that no longer survives.

---

## Resolved since the original documentation pass

Kept here so the reasoning trail is visible rather than silently edited away.

| Question | Answer |
|---|---|
| Was the briefcase antenna inside the aluminium case? | **No** — mounted outside, on an SMA connector, like the transmitter's. Enclosure shielding is not an explanation for the link behaviour |
| What powered the lock circuit? | An **18 V cordless-drill battery pack** — see H-4 |
| Did the firmware read the key switch? | **No.** Verified in both sketches: no key pin is declared or read. The switch is in series with the sensor's supply |
| Was the Node-RED dashboard real? | **No.** See C-22 |
| Do the PCB source files survive? | The EasyEDA project does not; the **Gerbers are recoverable from the JLCPCB order history** |

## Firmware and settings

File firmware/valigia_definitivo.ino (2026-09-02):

//RX
#include <Keypad.h>           // libreria per l'utilizzo del tastierino
#include <ezBuzzer.h>         // libreria per l'utilizzo del cicalino
#include <string.h>           // libreria per l'utilizzo delle funzioni stringa
#include <HardwareSerial.h>   // libreria per l'utilizzo delle porte hardware seriali
#include "EBYTE.h"            // libreria per l'utilizzo del modulo LoRa
#include <SPI.h>              // libreria per l'utilizzo del display i2c
#include <Adafruit_GFX.h>     // libreria per l'utilizzo di dunzioni grafiche del display
#include <Adafruit_SH110X.h>  // libreria per l'utilizzo del display i2c e garantirne la compatibilità
#include <Wire.h>             // libreria per l'utilizzo del wiring automatico


#define i2c_Address 0x3c                                                                      // indico l'indirizzo del mio display
#define SCREEN_WIDTH 128                                                                      // definisco la sua larghezza in pixel
#define SCREEN_HEIGHT 64                                                                      // definisco l'altezza in pixel
#define OLED_RESET -1                                                                         //   QT-PY / XIA
Adafruit_SH1106G display = Adafruit_SH1106G(SCREEN_WIDTH, SCREEN_HEIGHT, &Wire, OLED_RESET);  // oggetto display che ne riporta tutte le caratteristiche
// 'download', 128x64px
const unsigned char myBitmapdownload[] PROGMEM = {  // questa struttura mi permette di visualizzare una immagine particolare
  0x00, 0x00, 0x00, 0x00, 0x00, 0x00, 0x00, 0x00, 0x00, 0x00, 0x00, 0x00, 0x00, 0x00, 0x00, 0x00,
  0x00, 0x00, 0x00, 0x00, 0x00, 0x00, 0x00, 0x00, 0x00, 0x00, 0x00, 0x00, 0x00, 0x00, 0x00, 0x00,
  0x00, 0x00, 0x00, 0x00, 0x00, 0x00, 0x00, 0x00, 0x00, 0x00, 0x00, 0x00, 0x00, 0x00, 0x00, 0x00,
  0x00, 0x00, 0x00, 0x00, 0x00, 0x00, 0x00, 0x00, 0x00, 0x00, 0x00, 0x00, 0x00, 0x00, 0x00, 0x00,
  0x00, 0x00, 0x00, 0x00, 0x00, 0x00, 0x00, 0x00, 0x00, 0x00, 0x00, 0x00, 0x00, 0x00, 0x00, 0x00,
  0x00, 0x00, 0x00, 0x00, 0x00, 0x00, 0x00, 0x07, 0x00, 0x00, 0x00, 0x00, 0x00, 0x00, 0x00, 0x00,
  0x00, 0x00, 0x00, 0x00, 0x00, 0x00, 0x01, 0xe0, 0x3c, 0x00, 0x00, 0x00, 0x00, 0x00, 0x00, 0x00,
  0x00, 0x00, 0x00, 0x00, 0x00, 0x00, 0x02, 0x00, 0x03, 0x00, 0x00, 0x00, 0x00, 0x00, 0x00, 0x00,
  0x00, 0x00, 0x00, 0x00, 0x00, 0x00, 0x00, 0x3f, 0xf0, 0xc0, 0x00, 0x00, 0x00, 0x00, 0x00, 0x00,
  0x00, 0x00, 0x00, 0x00, 0x00, 0x00, 0x01, 0x80, 0x07, 0x30, 0x00, 0x00, 0x00, 0x00, 0x00, 0x00,
  0x00, 0x00, 0x00, 0x00, 0x00, 0x00, 0x03, 0x0f, 0xe1, 0xd8, 0x00, 0x00, 0x00, 0x00, 0x00, 0x00,
  0x00, 0x00, 0x00, 0x00, 0x00, 0x00, 0x0c, 0x60, 0x1e, 0x30, 0x00, 0x00, 0x00, 0x00, 0x00, 0x00,
  0x00, 0x00, 0x00, 0x00, 0x00, 0x00, 0x19, 0x8f, 0xf1, 0x98, 0x00, 0x00, 0x00, 0x00, 0x00, 0x00,
  0x00, 0x00, 0x00, 0x00, 0x00, 0x00, 0x36, 0x38, 0x0c, 0x4c, 0x00, 0x00, 0x00, 0x00, 0x00, 0x00,
  0x00, 0x00, 0x00, 0x00, 0x00, 0x00, 0x2c, 0xc0, 0x03, 0x36, 0x00, 0x00, 0x00, 0x00, 0x00, 0x00,
  0x00, 0x00, 0x00, 0x00, 0x00, 0x00, 0x59, 0x0f, 0xf8, 0x9a, 0x00, 0x00, 0x00, 0x00, 0x00, 0x00,
  0x00, 0x00, 0x00, 0x00, 0x00, 0x00, 0x26, 0x30, 0x03, 0x69, 0x00, 0x00, 0x00, 0x00, 0x00, 0x00,
  0x00, 0x00, 0x00, 0x00, 0x00, 0x00, 0x64, 0x43, 0xf1, 0xb4, 0x80, 0x00, 0x00, 0x00, 0x00, 0x00,
  0x00, 0x00, 0x00, 0x00, 0x00, 0x00, 0x49, 0x9c, 0x0e, 0x52, 0x00, 0x00, 0x00, 0x00, 0x00, 0x00,
  0x00, 0x00, 0x00, 0x00, 0x00, 0x00, 0x91, 0x20, 0xe1, 0x6a, 0x00, 0x00, 0x00, 0x00, 0x00, 0x00,
  0x00, 0x00, 0x00, 0x00, 0x00, 0x00, 0x92, 0x4f, 0x18, 0xad, 0x00, 0x00, 0x00, 0x00, 0x00, 0x00,
  0x00, 0x00, 0x00, 0x00, 0x00, 0x01, 0x24, 0x90, 0x06, 0xd5, 0x00, 0x00, 0x00, 0x00, 0x00, 0x00,
  0x00, 0x00, 0x00, 0x00, 0x00, 0x01, 0x25, 0xa7, 0xf9, 0x5a, 0x80, 0x00, 0x00, 0x00, 0x00, 0x00,
  0x00, 0x00, 0x00, 0x00, 0x00, 0x01, 0x09, 0x48, 0x0c, 0xaa, 0x80, 0x00, 0x00, 0x00, 0x00, 0x00,
  0x00, 0x00, 0x00, 0x00, 0x00, 0x03, 0x4a, 0xd1, 0x02, 0xab, 0xc0, 0x00, 0x00, 0x00, 0x00, 0x00,
  0x00, 0x00, 0x00, 0x00, 0x00, 0x02, 0x52, 0xa7, 0x19, 0x55, 0x40, 0x00, 0x00, 0x00, 0x00, 0x00,
  0x00, 0x00, 0x00, 0x00, 0x00, 0x02, 0x92, 0xa8, 0x09, 0x55, 0x40, 0x00, 0x00, 0x00, 0x00, 0x00,
  0x00, 0x00, 0x00, 0x00, 0x00, 0x02, 0x95, 0x53, 0xc4, 0xd5, 0x40, 0x00, 0x00, 0x00, 0x00, 0x00,
  0x00, 0x00, 0x00, 0x00, 0x00, 0x02, 0xa5, 0x52, 0x24, 0xba, 0xc0, 0x00, 0x00, 0x00, 0x00, 0x00,
  0x00, 0x00, 0x00, 0x00, 0x00, 0x03, 0x25, 0x74, 0x10, 0xaa, 0x00, 0x00, 0x00, 0x00, 0x00, 0x00,
  0x00, 0x00, 0x00, 0x00, 0x00, 0x05, 0x25, 0x65, 0x90, 0xa9, 0x40, 0x00, 0x00, 0x00, 0x00, 0x00,
  0x00, 0x00, 0x00, 0x00, 0x00, 0x05, 0x21, 0x69, 0x52, 0xa4, 0x80, 0x00, 0x00, 0x00, 0x00, 0x00,
  0x00, 0x00, 0x00, 0x00, 0x00, 0x01, 0x4a, 0xea, 0x50, 0x94, 0x00, 0x00, 0x00, 0x00, 0x00, 0x00,
  0x00, 0x00, 0x00, 0x00, 0x00, 0x01, 0x4a, 0xea, 0xa4, 0xf3, 0xc0, 0x00, 0x00, 0x00, 0x00, 0x00,
  0x00, 0x00, 0x00, 0x00, 0x00, 0x02, 0x4a, 0xcb, 0xe5, 0xfc, 0x00, 0x00, 0x00, 0x00, 0x00, 0x00,
  0x00, 0x00, 0x00, 0x00, 0x00, 0x02, 0xd2, 0xc3, 0x49, 0x97, 0xc0, 0x00, 0x00, 0x00, 0x00, 0x00,
  0x00, 0x00, 0x00, 0x00, 0x00, 0x04, 0x95, 0x56, 0x92, 0xf8, 0x00, 0x00, 0x00, 0x00, 0x00, 0x00,
  0x00, 0x00, 0x00, 0x00, 0x00, 0x00, 0x95, 0x51, 0x24, 0xdf, 0xc0, 0x00, 0x00, 0x00, 0x00, 0x00,
  0x00, 0x00, 0x00, 0x00, 0x00, 0x03, 0x2a, 0xa6, 0xc8, 0xdd, 0xc0, 0x00, 0x00, 0x00, 0x00, 0x00,
  0x00, 0x00, 0x00, 0x00, 0x00, 0x00, 0x4b, 0xad, 0x94, 0xef, 0x00, 0x00, 0x00, 0x00, 0x00, 0x00,
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
};  // vengono stabiliti quali pixels devono rimanere accesi o spenti sigolarmente con il codice esadecimale

// qui utilizzo un vettore contenente tutti le mie immagini (totali:1)
const int myBitmapallArray_LEN = 1;
const unsigned char* myBitmapallArray[1] = {
  myBitmapdownload
};

#define BUZZER 15         //definisco il pin a cui il cicalino è connesso
ezBuzzer buzzer(BUZZER);  // creo l'oggetto buzzer utile all'utilizzo della libreria ezBuzzer (che non utilizza alcun delay)

#define RIGHE 4    // griglia keypad righe
#define COLONNE 3  // griglia keypad colonne

#define SUONO_OK 19     // definisco il pin per il quale l'esp32 dovrà mettere un segnale alto se il codice è corretto
#define OK_IMPRONTE 34  // definisco il pin per il quale se l'esp32 rileva che il sensore di impronte digitali ha rilevato una impronta registrata, allora apro la serratura
#define SUONO_noOK 2    // definisco il pin per il quale l'esp32 dovrà mettere un segnale alto se il codice NON è corretto

#define PIN_RX 16  // pin LoRa
#define PIN_TX 17
#define PIN_M0 4
#define PIN_M1 23
#define PIN_AX 5

struct DATA {         // struttura dati da inviare o ricevere (deve essere contenuta in tutti e due i moduli)
  bool aperto;        // con "aperto" capisco se la valigia è stata aperta 0 = chiusa / 1 = aperta
  String passwordTX;  // "passwordTX" è la password trasmessa. Una password ogni volta che viene aperta la valigia
  bool connesso;      // "connesso" mi permette di capire se sono ancora connesso all'altro modulo
};

int Chan;     // variabile canale, per cambiare frequenza. Il modulo è stato impostato sul canale 17 => 433MHz (Frequenza base) + 17MHz = 450MHZ
DATA MyData;  // rinomino la struttura dati

unsigned long Last, noconnected;  // questi sono tre timer utili per controlli
long t = 0;

EBYTE Transceiver(&Serial2, PIN_M0, PIN_M1, PIN_AX);  // creo l'oggetto trasmettitore

char keys[RIGHE][COLONNE] = {  // creo una matrice del valore di ogni pin della tastiera
  { '1', '2', '3' },
  { '4', '5', '6' },
  { '7', '8', '9' },
  { '*', '0', '#' }
};

byte pin_righe[RIGHE] = { 33, 25, 26, 27 };  // definisco per quali pin corrispondono ogni riga e colonna
byte pin_colonne[COLONNE] = { 14, 12, 13 };
Keypad keypad = Keypad(makeKeymap(keys), pin_righe, pin_colonne, RIGHE, COLONNE);  // creo l'oggetto keypad

void setup() {
  pinMode(SUONO_OK, OUTPUT);  //definisco output e input
  pinMode(SUONO_noOK, OUTPUT);
  pinMode(OK_IMPRONTE, INPUT);
  Serial.begin(9600);  //inizializzo tutti i seriali, display e modulo LoRa
  Serial2.begin(9600);
  Serial.println("Starting Reader");

  display.begin(i2c_Address, true);
  display.display();  // ogni volta che disegno
  delay(1000);
  // Clear the buffer.
  display.clearDisplay();
  display.println("");
  display.display();
  Transceiver.init();
  Transceiver.PrintParameters();
}

String password = "1234";              // stringa password a cui viene dato un primo pin per iniziare tutto
String input_password = "";            // la stringa input password è la password digitata
bool nobuono;                          // "nobuono" mi dice se siamo connessi o meno all'altro modulo LoRa
unsigned long int timer_impronta = 0;  // timer multitasking per la visualizzazione di immagini
unsigned long int scritta = 0;
unsigned long int delei = 0;
unsigned long int vario = 0;
bool apro = false;
bool welc = false;
bool incpass = false;
void loop() {
  buzzer.loop();
  if (Serial2.available()) {  // se leggo dei dati sulla porta seriale -> allora estrapolo le informazioni
    Transceiver.GetStruct(&MyData, sizeof(MyData));
    Serial.print("password: ");
    Serial.println(MyData.passwordTX);
    password = MyData.passwordTX;  // la password presa dalla struttura dati acquisita sarà = a quella da utilizzare
    Last = millis();
  } else {
    if ((millis() - Last >= 7000) and MyData.connesso == false) {
      if (millis() - noconnected >= 500) {  // altrimenti se non ricevo nulla da 7 secondi E non siamo connessi -> allora vengo avvisato di utilizzare le impronte digitali e che ho perso la connessione
        noconnected = millis();
        Serial.println("not connected");
        nobuono = true;  // aggiungi micro pin
        if (millis() - scritta >= 5000) {
          scritta = millis();
          display.clearDisplay();  // clear display
          display.display();
          display.setTextSize(1);
          display.setTextColor(SH110X_WHITE);
          display.setCursor(0, 0);
          display.println("CONNESSIONE PERSA");

          display.setTextSize(2);
          display.setTextColor(SH110X_WHITE);
          display.setCursor(0, 0);
          display.print("             LOST   ");
          display.println("CONNECTION");
          display.setTextSize(1);
          display.println("Use fingerprint...");
          display.display();
        }
        if (millis() - timer_impronta >= 10000) {
          timer_impronta = millis();
          display.clearDisplay();
          display.display();
          display.drawBitmap(0, 0, myBitmapdownload, 128, 64, SH110X_WHITE);
          display.display();
        }
      }
    } else {
      MyData.connesso = false;
      nobuono = false;
    }
  }

  char key = keypad.getKey();    // leggi il pulsante premuto
  if (nobuono == false) {        // solo se siamo connessi eseguo il controllo sul tastierino
    if (key) {
      buzzer.beep(100);  //fai un beep (non utilizza delay)
      Serial.println(key);
      if (key == '#') {
        if (input_password == password) {  // se la password è corretta -> allora scrivi sul display Benvenuto e apri la valigia
          display.clearDisplay();
          Serial.println("password corretta");
          digitalWrite(SUONO_OK, 1);
          display.setTextSize(2);
          display.setTextColor(SH110X_WHITE);
          display.setCursor(0, 0);
          display.println("Welcome Mr");
          display.println(" Minguzzi");
          display.display();
          delei = millis();
          apro = true;
          welc = true;
          vario = millis();
          // apro serratura
        } else {  // altrimenti dimmi che la password non era giusta
          display.clearDisplay();
          Serial.println("password incorretta");  // mettere musichetta di micro
          display.setTextSize(2);
          display.setTextColor(SH110X_WHITE);
          display.setCursor(0, 0);
          display.println(" INCORRECT");
          display.println(" PASSWORD");
          display.display();
          digitalWrite(SUONO_noOK, 1);
          delay(500);
          digitalWrite(SUONO_noOK, 0);
          Serial.println(input_password);
          Serial.println(password);
          vario = millis();
          incpass = true;
        }
        input_password = "";  // reset input password
      } else {
        input_password += key;  // metti nuovo cartattere e mostramelo sul display
        display.clearDisplay();
        display.setTextSize(4);  // ci stanno10 caratteri su due righe e 5 su. una
        display.setTextColor(SH110X_WHITE);
        display.setCursor(0, 0);
        display.print(input_password);
        display.display();
      }
    }
  }
  
    if (millis() - delei >= 1000 and apro) {
    apro = false;
    digitalWrite(SUONO_OK, 0);
    MyData.aperto = true;  //dico che è stata aperta la valigia e lo trasmetto all'altro modulo attendendo una nuova password
    Transceiver.SendStruct(&MyData, sizeof(MyData));
  }

  if((nobuono == false) and (millis()- vario >= 7000) and (incpass or welc)){
    incpass = false;
    welc = false;
    display.clearDisplay();
    display.display();
  }

  if (nobuono) {                     // se non siamo connessi utilizzo le impronte digitali
    if (digitalRead(OK_IMPRONTE)) {  // se leggo che dall'arduino micro sono state rilevate delle impronte giuste
      digitalWrite(19, 1);           // apro serratura
      delay(1000);
      digitalWrite(19, 0);
      nobuono = false;  // questa operazione vale solo una volta
      Serial.println("apero");
    }
  }
}

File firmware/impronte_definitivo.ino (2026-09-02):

#include <Adafruit_Fingerprint.h> // libreria per l'utilizzo delle impronte digitali
#include <HardwareSerial.h> // libreria per l'utilizzo delle orte seriali hardware

#define buzzer 5 // definisco il pin per il mio buzzer
#define SUONO_OK 33 // definisco il pin per cui se rilevo un 1 dall'esp32 allora parte una musichetta felice
#define OK_IMPRONTE 27 // definisco il pin per cui se rilevo un'impronta giusta lo riporto all'esp32
#define SUONO_noOK 25 // definisco il pin per cui se rilevo un 1 dall'esp32 allora parte un suono triste

Adafruit_Fingerprint finger = Adafruit_Fingerprint(&Serial2); // creo l'oggetto sesnsore di impronte digitali che punta alla seriale 1

unsigned long t = 0; // temporizzatore multitasking
void setup() {
Serial.begin(9600); // inizializzo i seriali
while (!Serial)
; 
delay(100);
Serial.println("\n\nAdafruit Fingerprint sensor enrollment");
finger.begin(57600);

pinMode(25, INPUT); // definisco input e output
pinMode(33, INPUT);
pinMode(27, OUTPUT);
millis();
}

bool impronta_ok;

void loop() {
if (digitalRead(SUONO_OK)) { // se l'esp32 mi comunica che il codice digitato sulla tastierà è giusto -> motivo felice
tone(buzzer, 1480, 80);
delay(240);
tone(buzzer, 1480, 40);
delay(120);
tone(buzzer, 1480, 40);
delay(120);
tone(buzzer, 1976, 1000);
}
if (digitalRead(SUONO_noOK)) { // se l'esp32 mi comunica che il codice digitato sulla tastierà è sbagliata -> suono triste
tone(buzzer, 1976, 200);
delay(100);
tone(buzzer, 1480, 200);
}
if (millis() - t >= 100) { // ogni 100ms cerco un'impronta sul sensore
t = millis();
impronta_ok = fingerprintMatches(); // "impronta ok" sarà true per una impronta trovata o false se l'immagine è scarsa o non è un'impronta registrata
}
if (impronta_ok) { // se trovo un'impronta -> motivo felice
digitalWrite(OK_IMPRONTE, 1); // comunixo all'esp32 che è stata trovata un'impronta
tone(buzzer, 1480, 80);
delay(240);
tone(buzzer, 1480, 40);
delay(120);
digitalWrite(OK_IMPRONTE, 0);
tone(buzzer, 1480, 40);
delay(120);
tone(buzzer, 1976, 1000);
}
}

bool fingerprintMatches() {
uint8_t result = finger.getImage();
if (result != FINGERPRINT_OK) {
return false;
}
result = finger.image2Tz();
if (result != FINGERPRINT_OK) {
return false;
}
result = finger.fingerSearch();
if (result != FINGERPRINT_OK) {
tone(buzzer, 1976, 200);
delay(100);
tone(buzzer, 1480, 200);
return false;
}
return true;
}

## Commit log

2026-09-02 Update print statement from 'Hello' to 'Goodbye'
2026-09-02 Update LM7805CT regulator entry with thermal paste
    Added thermal paste to the LM7805CT regulator description.
2026-09-02 Update hardware documentation for ESP32 and key switch
    Clarified comments regarding the ESP32 and Arduino Micro distinction, updated important caveats about wiring, and refined explanations about the key switch and fingerprint enrollment process.
2026-09-02 Revise README by removing MOSFET advice and updating lessons
    Removed section on using logic-level MOSFETs and added lessons learned about measurements, failures, and debugging.
2026-09-03 Rename Screenshot 2026-09-02 alle 16.43.44.png to all-pcb
2026-09-03 Rename Screenshot 2026-09-02 alle 16.44.27.png to back-of-pcb.png
2026-09-03 Rename Screenshot 2026-09-02 alle 16.44.17.png to front-of-pcb.png
2026-09-03 Rename Screenshot 2026-09-02 alle 16.43.57.png to back-layer+ground-plane.png
2026-09-03 Rename Screenshot 2026-09-02 alle 16.43.50.png to front-layer+groundplane.png
